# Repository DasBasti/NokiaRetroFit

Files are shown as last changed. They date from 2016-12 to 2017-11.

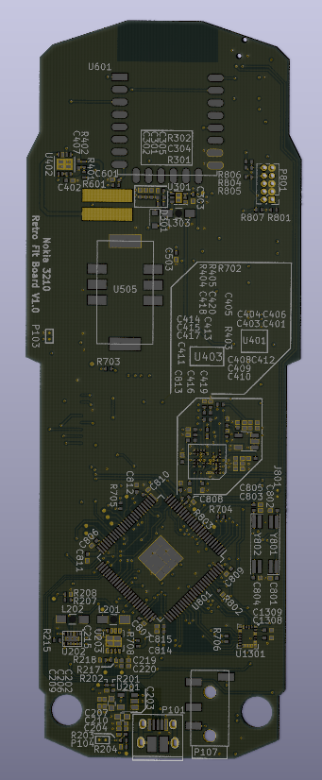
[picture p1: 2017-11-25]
Documentation/Pictures/backside_render_no_componets.png

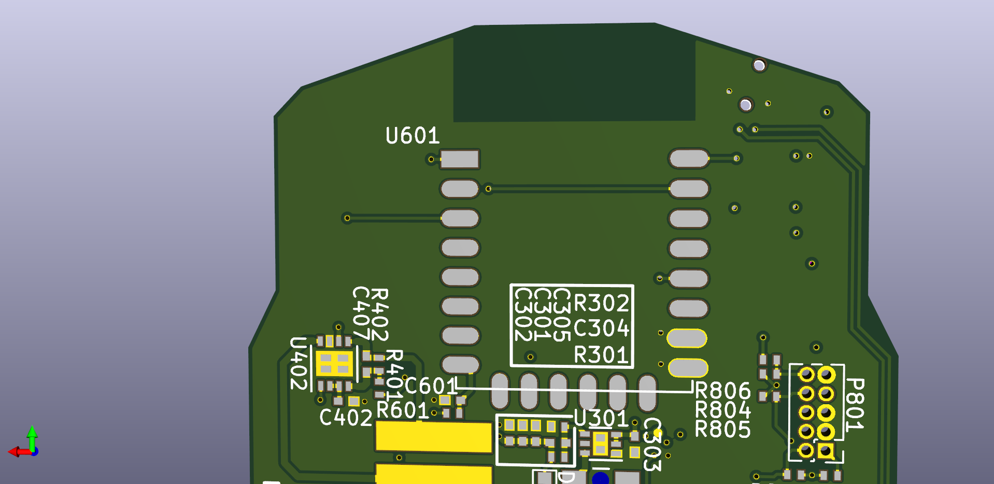
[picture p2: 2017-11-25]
Documentation/Pictures/wifi_part.png

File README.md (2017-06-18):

# Nokia 3210 Retro Fit
Retrofitting a Nokia 3210 with new dual ARM core CPU

* 1GHz dual core CPU
* 1GB DDR3 RAM
* 8GB Memory
* Android N (N7.1.1_1.0.0)

# Status
	[---------100%] BOM generation  
	[--------80%--] Development of schematics / System design  
	[-----50%-----] Pinmuxing of i.MX7  
	[5%-----------] Board layout  
	[0%-----------] Android port  
	[0%-----------] Android applications

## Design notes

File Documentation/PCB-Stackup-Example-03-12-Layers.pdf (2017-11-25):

StackName: iMX6_Rex_V1I1_PCB_12L_VT47_mv | Version: 1 | Revision: | Modification: | Date of Revision: | Editor | Page 1/3
Date: 31/10/2013 | Associated Documents:

Author: DM
Department: IDS
Site: Tewkesbury

Copyright ©

www.polarinstruments.com

Soldermask | 0.020 | SolderMask | 4.100 | 10
1 | Foil | 1, 2, 3 | 0.012 | 0.035 | Foil | 0
VT47-1080 | 0.075 | 0.075 | PREPREG | 4.000
2 | Foil | | 0.009 | 0.032 | Foil | 0
VT47-106 | 0.053 | 0.053 | PREPREG | 4.000
VT47-106 | 0.053 | 0.053 | PREPREG | 4.000
3 | | 4, 5, 6 | 0.018 | 0.035
VT-47 | 0.203 | 0.203 | Core | 4.600
4 | | | 0.018 | 0.018
VT47-2113 | 0.096 | 0.096 | PREPREG | 4.000
5 | | | 0.018 | 0.018
VT-47 | 0.102 | 0.102 | Core | 4.120
6 | | | 0.018 | 0.018
VT47-106 | 0.053 | 0.053 | PREPREG | 4.000
VT47-106 | 0.053 | 0.053 | PREPREG | 4.000
7 | | | 0.018 | 0.018
VT-47 | 0.102 | 0.102 | Core | 4.120
8 | | | 0.018 | 0.018
VT47-2113 | 0.096 | 0.096 | PREPREG | 4.000
9 | | | 0.018 | 0.018
VT-47 | 0.203 | 0.203 | Core | 4.600
10 | | 7, 8, 9 | 0.018 | 0.035
VT47-106 | 0.053 | 0.053 | PREPREG | 4.000
VT47-106 | 0.053 | 0.053 | PREPREG | 4.000
11 | Foil | | 0.009 | 0.032 | Foil | 0
VT47-1080 | 0.075 | 0.075 | PREPREG | 4.000
12 | Foil | 10, 11, 12 | 0.012 | 0.035 | Foil | 0
Soldermask | 0.020 | SolderMask | 4.100 | 10

1.6 +0.0 / -0.0

1 | Coated Microstrip 1B | 1 | 2 | 0 | 0.093 | 0.000 | 0.000 | 55.000 | 55.060 | 10.000
2 | Edge Coupled Coated Microstrip 1B | 1 | 2 | 0 | 0.101 | 0.114 | 0.000 | 90.000 | 90.060 | 10.000
3 | Edge Coupled Coated Microstrip 1B | 1 | 2 | 0 | 0.090 | 0.160 | 0.000 | 100.000 | 100.300 | 10.000
4 | Offset Stripline 1B1A | 3 | 2 | 4 | 0.080 | 0.000 | 0.000 | 55.000 | 53.620 | 10.000

StackName: iMX6_Rex_V1I1_PCB_12L_VT47_mv | Version: 1 | Revision: | Modification: | Date of Revision: | Editor | Page 2/3
Date: 31/10/2013 | Associated Documents:

Author: DM

5 | Edge Coupled Offset Stripline 1B1A | 3 | 2 | 4 | 0.085 | 0.115 | 0.000 | 90.000 | 88.390 | 10.000
6 | Edge Coupled Offset Stripline 1B1A | 3 | 2 | 4 | 0.085 | 0.195 | 0.000 | 100.000 | 98.390 | 10.000
7 | Offset Stripline 1B1A | 10 | 9 | 11 | 0.080 | 0.000 | 0.000 | 55.000 | 53.620 | 10.000
8 | Edge Coupled Offset Stripline 1B1A | 10 | 9 | 11 | 0.085 | 0.115 | 0.000 | 90.000 | 88.390 | 10.000
9 | Edge Coupled Offset Stripline 1B1A | 10 | 9 | 11 | 0.085 | 0.195 | 0.000 | 100.000 | 98.390 | 10.000
10 | Coated Microstrip 1B | 12 | 11 | 0 | 0.093 | 0.000 | 0.000 | 55.000 | 55.060 | 10.000
11 | Edge Coupled Coated Microstrip 1B | 12 | 11 | 0 | 0.101 | 0.114 | 0.000 | 90.000 | 90.060 | 10.000
12 | Edge Coupled Coated Microstrip 1B | 12 | 11 | 0 | 0.090 | 0.160 | 0.000 | 100.000 | 100.300 | 10.000
1 | 12 | Mechanical PTH | 0.000 | None
1 | 2 | Laser PTH | 0.100 | None
2 | 3 | Laser PTH | 0.100 | None
12 | 11 | Laser PTH | 0.100 | None
11 | 10 | Laser PTH | 0.100 | None

StackName: iMX6_Rex_V1I1_PCB_12L_VT47_mv | Version: 1 | Revision: | Modification: | Date of Revision: | Editor | Page 3/3
Date: 31/10/2013 | Associated Documents:

Author: DM

3 | 10 | Mechanical PTH | 0.200 | None

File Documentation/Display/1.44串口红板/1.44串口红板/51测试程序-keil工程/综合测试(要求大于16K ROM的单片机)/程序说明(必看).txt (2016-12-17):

测试程序功能
开机显示中文，英文，图片

修改LCD数据脚连接IO在lcd.h文件中
40*40图片数据和95个ASCCII字符数据和测试汉字取模数据在font.c文件中

/* 
程序默认IO连接方式：
sbit LCD_CS     =P0^0;     //片选	
sbit LCD_AO     =P0^2;	  //数据/命令切换
sbit LCD_SDA    =P1^5;	  //数据
sbit LCD_SCK    =P1^7;	  //时钟
sbit LCD_REST   =P0^1;	  //复位  
*/

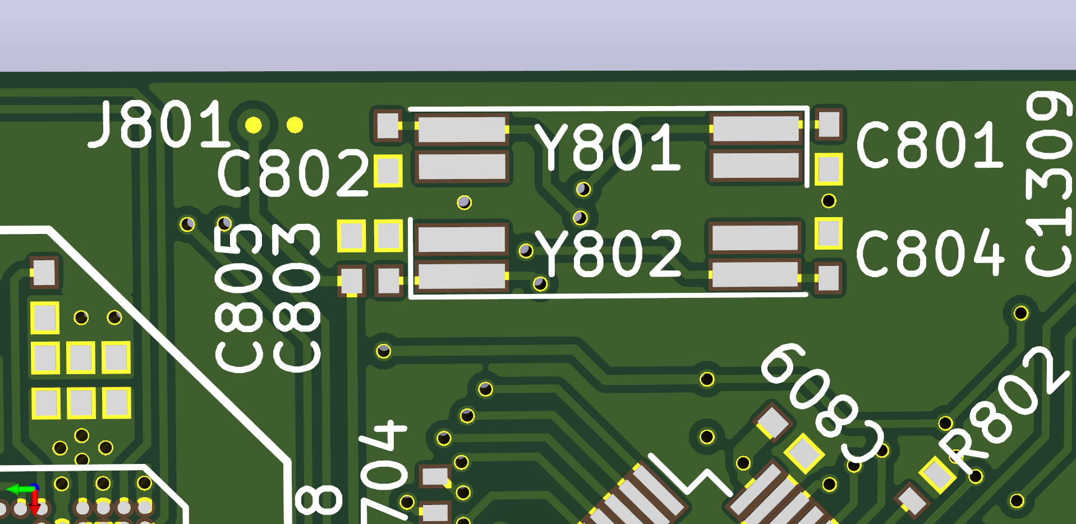
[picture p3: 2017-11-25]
Documentation/Pictures/crystals_part.png

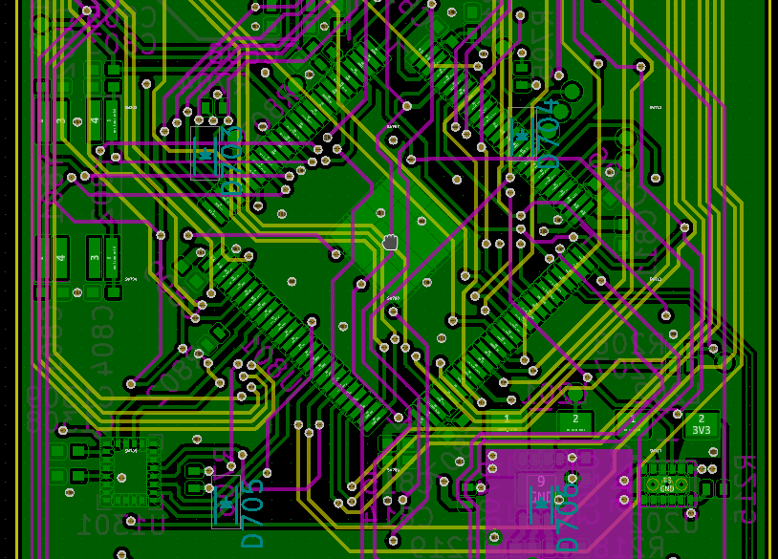
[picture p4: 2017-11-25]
Documentation/Pictures/CPU_part.png

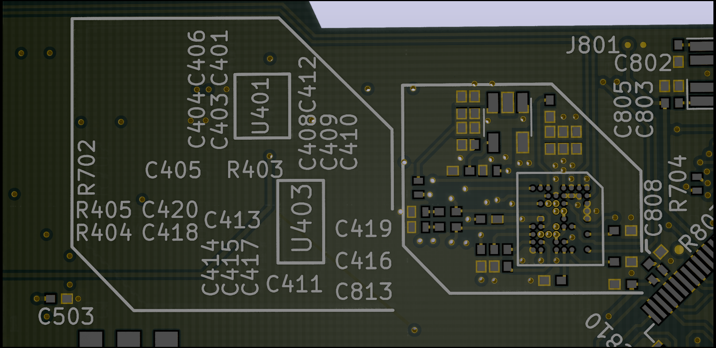
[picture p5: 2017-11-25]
Documentation/Pictures/BGA_part.png

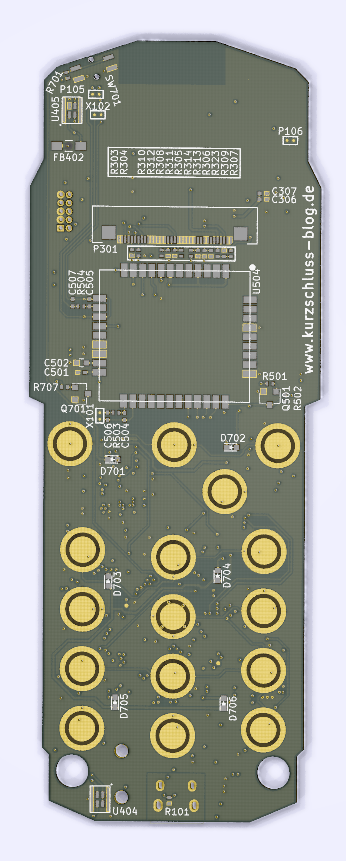
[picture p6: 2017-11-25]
Documentation/Pictures/frontside_render_no_componets.png

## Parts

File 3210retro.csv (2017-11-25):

Id | Designator | Package | Quantity | Designation | Supplier and ref
1 | Y802 | Crystal_SMD_ABM11W_4_D1X_T_-4pin_2.0x1.6mm | 1 | 24MHz
2 | P107 | PJ_320_D | 1 | HEADPHONE
3 | J801 | SolderWirePad_2x_0,8 | 1 | TEST_2P
4 | P103 | SolderWirePad_2x_0,8 | 1 | LIPO
5 | P104 | SolderWirePad_2x_0,8 | 1 | DC
6 | X101 | SolderWirePad_2x_0,8 | 1 | ANT_GPS
7 | X102 | SolderWirePad_2x_0,8 | 1 | ANT_GSM
8 | U505 | SIM | 1 | SIM_SLOT
9 | SW702 | Foil_Button | 1 | C
10 | SW703 | Foil_Button | 1 | 1
11 | SW704 | Foil_Button | 1 | 4ghi
12 | SW705 | Foil_Button | 1 | 7pqrs
13 | SW706 | Foil_Button | 1 | -
14 | SW707 | Foil_Button | 1 | 2abc
15 | SW708 | Foil_Button | 1 | 5jkl
16 | SW709 | Foil_Button | 1 | 8tuv
17 | SW710 | Foil_Button | 1 | UP
18 | SW711 | Foil_Button | 1 | 3def
19 | SW712 | Foil_Button | 1 | 6mno
20 | SW713 | Foil_Button | 1 | 9wxyz
21 | SW714 | Foil_Button | 1 | *+
22 | SW715 | Foil_Button | 1 | DOWN
23 | SW716 | Foil_Button | 1 | 0space
24 | SW717 | Foil_Button | 1 | #up
25 | TP101,TP201,TP202,TP203,TP204,TP205,TP206,TP301,TP501,TP102,TP103,TP104,TP105,TP106,TP107,TP108,TP109,TP110,TP111,TP112,TP114 | TP | 21 | TP
26 | P801 | Pin_Header_Straight_2x05_Pitch1.27mm | 1 | JTAG
27 | SW701 | TS-015A | 1 | SW_PUSH
28 | U404,U405 | MP34DT01_NoGroundRing | 2 | MP34DT01TR
29 | U202 | TPS6274x | 1 | TPS62742
30 | U203 | Texas_S-PVSON-N8_NoThermalVias | 1 | TPS61021A
31 | R807,R215,R323,R701,R802,R803,R804,R805,R205 | R_0402_NoSilk | 9 | 10k
32 | U504 | A7 | 1 | A7
33 | U1301 | LGA-24L_3x3.5mm_Pitch0.43mm | 1 | LSM9DS1
34 | D701,D702,D703,D704,D705,D706 | LED_0603 | 6 | LED
35 | P108 | Rumble_Pads | 1 | RUMBLE
36 | P101 | USB_Micro-B_10103594-0001LF | 1 | USB_OTG
37 | P301 | FFC-05-35 | 1 | SEPS525
38 | U601 | ESP-12E | 1 | ESP-12E
39 | C306,C307,C206,C207,C215,C301,C302,C401,C403,C408,C409,C410,C414,C415,C419,C420,C501,C503,C601,C805,C808,C809,C810,C811,C812,C813,C814,C1309,C421,C423 | C_0402_NoSilk | 30 | 100n
40 | C202,C203 | C_0603 | 2 | 10u
41 | C204,C504,C505,C506,C507 | C_0402_NoSilk | 5 | C
42 | C209,C210 | C_0402_NoSilk | 2 | 1n
43 | C219,C801,C802,C803,C804 | C_0402_NoSilk | 5 | 22p
44 | C220,C305,C815 | C_0402_NoSilk | 3 | 1u
45 | C303 | C_0402_NoSilk | 1 | 4u7C
46 | C304 | C_0402_NoSilk | 1 | 10p
47 | C402,C407,C1308 | C_0402_NoSilk | 3 | 10n
48 | C404,C405,C406 | C_0402_NoSilk | 3 | 470n
49 | C411 | C_0402_NoSilk | 1 | 4u7
50 | C412,C413,C416,C417 | C_0402_NoSilk | 4 | 10u
51 | C418,C422 | C_0402_NoSilk | 2 | 22u
52 | C502 | C_0603 | 1 | 470u
53 | C806,C807 | C_0402_NoSilk | 2 | 2u2
54 | FB402 | Choke_SMD_1206_Standard | 1 | FILTER
55 | L201 | Choke_SMD_1206_Standard | 1 | 4u7 / 3A
56 | L202 | Choke_SMD_1206_Standard | 1 | 2u2
57 | L303 | Choke_SMD_1206_Standard | 1 | 18u
58 | Q501,Q701 | SOT-23 | 2 | MMBF170
59 | R101,R503,R504,R601,R801,R806,R403,R404 | R_0402_NoSilk | 8 | 0
60 | R201,R202,R203,R204,R207,R208,R217,R218 | R_0402_NoSilk | 8 | R
61 | R301 | R_0402_NoSilk | 1 | 2M2
62 | R302 | R_0402_NoSilk | 1 | 162k
63 | R303 | R_0402_NoSilk | 1 | 68k
64 | R304 | R_0402_NoSilk | 1 | 5k1
65 | R305,R306,R307,R310,R311 | R_0402_NoSilk | 5 | 560
66 | R308,R309,R312,R313,R314 | R_0402_NoSilk | 5 | 1k
67 | R401,R402 | R_0402_NoSilk | 2 | 50k
68 | R501 | R_0402_NoSilk | 1 | 22
69 | R502 | R_0402_NoSilk | 1 | 100
70 | R702,R703,R704,R705,R706,R707,R708 | R_0402_NoSilk | 7 | 280
71 | U201 | SOT-23-5 | 1 | MAX1555
72 | U801 | TQFP-100-1EP_14x14mm_Pitch0.5mm | 1 | STM32F756VGTx
73 | D301 | D_0805 | 1 | D_Schottky
74 | U402 | DFN-8-1EP_3x3mm_Pitch0.65mm | 1 | DRV8601
75 | J1101 | microSD_Card_Receptacle_Wuerth_693072010801 | 1 | MICRO_SD_HINGE
76 | Y801 | Crystal_SMD_2012-2pin_2.0x1.2mm | 1 | 32kHz
77 | U301 | DFN-6-1EP_2x2mm_Pitch0.65mm | 1 | TPS61041DBV
78 | R102,R103 | R_0402_NoSilk | 2 | 4k7
79 | U401 | QFN-24-1EP_4x4mm_Pitch0.5mm | 1 | TLV320ADC3101
80 | U403 | QFN-32-1EP_5x5mm_Pitch0.5mm | 1 | TLV320DAC3100
81 | P106 | SolderWirePad_2x_0,8 | 1 | SPEAKER
82 | R206 | R_0603 | 1 | 0

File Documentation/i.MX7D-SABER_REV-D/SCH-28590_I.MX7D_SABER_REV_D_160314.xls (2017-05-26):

MCIMX7D-SABRE Revised: Sunday, March 13, 2016
SOURCE:SCH-28590:SPF-28590 Revision: D
Freescale Semiconductor
6501 William Cannon Drive West
Austin, TX 78735-8598
Bill Of Materials May 5,2016 17:49:32
Item | Quantity | Reference | Value | MFG_NAME01 | Description | MFG_PN01 | Tolerance | Assy_Opt
______________________________________________
1 | 9 | C1,C198,C199,C202,C203, | 100uF |  | TCAP,100UF,+/-10%,6.3V,SMD1210(B)
 |  | C204,C274,C275,C438
2 | 11 | C2,C4,C10,C56,C57,C257, | 22uF |  | CAP,22UF,+80%/-20%,Y5V,10V,SMD0805
 |  | C259,C261,C363,C418,C439
3 | 47 | C3,C20,C21,C22,C29,C58, | 1uF |  | CAP,1UF,+/-10%,X5R,10V,SMD0402
 |  | C59,C61,C194,C220,C221,
 |  | C276,C277,C308,C309,C310,
 |  | C311,C313,C315,C316,C317,
 |  | C318,C324,C326,C327,C329,
 |  | C331,C333,C334,C336,C338,
 |  | C340,C341,C342,C343,C345,
 |  | C377,C382,C387,C392,C393,
 |  | C411,C412,C414,C426,C427,
 |  | C428
4 | 103 | C5,C7,C11,C12,C13,C60, | 220nF |  | CAP,220NF,+/-10%,X5R,10V,SMD0402
 |  | C63,C64,C66,C68,C69,C70,
 |  | C71,C72,C74,C75,C78,C79,
 |  | C80,C81,C82,C83,C84,C86,
 |  | C88,C90,C92,C93,C94,C98,
 |  | C99,C101,C104,C107,C108,
 |  | C110,C117,C118,C119,C122,
 |  | C124,C125,C127,C129,C130,
 |  | C136,C137,C138,C139,C140,
 |  | C142,C143,C144,C145,C146,
 |  | C147,C149,C150,C151,C152,
 |  | C153,C154,C155,C157,C158,
 |  | C159,C160,C161,C162,C163,
 |  | C165,C166,C167,C168,C169,
 |  | C170,C171,C173,C174,C175,
 |  | C176,C177,C178,C179,C190,
 |  | C191,C192,C237,C241,C245,
 |  | C265,C278,C279,C280,C284,
 |  | C357,C376,C378,C380,C381,
 |  | C388,C389,C408
5 | 88 | C6,C24,C28,C30,C37,C42, | 100nF |  | CAP,100NF,+/-10%,X5R,10V,SMD0402
 |  | C46,C50,C52,C141,C181,
 |  | C182,C184,C185,C186,C187,
 |  | C196,C201,C206,C207,C208,
 |  | C209,C210,C211,C212,C213,
 |  | C216,C217,C222,C223,C227,
 |  | C229,C230,C231,C240,C246,
 |  | C247,C248,C249,C250,C251,
 |  | C253,C256,C258,C260,C262,
 |  | C264,C266,C267,C268,C271,
 |  | C300,C320,C322,C347,C348,
 |  | C351,C352,C359,C360,C361,
 |  | C365,C367,C368,C379,C384,
 |  | C385,C396,C404,C405,C407,
 |  | C409,C410,C415,C417,C419,
 |  | C444,C446,C448,C450,C451,
 |  | C453,C456,C457,C458,C459,
 |  | C460,C461
6 | 31 | C8,C9,C14,C16,C32,C33, | 22uF |  | CAP,22UF,+/-20%,X5R,6.3V,SMD0603
 |  | C34,C35,C38,C39,C40,C41,
 |  | C44,C45,C54,C55,C65,C73,
 |  | C85,C148,C156,C164,C172,
 |  | C180,C215,C225,C263,C344,
 |  | C346,C362,C390
7 | 8 | C15,C18,C394,C429,C430, | 10nF |  | CAP,10NF,+/-10%,X7R,25V,SMD0402
 |  | C431,C432,C433
8 | 2 | C17,C19 | 560pF |  | CAP,560PF,+/-5%,C0G,50V,SMD0402
9 | 26 | C23,C26,C49,C67,C76,C77, | 2.2uF |  | CAP,2.2UF,+/-20%,X5R,6.3V,SMD0402
 |  | C87,C89,C91,C95,C97,C100,
 |  | C109,C111,C115,C116,C120,
 |  | C126,C128,C131,C238,C254,
 |  | C255,C356,C374,C452
10 | 29 | C25,C27,C36,C43,C47,C48, | 4.7uF |  | CAP,4.7UF,+/-10%,X5R,10V,SMD0603
 |  | C51,C53,C96,C183,C188,
 |  | C189,C193,C200,C205,C228,
 |  | C232,C233,C235,C269,C270,
 |  | C272,C273,C354,C355,C386,
 |  | C445,C447,C449
11 | 4 | C31,C112,C113,C114 | 470nF |  | CAP,470NF,+/-10%,X5R,10V,SMD0402
12 | 16 | C62,C214,C218,C219,C224, | 10uF |  | CAP,10UF,+/-20%,X5R,6.3V,SMD0603
 |  | C252,C307,C319,C323,C325,
 |  | C328,C330,C332,C335,C337,
 |  | C413
13 | 23 | C102,C103,C105,C106,C197, | 18pF |  | CAP,18PF,+/-5%,C0G,50V,SMD0402
 |  | C243,C244,C349,C350,C366,
 |  | C391,C397,C398,C399,C400,
 |  | C401,C406,C420,C421,C422,
 |  | C423,C434,C435
14 | 4 | C121,C123,C358,C375 | 10uF |  | CAP,10UF,+/-10%,X5R,10V,SMD0603
15 | 3 | C195,C321,C416 | 47uF |  | CAP,47UF,+/-20%,X5R,6.3V,SMD0805
16 | 3 | C226,C239,C298 | 4.7uF |  | CAP,4.7UF,+/-10%,X5R,16V,SMD0603
17 | 5 | C242,C301,C302,C353,C395 | 100nF |  | CAP,100NF,+/-10%,X5R,25V,SMD0402
18 | 2 | C281,C282 | 56pF |  | CAP,56PF,+/-1%,C0G,50V,SMD0402 |  | 1%
19 | 3 | C283,C369,C370 | 1nF |  | CAP,1NF,+/-10%,X7R,50V,SMD0402
20 | 1 | C299 | 100uF |  | TCAP,100UF,+/-20%,10V,SMD1210(B)
21 | 1 | C383 | 33nF |  | CAP,33NF,+/-10%,X7R,16V,SMD0402
22 | 2 | C402,C403 | 10pF |  | CAP,10PF,+/-5%,C0G,50V,SMD0402
23 | 1 | C454 | 2.2uF |  | CAP,2.2UF,+/-10%,X5R,50V,SMD0805
24 | 1 | C455 | 100nF |  | CAP,100NF,+/-10%,X7R,50V,SMD0603
25 | 4 | D1,D6,D9,D11 | Green |  | LED,Brilliant Green,Water Clear,20mA,SMD0805
26 | 5 | D2,D7,D8,D10,D23 | RED |  | LED,Brilliant Red,Water Clear,20mA,SMD0805
27 | 6 | D3,D4,D16,D20,D25,D26 | 1N5819HW-7-F |  | Diode,Schottky Diode,1N5819HW-7-F,40V,1A,SOD-123,SMD
28 | 1 | D5 | ORG |  | LED,Brilliant Orange,Water Clear,20mA,SMD0805
29 | 2 | D12,D13 | LED |  | LED,Brilliant Orange,Water Clear,20mA,SMD0805
30 | 3 | D14,D15,D24 | BAT54A |  | Diode,Schottky Diode,BAT54AWT1G,30V,200mA,SOT-323
31 | 1 | D17 | MM5Z5V1ST1G |  | Diode,DIODE ZENER 5.1V 200MW SOD523
32 | 1 | D22 | BAT54S |  | Diode,Schottky Barrier(Double) Diodes,BAT54S,30V,200mA,SOT-23,SMD
33 | 1 | FL1 | LFB182G45SG9A272 |  | FILTER,BANDPASS 2.4GHZ WLAN,0603(5 pads),SMD
34 | 1 | F1 | FUSE |  | Fuse,F1206FA4000V032T,32V,4A,Fast Acting,0.022ohm,SMD1206
35 | 1 | JP1 | HTMS-103-02-G-S |  | Connector,Pin Header,Straight,Male,1x3Pin,1.27MM pitch,2.54,3.05,Gold Flash 10u,black,DIP
36 | 1 | J1 | CONN_DCPOWER |  | Connector,DC Jack,Right Angle,3Pin,2.0MM Center Pin,Tin Plated,Black,DIP
37 | 1 | J2 | CONN_BATIN |  | Connector,PH Series PCB Header,Straight,Male,1x2Pin,2.0MM pitch,Tin Plated, white,DIP
38 | 1 | J3 | CONN_BAT |  | Connector,Battery Holder for CR1220,brown,SMD
39 | 3 | J4,J5,J10 | CONN_Coaxial |  | Connector,Coaxial Connector,U.FL-R-SMT-1,6GHZ,SMD
40 | 1 | J6 | CONN_SD |  | Connector,SD Card CONN with detect switch, Gold Flash 3u,white,SMD
41 | 1 | J7 | CONN_SIM |  | Connector,SIM Card CONN,Gold Flash 1u,Black,16.35x15.7x2.6mm,SMD
42 | 1 | J8 | CONN_PCIe |  | Connector,MiniPCI Card CONN 2x26,Gold Flash 1u,Black,SMD
43 | 1 | J9 | CONN_HDMI |  | Connector,HDMI A port,FeMale,19 Position,Right Angle,Gold Flash 3u,black,SMD
44 | 2 | J11,J25 | CONN_USB |  | Connector,MicroUSB AB port,5 Position,Right Angle,Gold Flash 1u, black,SMD
45 | 1 | J12 | CONN_JTAG |  | Connector,Pin Header,Straight,Male,2x5Pin,1.27MM pitch,2.9mm,,Gold Flash 1u,black,SMD
46 | 1 | J13 | CONN_EPD | SAMTEC | Connector,Board to Baord, Female 120Pin,0.8MM Pitch, Gold Flash 10u,black,SMD | QSH-060-01-L-D-A
47 | 1 | J14 | CONN_LCD |  | Connector,FPC Connector,Right Angle,50Pin,0.5MM Pitch,Flip-Lock Type,Bottom Contact,2.0MM Height,Tin Plated, white,SMD
48 | 1 | J15 | CONN_HP |  | Connector,Audio Jack,Right Angle,3.5MM Plug Diameter,Gold Flash 1u,Green,DIP
49 | 1 | J16 | CONN_MIC |  | Connector,Audio Jack,Right Angle,3.5MM Plug Diameter,Gold Flash 1u,Pink,DIP
50 | 1 | J17 | CONN_SPEAKER | Townes | Connector,Pin Header,Straight,Male,1x4Pin,2.54MM pitch,6.06,3.00,Gold Flash 1u,black,DIP | P101-1*04SGF-116A-NG
51 | 1 | J18 | CONN_SMARTCARD |  | Connector,FPC Connector,Right Angle,14Pin,0.5MM Pitch,Flip-Lock Type,Bottom Contact,1.2MM Height,Tin Plated, white,SMD
52 | 1 | J19 | CONN_CAN |  | Connector,D-SUB with screwlock,Male,9 Position,Right Angle,Gold Flash,black,DIP
53 | 1 | J20 | CONN_MFI |  | Connector,Pin Socket,Straight,Female,2x5Pin,2.54MM pitch,8.5,3.00,Gold Flash 1u, black,DIP
54 | 1 | J22 | CONN_ADC |  | Connector,Pin Header,Straight,Male,2x4Pin,2.54MM pitch,5.80,,Gold Flash 1u, black,SMD
55 | 1 | J26 | CONN_USB |  | Connector,USB A port,4 Position,Right Angle Flag,Gold Flash 1u,white,DIP
56 | 2 | J27,J28 | CONN_RJ45 |  | Connector,RJ45 Jack with integrated magnetics and G/Y leds,Right Angle,1000M,Top contact,Gold Flash
57 | 1 | J29 | CONN_CSI |  | BTB Connector,Socket,AXT530124,30Pin,0.4MM Pitch,without bosses,Height 1.0mm,Ni+Au,panasonic,SMD
58 | 1 | J30 | CONN_DSI |  | BTB Connector,socket,Right Angle,24Pin,0.4MM Pitch,1.5MM Height,Au,Black,SMD
59 | 1 | J31 | CONN_TAMPER |  | Connector,Pin Header,Straight,Male,2x10Pin,1.27MM pitch,Gold Flash 30u,black,SMD
60 | 2 | J32,J33 | CONN_MikroBUS |  | Connector,Pin Socket,Straight,Female,1x8Pin,2.54MM pitch,8.5,3.2,Gold Flash 1u, black,DIP
61 | 6 | J36,J37,J38,J39,J40,J41 | CONN_JUMPER |  | Connector,Pin Header,Straight,Male,1x2Pin,1.27MM pitch,3,2,Gold Flash 1u, black,DIP
62 | 2 | L1,L2 | 2.2uH |  | Power Inductor,Magnetic shielded,2.2uH,IRMS=7A,ISAT=14A,0.02ohms,7.3x6.6x3mm,SMD
63 | 4 | L3,L4,L5,L7 | 1.5uH |  | Inductor ,1.5uH,60mOhms,3.5A +/-20% 2.5x2.0x1.2mm OPN:DFE252012P-1R5M=P2
64 | 1 | L6 | 2.2uH |  | Inductor,2.2uH 84mOhms3.0A +/-20% 2.5x2.0x1.2mm OPN:DFE252012P-2R2M=P2
65 | 12 | L8,L11,L12,L13,L50,L51, | 120 OHM@100MHZ |  | Ferrite Bead,120ohm@100MHz,+/-25%,1300mA,90mohm,SMD0402
 |  | L52,L63,L64,L65,L66,L68
66 | 7 | L10,L40,L41,L59,L60,L61, | WCM-2012-900T |  | Common Choke,90ohm@100MHz/20°C,±25%,450mA,0.3ohm,SMD0508
 |  | L62
67 | 24 | L14,L15,L19,L20,L21,L22, | 120 OHM@100MHZ |  | Ferrite Bead,120ohm@100MHz,+/-25%,1300mA,90mohm,SMD0402
 |  | L25,L26,L27,L28,L29,L30,
 |  | L31,L39,L42,L43,L45,L46,
 |  | L47,L48,L49,L53,L57,L58
68 | 4 | L16,L17,L55,L56 | 1nH |  | Inductor,1nH,Ir=400mA,RF=6GHz,Rdc=0.1 ohm,SMD0402
69 | 2 | L18,L67 | 2.2uH |  | Inductor,2.2uH,Ir=1.3A,RF=40MHz,Rdc=100m ohm,SMD1008
70 | 2 | L44,L54 | 4.7uH |  | Inductor,4.7uH,Ir=120mA,+/-20%,0.455ohm,SMD0805
71 | 4 | MG1,MG2,MG3,MG4 | MGX |  | STANDOFF,PHILIP FEMALE, ROUND HEAD,M2-0.4*5,COPPER ALLOY
72 | 3 | Q2,Q32,Q34 | AON3419 |  | Mosfet,P-Channel,AON3419,-30V,-10A,SOIC-8,SMD
73 | 8 | Q5,Q7,Q16,Q22,Q25,Q29, | 2N7002 |  | Mosfet,N-Channel,2N7002,60V,115mA,SOT-23,SMD
 |  | Q30,Q31
74 | 5 | Q6,Q10,Q13,Q21,Q24 | AO3407A |  | Mosfet,P-Channel,AO3407A,-30V,-4.3A,SOT-23,SMD
75 | 1 | Q8 | MMBT3904 |  | Transistor,NPN,MMBT3904,40V,200MA,SOT-23,SMD
76 | 1 | Q17 | MMBT2907 |  | Transistor,PNP,MMBT2907A-7-F,60V,600MA,SOT-23,SMD
77 | 1 | Q35 | BCM857BS |  | Transistor,DUAL PNP,BCM857BS,45V,100MA,SOT-363,SMD
78 | 1 | Q36 | DMN2005K-7 |  | Mosfet,N-Channel,2N7002,60V,115mA,SOT-23,SMD
79 | 6 | RN13,RN14,RN15,RN16,RN17, | 33R |  | RES 4 arrays,33R, +/-5%,1/16W,SMD0408
 |  | RN18
80 | 5 | RN19,RN20,RN21,RN22,RN23 | 10K |  | RES 4 Arrays,10K,+/-5%,1/16W,SMD0408
81 | 13 | R1,R4,R134,R161,R162, | 1K |  | RES,1K,+/-5%,1/16W,SMD0402
 |  | R166,R167,R295,R296,R309,
 |  | R310,R347,R623
82 | 26 | R6,R8,R15,R18,R35,R75, | 100K |  | RES,100K,+/-1%,1/16W,SMD0402
 |  | R152,R153,R154,R155,R156,
 |  | R254,R256,R280,R348,R354,
 |  | R539,R547,R549,R550,R551,
 |  | R561,R570,R584,R611,R614
83 | 89 | R9,R11,R28,R68,R87,R88, | 10K |  | RES,10K,+/-5%,1/16W,SMD0402
 |  | R89,R92,R93,R94,R97,R98,
 |  | R99,R100,R101,R104,R105,
 |  | R108,R135,R138,R139,R148,
 |  | R165,R168,R169,R170,R225,
 |  | R226,R228,R230,R232,R234,
 |  | R236,R239,R241,R242,R244,
 |  | R252,R253,R255,R257,R262,
 |  | R263,R275,R282,R294,R327,
 |  | R330,R331,R332,R333,R334,
 |  | R335,R336,R351,R353,R361,
 |  | R362,R363,R364,R367,R386,
 |  | R387,R472,R477,R489,R490,
 |  | R493,R498,R537,R543,R548,
 |  | R553,R602,R603,R604,R609,
 |  | R610,R612,R613,R615,R621,
 |  | R622,R628,R630,R631,R636,
 |  | R637,R640
84 | 1 | R10 | 75K |  | RES,75K,+/-1%,1/16W,SMD0402 |  | 1%
85 | 2 | R12,R16 | 12K7 |  | RES,12K7,+/-1%,1/16W,SMD0402
86 | 2 | R13,R17 | 24K |  | RES,24K,+/-1%,1/16W,SMD0402 |  | 1%
87 | 1 | R14 | 88K7 |  | RES,88K7,+/-1%,1/16W,SMD0402 |  | 1%
88 | 14 | R19,R90,R91,R127,R128, | 470R |  | RES,470R,+/-1%,1/16W,SMD0402
 |  | R129,R157,R264,R266,R267,
 |  | R268,R269,R270,R556
89 | 2 | R20,R24 | 0R |  | RES,0R,+/-5%,1/2W,SMD1206
90 | 189 | R23,R30,R31,R32,R45,R46, | 0R |  | RES,0R,+/-5%,1/16W,SMD0402
 |  | R65,R69,R76,R85,R102,
 |  | R117,R118,R119,R120,R124,
 |  | R125,R136,R147,R163,R171,
 |  | R172,R180,R181,R183,R184,
 |  | R185,R186,R187,R188,R189,
 |  | R190,R191,R192,R193,R194,
 |  | R243,R250,R251,R258,R261,
 |  | R265,R281,R283,R284,R285,
 |  | R299,R300,R301,R302,R303,
 |  | R307,R311,R312,R313,R314,
 |  | R315,R316,R317,R318,R319,
 |  | R320,R321,R325,R326,R329,
 |  | R339,R340,R341,R350,R352,
 |  | R355,R365,R368,R369,R370,
 |  | R371,R372,R373,R374,R375,
 |  | R388,R389,R390,R391,R392,
 |  | R393,R394,R395,R396,R397,
 |  | R398,R399,R400,R401,R402,
 |  | R403,R404,R405,R406,R407,
 |  | R408,R409,R410,R411,R412,
 |  | R413,R415,R416,R417,R419,
 |  | R420,R421,R422,R423,R424,
 |  | R425,R426,R427,R428,R429,
 |  | R430,R431,R432,R433,R434,
 |  | R435,R476,R478,R479,R480,
 |  | R481,R482,R483,R484,R485,
 |  | R486,R487,R488,R496,R497,
 |  | R499,R500,R501,R502,R503,
 |  | R504,R505,R506,R507,R508,
 |  | R509,R510,R512,R514,R515,
 |  | R516,R518,R519,R520,R521,
 |  | R523,R524,R554,R555,R557,
 |  | R558,R559,R560,R565,R566,
 |  | R567,R568,R569,R571,R582,
 |  | R583,R595,R596,R617,R618,
 |  | R619,R620,R629,R632,R633,
 |  | R641,R642,R643
91 | 6 | R27,R132,R142,R143,R249, | 47K |  | RES,47K,+/-1%,1/16W,SMD0402
 |  | R616
92 | 14 | R33,R34,R59,R60,R61,R62, | 2K2 |  | RES,2K2,+/-5%,1/16W,SMD0402
 |  | R63,R64,R107,R182,R491,
 |  | R538,R580,R581
93 | 1 | R36 | 4.75M |  | RES, 4.75 M, 1%, 1/16 W,0402,SMD
94 | 3 | R38,R164,R349 | 1M |  | RES,1M,+/-5%,1/16W,SMD0402
95 | 47 | R39,R40,R41,R42,R43,R44, | 22R |  | RES,22R,+/-5%,1/16W,SMD0402
 |  | R112,R158,R160,R286,R287,
 |  | R288,R289,R290,R291,R342,
 |  | R436,R437,R438,R439,R440,
 |  | R441,R442,R443,R444,R445,
 |  | R446,R447,R448,R449,R450,
 |  | R451,R452,R453,R454,R455,
 |  | R456,R457,R458,R459,R468,
 |  | R469,R470,R471,R473,R474,
 |  | R475
96 | 2 | R66,R70 | 200R |  | RES,200R,+/-1%,1/16W,SMD0402 |  | 1%
97 | 2 | R67,R71 | 470K |  | RES,470K,+/-5%,1/16W,SMD0402
98 | 3 | R80,R279,R540 | 4K7 |  | RES,4K7,+/-1%,1/16W,SMD0402 |  | 1%
99 | 5 | R81,R82,R83,R84,R86 | 240R |  | RES,240R,+/-1%,1/16W,SMD0402 |  | 1%
100 | 25 | R95,R96,R106,R110,R111, | 33R |  | RES,33R,+/-5%,1/16W,SMD0402
 |  | R137,R151,R177,R178,R179,
 |  | R337,R338,R356,R357,R358,
 |  | R359,R360,R492,R590,R591,
 |  | R592,R593,R597,R598,R601
101 | 3 | R103,R245,R246 | 60R4 |  | RES,60R4,+/-1%,1/8W,SMD0805
102 | 1 | R133 | 5K1 |  | RES,5K1,+/-1%,1/16W,SMD0402
103 | 33 | R140,R141,R144,R145,R174, | 4K7 |  | RES,4K7,+/-1%,1/16W,SMD0402
 |  | R175,R195,R196,R197,R199,
 |  | R203,R204,R205,R206,R207,
 |  | R208,R209,R210,R211,R212,
 |  | R213,R214,R215,R216,R217,
 |  | R218,R272,R273,R276,R277,
 |  | R278,R638,R639
104 | 1 | R146 | 15K |  | RES,15K,+/-5%,1/16W,SMD0402
105 | 2 | R159,R271 | 1K5 |  | RES,1K5,+/-1%,1/16W,SMD0402 |  | 1%
106 | 1 | R176 | 10R |  | RES,10R,+/-5%,1/16W,SMD0402
107 | 1 | R274 | 6K04 |  | RES,6K04,+/-1%,1/16W,SMD0402
108 | 1 | R323 | 52K3 |  | RES,52K3,+/-1%,1/16W,SMD0402
109 | 1 | R324 | 30K1 |  | RES,30K1,+/-1%,1/16W,SMD0402
110 | 25 | R343,R344,R345,R346,R460, | 49R9 |  | RES,49R9,+/-1%,1/16W,SMD0402
 |  | R461,R462,R463,R464,R465,
 |  | R466,R467,R495,R525,R526,
 |  | R527,R528,R529,R530,R531,
 |  | R532,R533,R534,R535,R536
111 | 1 | R366 | 33K |  | RES,33K,+/-5%,1/16W,SMD0402
112 | 1 | R494 | 560R |  | RES,560R,+/-1%,1/16W,SMD0402 |  | 1%
113 | 2 | R605,R607 | 140R |  | RES,140R,+/-1%,1/16W,SMD0402 |  | 1%
114 | 2 | R606,R608 | 75R |  | RES,75R,+/-1%,1/16W,SMD0402 |  | 1%
115 | 1 | R624 | 374K |  | RES,374K,+/-1%,1/16W,SMD0402
116 | 1 | R625 | 12K |  | RES,12K,+/-1%,1/16W,SMD0402
117 | 1 | R626 | 30R |  | RES,30R, +/-1%,1/10W,SMD0603
118 | 2 | R634,R635 | 49.9R 1% |  | RES,49R9,+/-1%,1/16W,SMD0402
119 | 1 | SW1 | SS-12D01VG2-566 |  | Switch, Slide Switches SPDT,Straight,black housing,black plunger,8.6*4.3*4.7MM,DIP
120 | 1 | SW2 | DSHP08TSGER |  | Switch, DIP Switches SPST 8 switch sections,8 Position,1.27MM Pitch,black housing,white plunger,SMD
121 | 1 | SW3 | GDH02S04 |  | Switch, DIP Switches,2 Position,1.27MM Pitch,black housing,white plunger,SMD
122 | 4 | S1,S2,S3,S4 | B3S-1000 |  | Switch,Tacticle,160gf,Metal housing,white plunger, 6*6*4.3MM,SMD
123 | 64 | TP1,TP2,TP3,TP4,TP5,TP6, | tp30 |  | TEST POINT PAD 0.5MM DIA SMT, NO PART TO ORDER |  |  | DNP
 |  | TP7,TP8,TP9,TP10,TP11,
 |  | TP12,TP13,TP14,TP15,TP16,
 |  | TP17,TP18,TP19,TP20,TP21,
 |  | TP22,TP23,TP24,TP25,TP26,
 |  | TP27,TP29,TP30,TP31,TP32,
 |  | TP33,TP34,TP35,TP36,TP37,
 |  | TP39,TP40,TP41,TP42,TP43,
 |  | TP44,TP45,TP46,TP47,TP48,
 |  | TP49,TP50,TP51,TP52,TP53,
 |  | TP54,TP55,TP56,TP57,TP67,
 |  | TP68,TP69,TP70,TP71,TP72,
 |  | TP73,TP74,TP75
124 | 8 | TP58,TP60,TP61,TP62,TP63, | tp30 |  | Connector,Test Point,5016,PAD:4.7*3.4mm,SMD |  |  | DNP
 |  | TP64,TP65,TP66
125 | 6 | TVS1,TVS2,TVS3,TVS4,TVS5, | B72590D0050H160 | On Semiconductor | Diode,TVS,B72590D0050H160,5.6V,0402,SMD | ESD9B3.3ST5G
 |  | TVS6
126 | 2 | U2,U3 | RT8070ZSP |  | IC,4A, 2MHz, Synchronous Step-Down Converter,RT8070ZSP,SO-8,SMD
127 | 1 | U4 | PC32PF3000A1EP |  | IC,PMIC design for imx7,QFN48
128 | 1 | U7 | PCIMX7D7DVM10SA_541BGA_V2 |  | ARM Cortex A7 MPCore? Processor
129 | 2 | U8,U9 | MT41K256M16HA-125 | MICRON | IC,DDR3L 4Gb(256Mbx16) SDRAM,MT41K256M16HA-125:E,FPGA96,SMD | MT41K128M16JT-125:K
130 | 1 | U10 | MTFC8GACAEAM-1M WT |  | IC,8GB MultiMediaCard (MMC) controller and NAND Flash,MTFC8GACAEAM-1M WT,153-ball VFBGA,SMD
131 | 1 | U11 | MX25L51245GZ2I-10G |  | IC,Quad Serial NOR Flash Memory 512Mb,MX25L51245G,SOIC-8,SMD
132 | 1 | U12 | MT29F32G08CBADB |  | IC,32Gb Asynchronous/Synchronous NAND,TSOP48
133 | 1 | U13 | SiI9022ACNU |  | HDMI Transmitter supports the High Definition Multimedia Interface (HDMI)
134 | 1 | U14 | ME6211C12M5G |  | IC,High Speed LDO Regulators, Low ESR Cap. Compatible, ME6211 Series,ME6211C12M5G,SOT-23-5,SMD
135 | 1 | U15 | CM2020-00TR |  | HDMI transmitter port protection and interface device,TSSOP38,ON
136 | 1 | U16 | LBEH5HMZPC-TEMP |  | IC,W-LAN+Bluetooth+FM Combo Module,LBEH5HMZPC-TEMP,SMD
137 | 2 | U17,U19 | SN74LVC2G126DCUT |  | IC,Dual bus buffer gate with 3-state outputs,DCU,SMD
138 | 1 | U18 | FT2232D |  | IC,Dual USB to Serial UART/FIFO,FT2232D,48-Pin LQFP,SMD
139 | 1 | U20 | FXAS21002CQR1 |  | IC,Xtrinsic 3-Axis Digital Angular Rate Gyroscope,FXAS21002CQR1,QFN24,SMD
140 | 1 | U21 | FXOS8700CQR1 |  | IC,6-Axis Sensor with Integrated Linear Accelerometer and Magnetometer,FXOS8700CQR1,QFN16,SMD
141 | 1 | U22 | MPL3115A2 |  | IC,PRESSURE SENSOR, 20-110KPA,MPL3115A2,LGA,,SMD
142 | 1 | U23 | TSC2046IPWR |  | IC,Low-Voltage I/O TOUCH SCREEN CONTROLLER,TSC2046IPWR,TSSOP-16,SMD
143 | 1 | U24 | WM8960CGEFL/V |  | IC,Stereo CODEC with Speaker Drivers and Headphone Drivers,QFN32,SMD
144 | 1 | U25 | MC33901WEF |  | IC,high speed CAN transceivers,Automatic adaptation to 3.3 or 5.0 V MCU communication,SOIC8
145 | 2 | U27,U28 | USBLC6-2SC6Y |  | Diode,TVS,USBLC6-2SC6Y,5.25V,SOT23-6L,SMD
146 | 1 | U30 | SP2526A-1EN-L |  | IC,Power Switch ICs - USB 2-CH Active High,SP2526A-1EN-L,NSOIC-8,SMD
147 | 1 | U31 | BCM54220B0KFBG |  | IC,Dual lan phy,FPGA-144,SMD
148 | 1 | U33 | ME6211C18M5G |  | IC,500mA High Speed LDO Regulators, Low ESR Cap. low noise,ME6211C18M5G,SOT23-5,SMD
149 | 1 | U35 | TPS73701DRB |  | IC,Single Output LDO, 1A, Adj. (1.2 to 5.0V), Reverse Current Protection,TPS73701DRB,SON8,SMD
150 | 1 | U36 | SN74AVC16T245DGGR |  | IC, 16-BIT DUAL-SUPPLY BUS TRANSCEIVER WITH CONFIGURABLE VOLTAGE TRANSLATION AND 3-STATE OUTPUTS, SN74AVC16T245DGGR, TSSOP-48, SMD
151 | 1 | U37 | TPS3808G30DBVT |  | IC,Low Quiescent Current, Programmable-Delay Supervisory Circuit,TPS3808G30DBVT,SOT-23,SMD
152 | 1 | U38 | 74LV595PW |  | IC,8-bit serial-in/serial-out or parallel-out shift register; 3-state;NXP
153 | 1 | U39 | SN74LV1T126DCKR |  | IC,Single Power Supply Single Buffer Gate with 3-State Output CMOS Logic Level Shifter;TI
154 | 1 | U40 | LMV358MX |  | IC,Rail-to-Rail Output Operational Amplifiers,LMV358MX,SOIC-8,SMD
155 | 1 | U41 | 24AA512-I/SN |  | EEPROM,64KB,1.8V,SOIC-8,SMD
156 | 1 | U42 | PI6CFGL201BZDIEX |  | Clock,2-Output Low Power PCIE Gen 1-2-3 Clock Generator,TQFN-24,SMD
157 | 1 | U43 | AAT1239ITP-1-T1 |  | IC,40V Step-Up Converter for 4 to 10 White LEDs,AAT1239ITP-1-T1,TSOPJW-12,SMD
158 | 1 | U44 | TLV73310PDBVT
159 | 1 | U45 | TXS0102DCUR |  | IC,2-BIT BIDIRECTIONAL VOLTAGE-LEVEL TRANSLATO,TXS0102DCUR,8-X2SON,SMD
160 | 3 | X1,X2,X3 | 32.768KHz |  | Oscillator,1631-L3275-BTGQYA,32.768KHz,50ppm,1.8V,3225,SMD
161 | 1 | X4 | 24MHz |  | Oscillator, ASTMLPE-18-24.000MHz-LJ-E-T,24MHz,
+/-20ppm,1.8V,3225,SMD
162 | 1 | Y1 | CM7V-T1A |  | Crystal,CM7V-T1A,32.768KHz,+/-20PPM,12.5PF,3.2 x1.5MM,SMD
163 | 1 | Y2 | 5XBB24000202TF50Q3 |  | Crystal,5XBB24000202TF50Q3,24MHz,+/-20PPM,20PF,5032-2 pads,SMD
164 | 1 | Y3 | 25MHZ |  | Crystal,S,25MHz,30ppm,18PF,3225-4,SMD
165 | 1 | Y4 | 7D06000202BTAF70Q3 |  | Crystal,7D06000202BTAF70Q3,6MHz,+/-20PPM,20PF,HC-49SMD,SMD
166 | 1 | Y8 | 5XBB25000202TF40Q3 |  | Crystal,5XBB25000202TF40Q3,25MHz,+/-20PPM,20PF,5032-2 pads,SMD
167 | 7 | Z31,Z36,Z37,Z38,Z39,Z40, | CONN_Shunt |  | SHUNT,1.27mm,SP JUMPER,118H,AU,DIP
 |  | Z41

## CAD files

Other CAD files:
Documentation/Display/1.44串口红板/1.44串口红板/51测试程序-keil工程/基本刷屏测试/main.OBJ
Documentation/Display/1.44串口红板/1.44串口红板/51测试程序-keil工程/综合测试(要求大于16K ROM的单片机)/综合测试(要求大于16K ROM的单片机)/main.OBJ
Documentation/Display/1.44串口红板/1.44串口红板/51测试程序-keil工程/基本刷屏测试/LCD.obj
Documentation/Display/1.44串口红板/1.44串口红板/51测试程序-keil工程/综合测试(要求大于16K ROM的单片机)/综合测试(要求大于16K ROM的单片机)/STARTUP.OBJ
Documentation/Display/1.44串口红板/1.44串口红板/51测试程序-keil工程/基本刷屏测试/STARTUP.OBJ
Documentation/Display/1.44串口红板/1.44串口红板/51测试程序-keil工程/综合测试(要求大于16K ROM的单片机)/综合测试(要求大于16K ROM的单片机)/touch.obj
Documentation/Display/1.44串口红板/1.44串口红板/51测试程序-keil工程/基本刷屏测试/font.obj
Documentation/Display/1.44串口红板/1.44串口红板/51测试程序-keil工程/综合测试(要求大于16K ROM的单片机)/综合测试(要求大于16K ROM的单片机)/sys.obj
Documentation/Display/1.44串口红板/1.44串口红板/51测试程序-keil工程/基本刷屏测试/sys.obj
Documentation/Display/1.44串口红板/1.44串口红板/51测试程序-keil工程/综合测试(要求大于16K ROM的单片机)/综合测试(要求大于16K ROM的单片机)/font.obj
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

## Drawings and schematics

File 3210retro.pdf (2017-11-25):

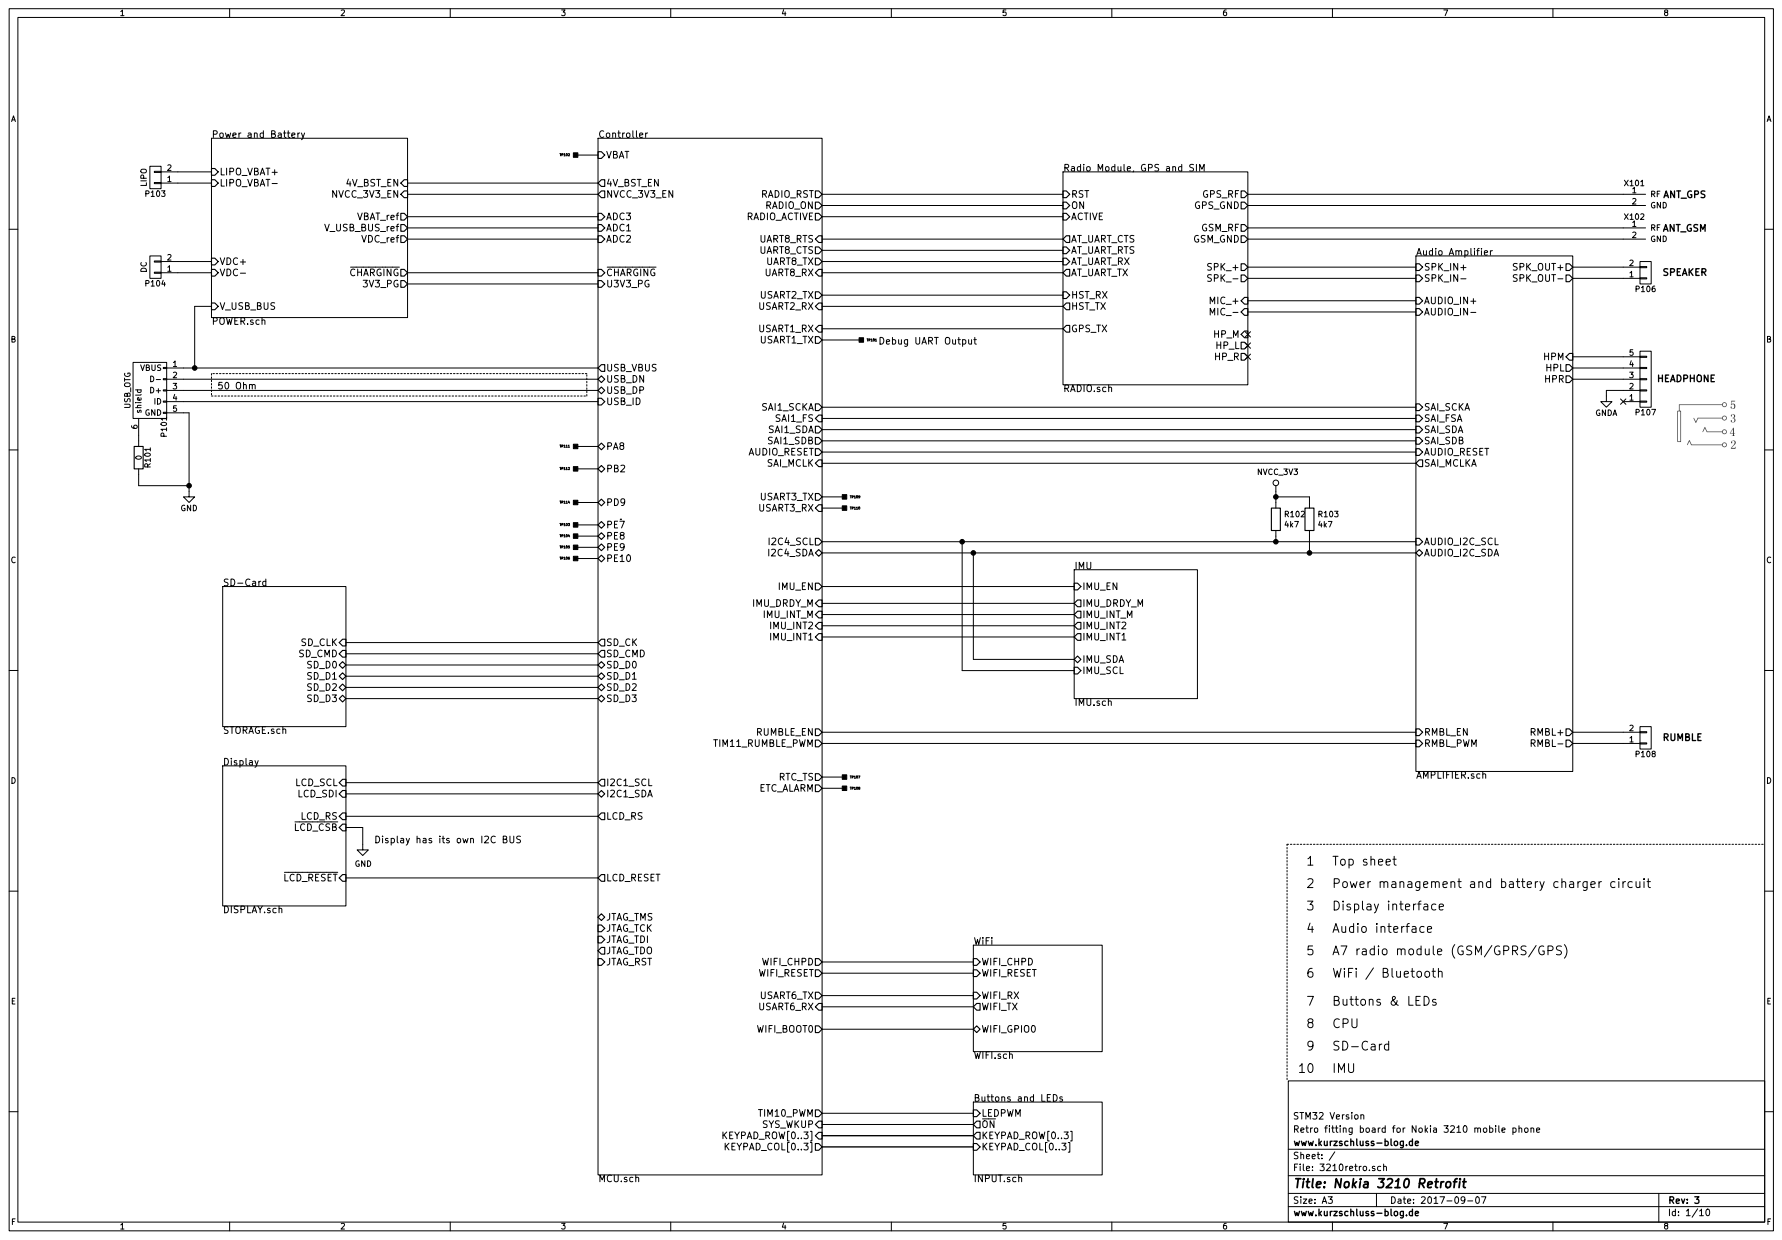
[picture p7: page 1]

Power and Battery POWER.sch V_USB_BUS

Radio Module, GPS and SIM

GND Display has its own I2C BUS

Power management and battery charger circuit
Display interface Audio interface A7 radio module (GSM/GPRS/GPS) WiFi / Bluetooth Buttons & LEDs CPU

Id: 1/10 Title: Nokia 3210 Retrofit File: 3210retro.sch Sheet: / www.kurzschluss-blog.de Retro fitting board for Nokia 3210 mobile phone STM32 Version

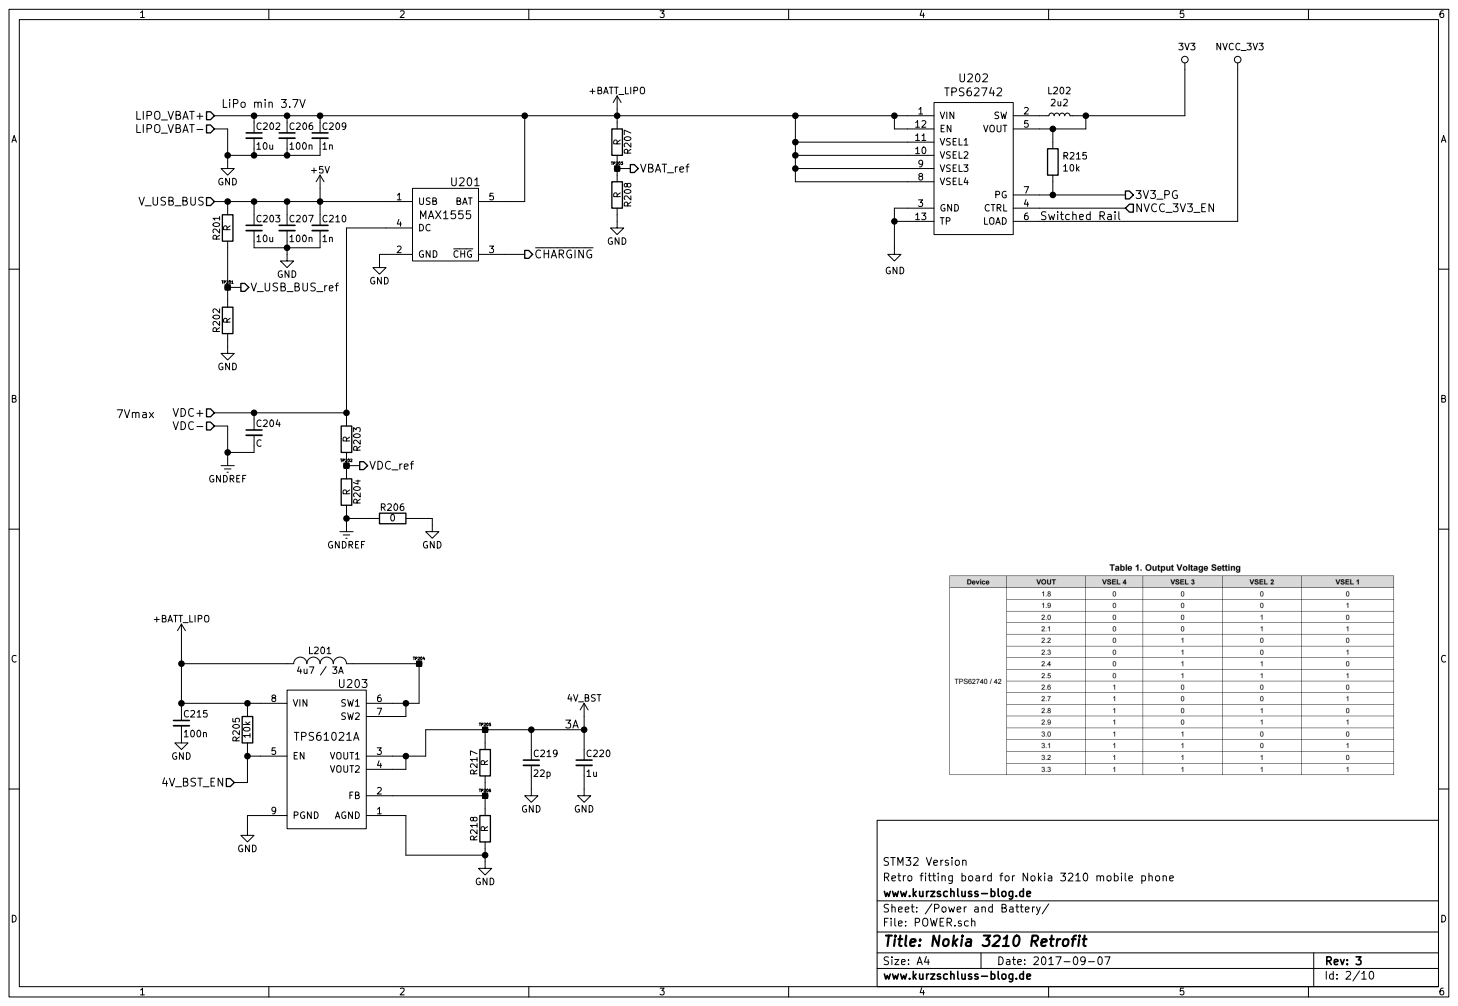
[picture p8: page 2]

Retro fitting board for Nokia 3210 mobile phone STM32 Version

www.kurzschluss-blog.de
Id: 2/10 Title: Nokia 3210 Retrofit File: POWER.sch Sheet: /Power and Battery/

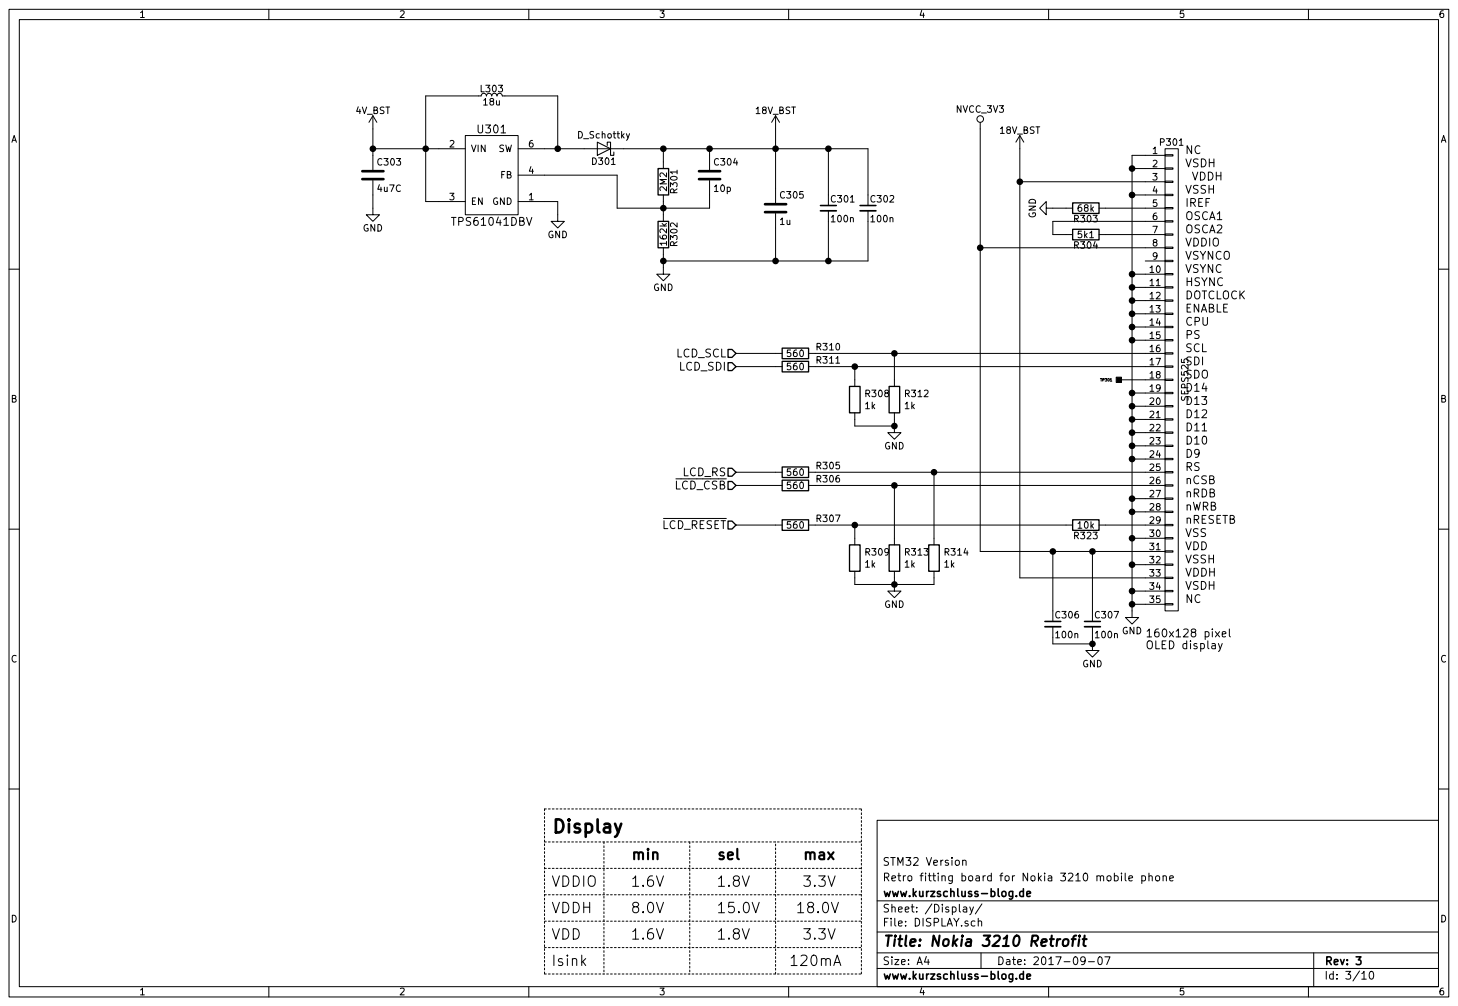
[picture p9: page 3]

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
25 26 27

30
31
32
33
34
35

Display

Retro fitting board for Nokia 3210 mobile phone STM32 Version VDDIO

1.6V | 1.8V | 3.3V
8.0V | 15.0V | 18.0V

www.kurzschluss-blog.de
Id: 3/10 Title: Nokia 3210 Retrofit File: DISPLAY.sch Sheet: /Display/

VDD | 1.6V | 1.8V

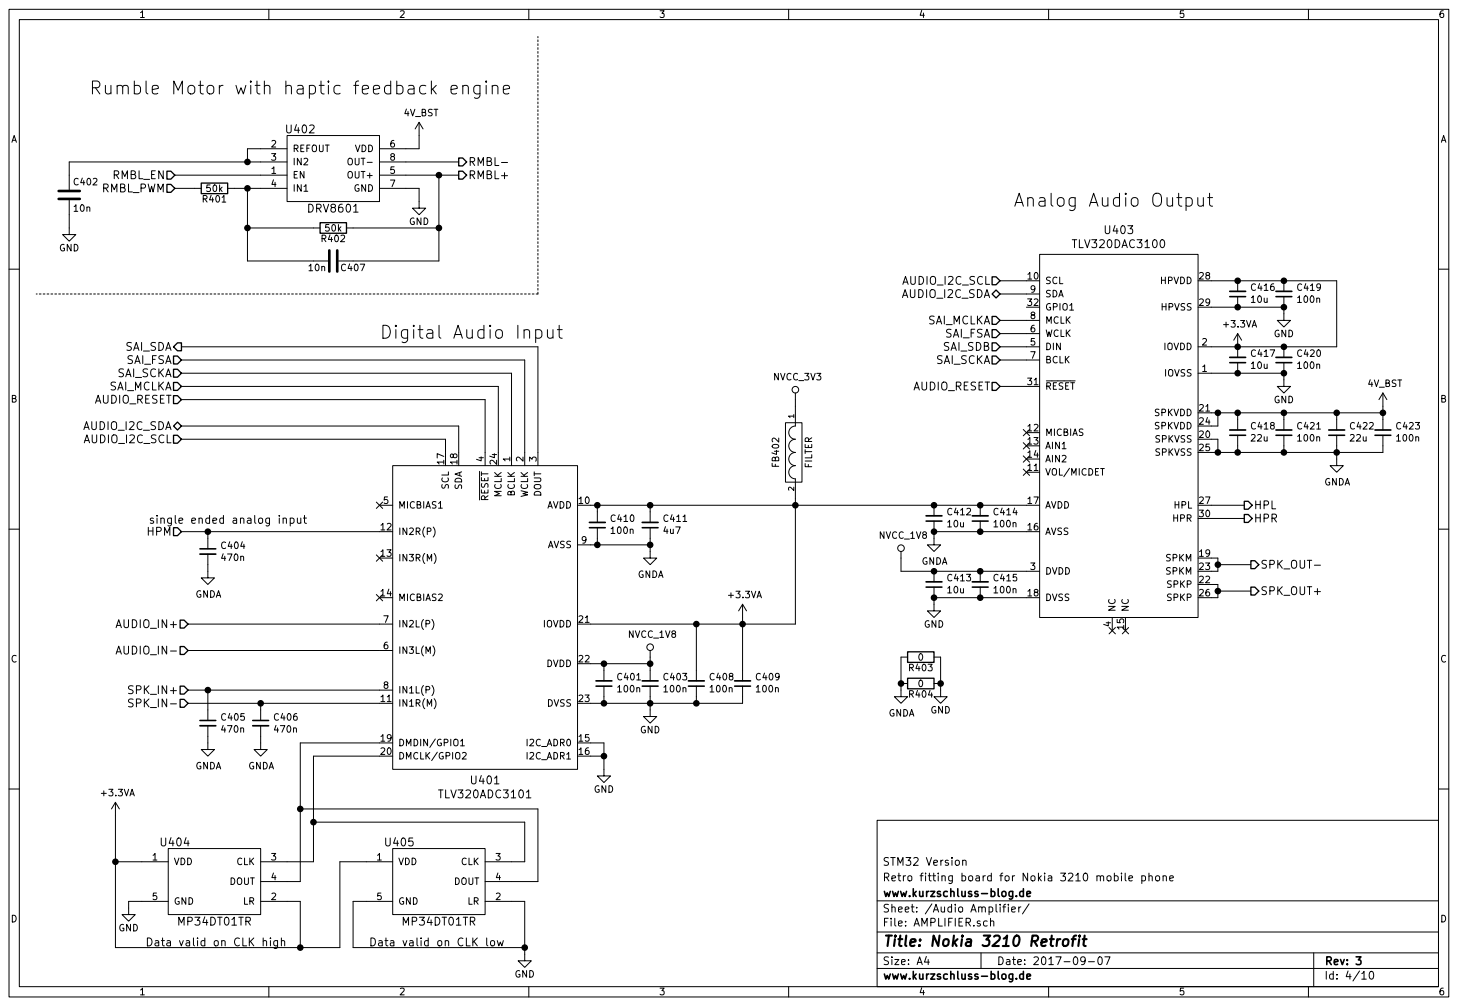
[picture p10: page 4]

10n GND Rumble Motor with haptic feedback engine

4 DIN 5 WCLK 6 BCLK 7 MCLK 8 SDA 9 SCL 10 SPKVSS 20 HPR 30 VOL/MICDET 11 SPKVDD 21 RESET 31 MICBIAS 12 SPKP 22 GPIO1 32 AIN1 13 SPKM 23 AIN2 14 SPKVDD 24 NC 15 SPKVSS 25 AVSS 16 SPKP 26 AVDD 17 HPL 27 DVSS 18 HPVDD 28 SPKM 19 HPVSS 29 U403 TLV320DAC3100 C414

470n single ended analog input GNDAC405
AUDIO_IN- HPM

www.kurzschluss-blog.de
Id: 4/10 Title: Nokia 3210 Retrofit File: AMPLIFIER.sch Sheet: /Audio Amplifier/

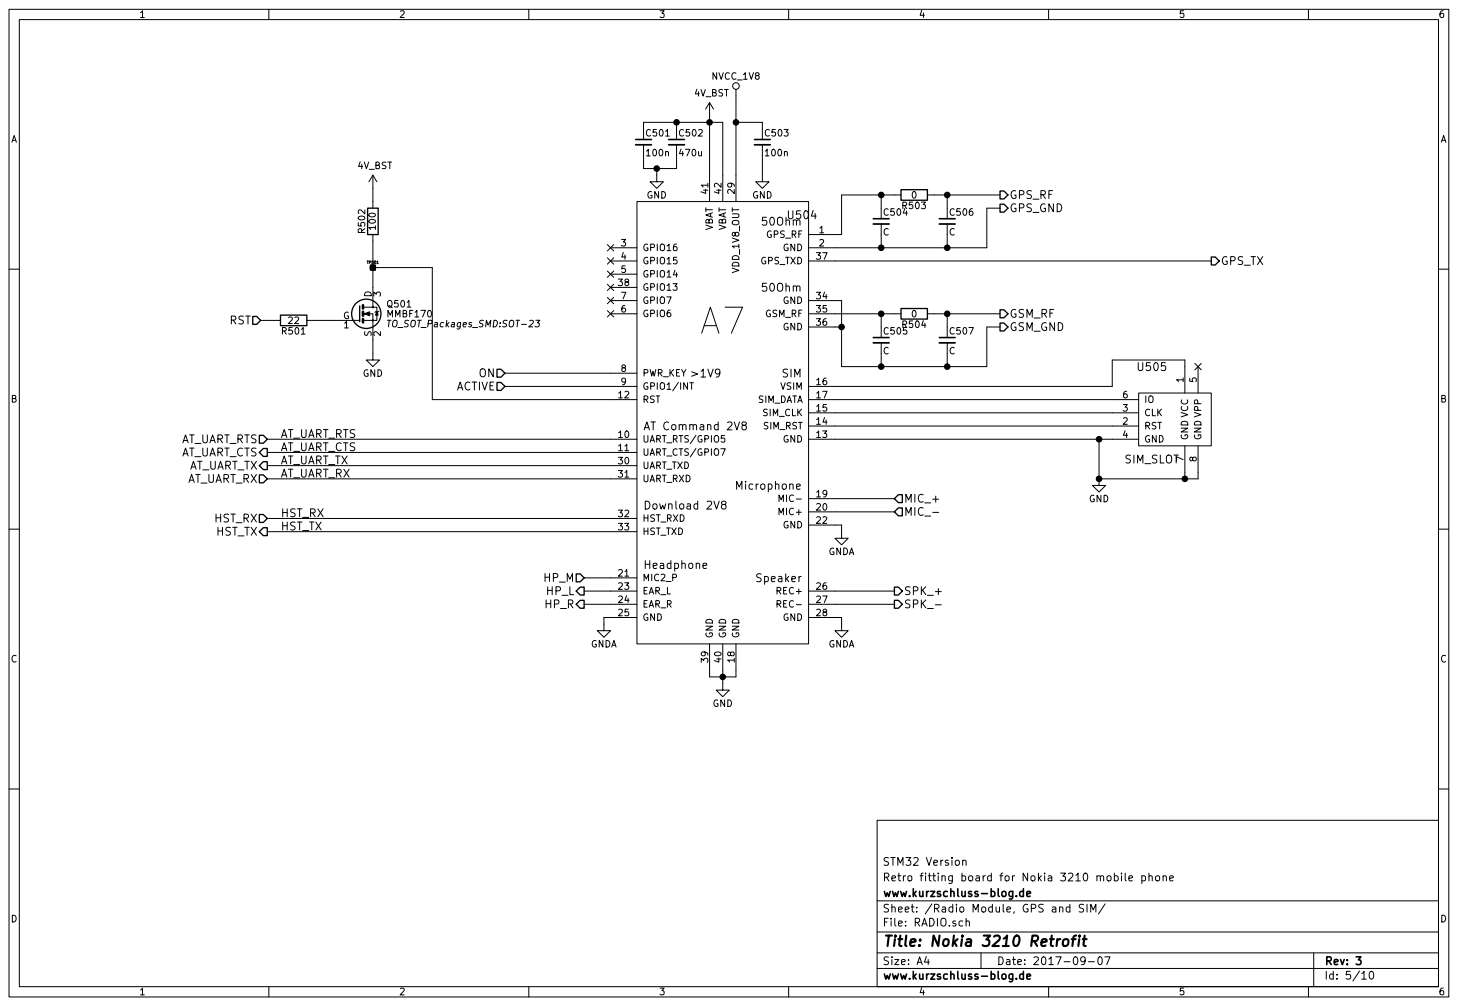
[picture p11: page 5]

1 RST 2 CLK 3 GND 4 VPP

www.kurzschluss-blog.de
Id: 5/10 Title: Nokia 3210 Retrofit File: RADIO.sch Sheet: /Radio Module, GPS and SIM/

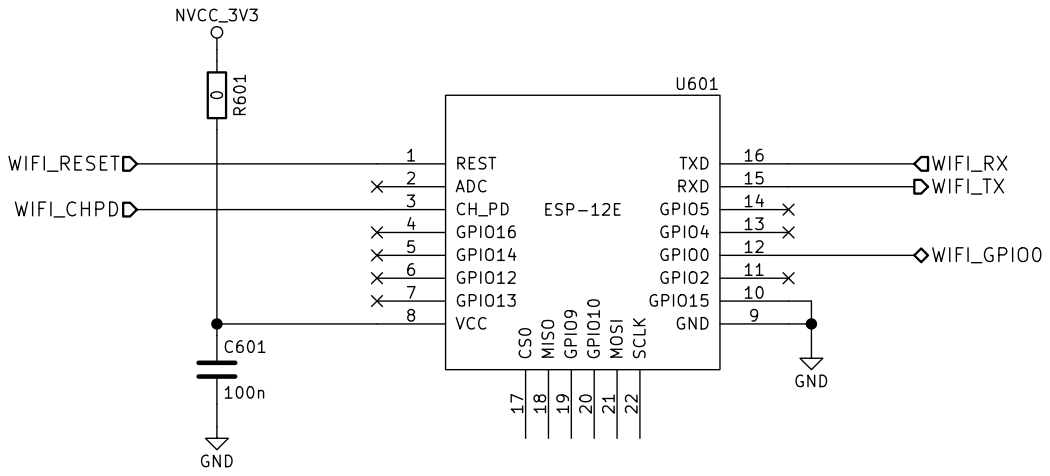
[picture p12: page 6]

Retro fitting board for Nokia 3210 mobile phone STM32 Version

Id: 6/10 Title: Nokia 3210 Retrofit File: WIFI.sch Sheet: /WiFi/ www.kurzschluss-blog.de

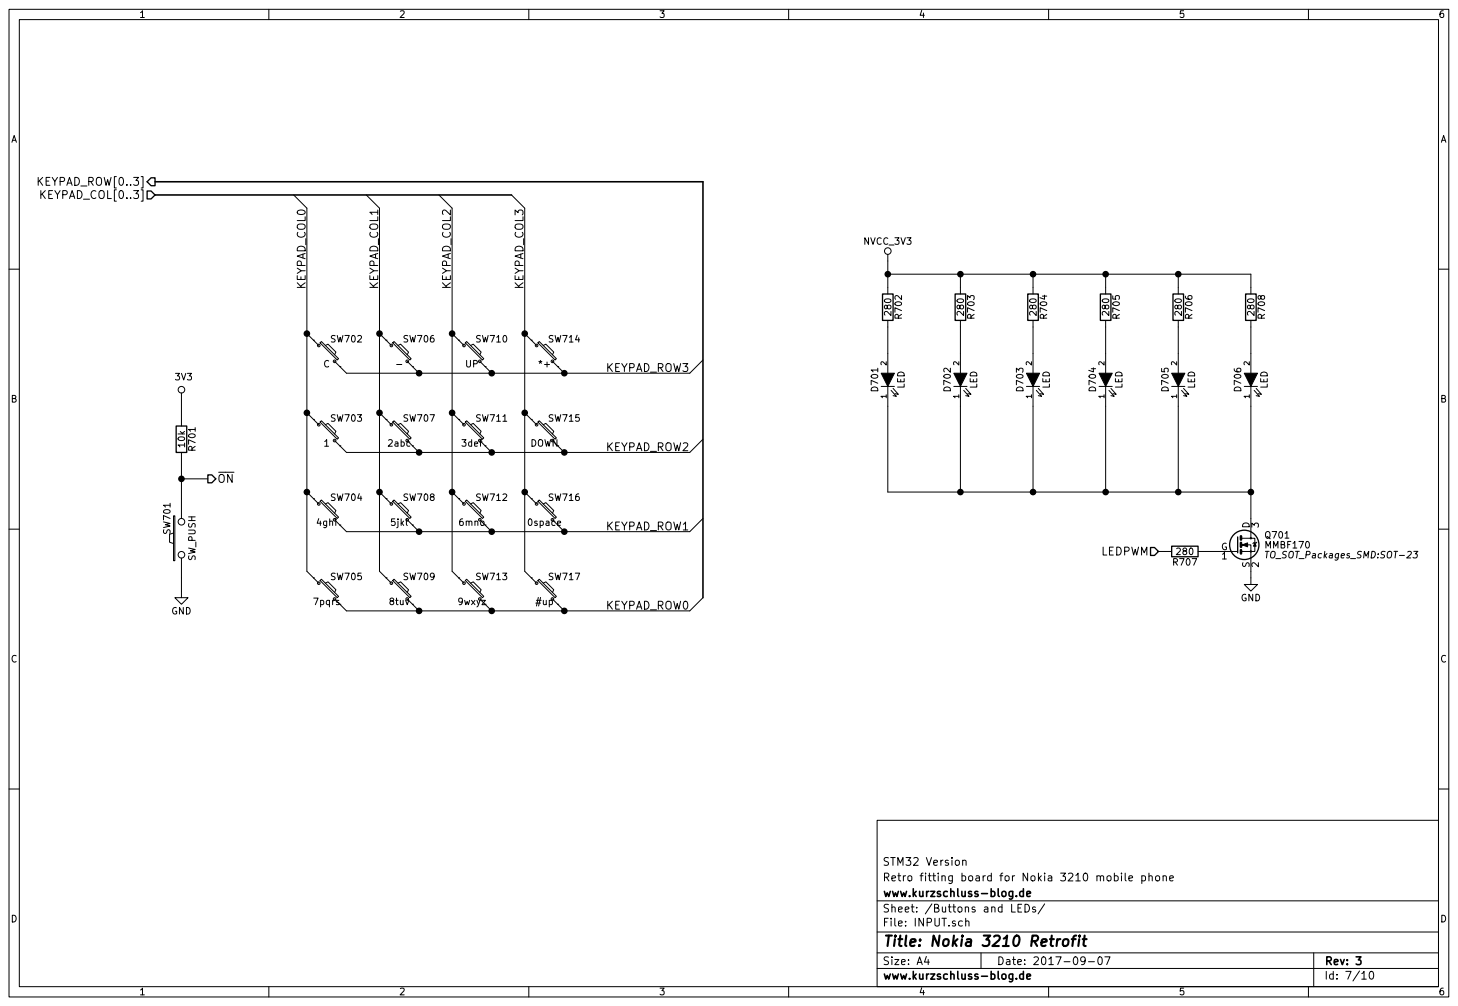
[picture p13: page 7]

Retro fitting board for Nokia 3210 mobile phone STM32 Version

Id: 7/10 Title: Nokia 3210 Retrofit File: INPUT.sch Sheet: /Buttons and LEDs/ www.kurzschluss-blog.de

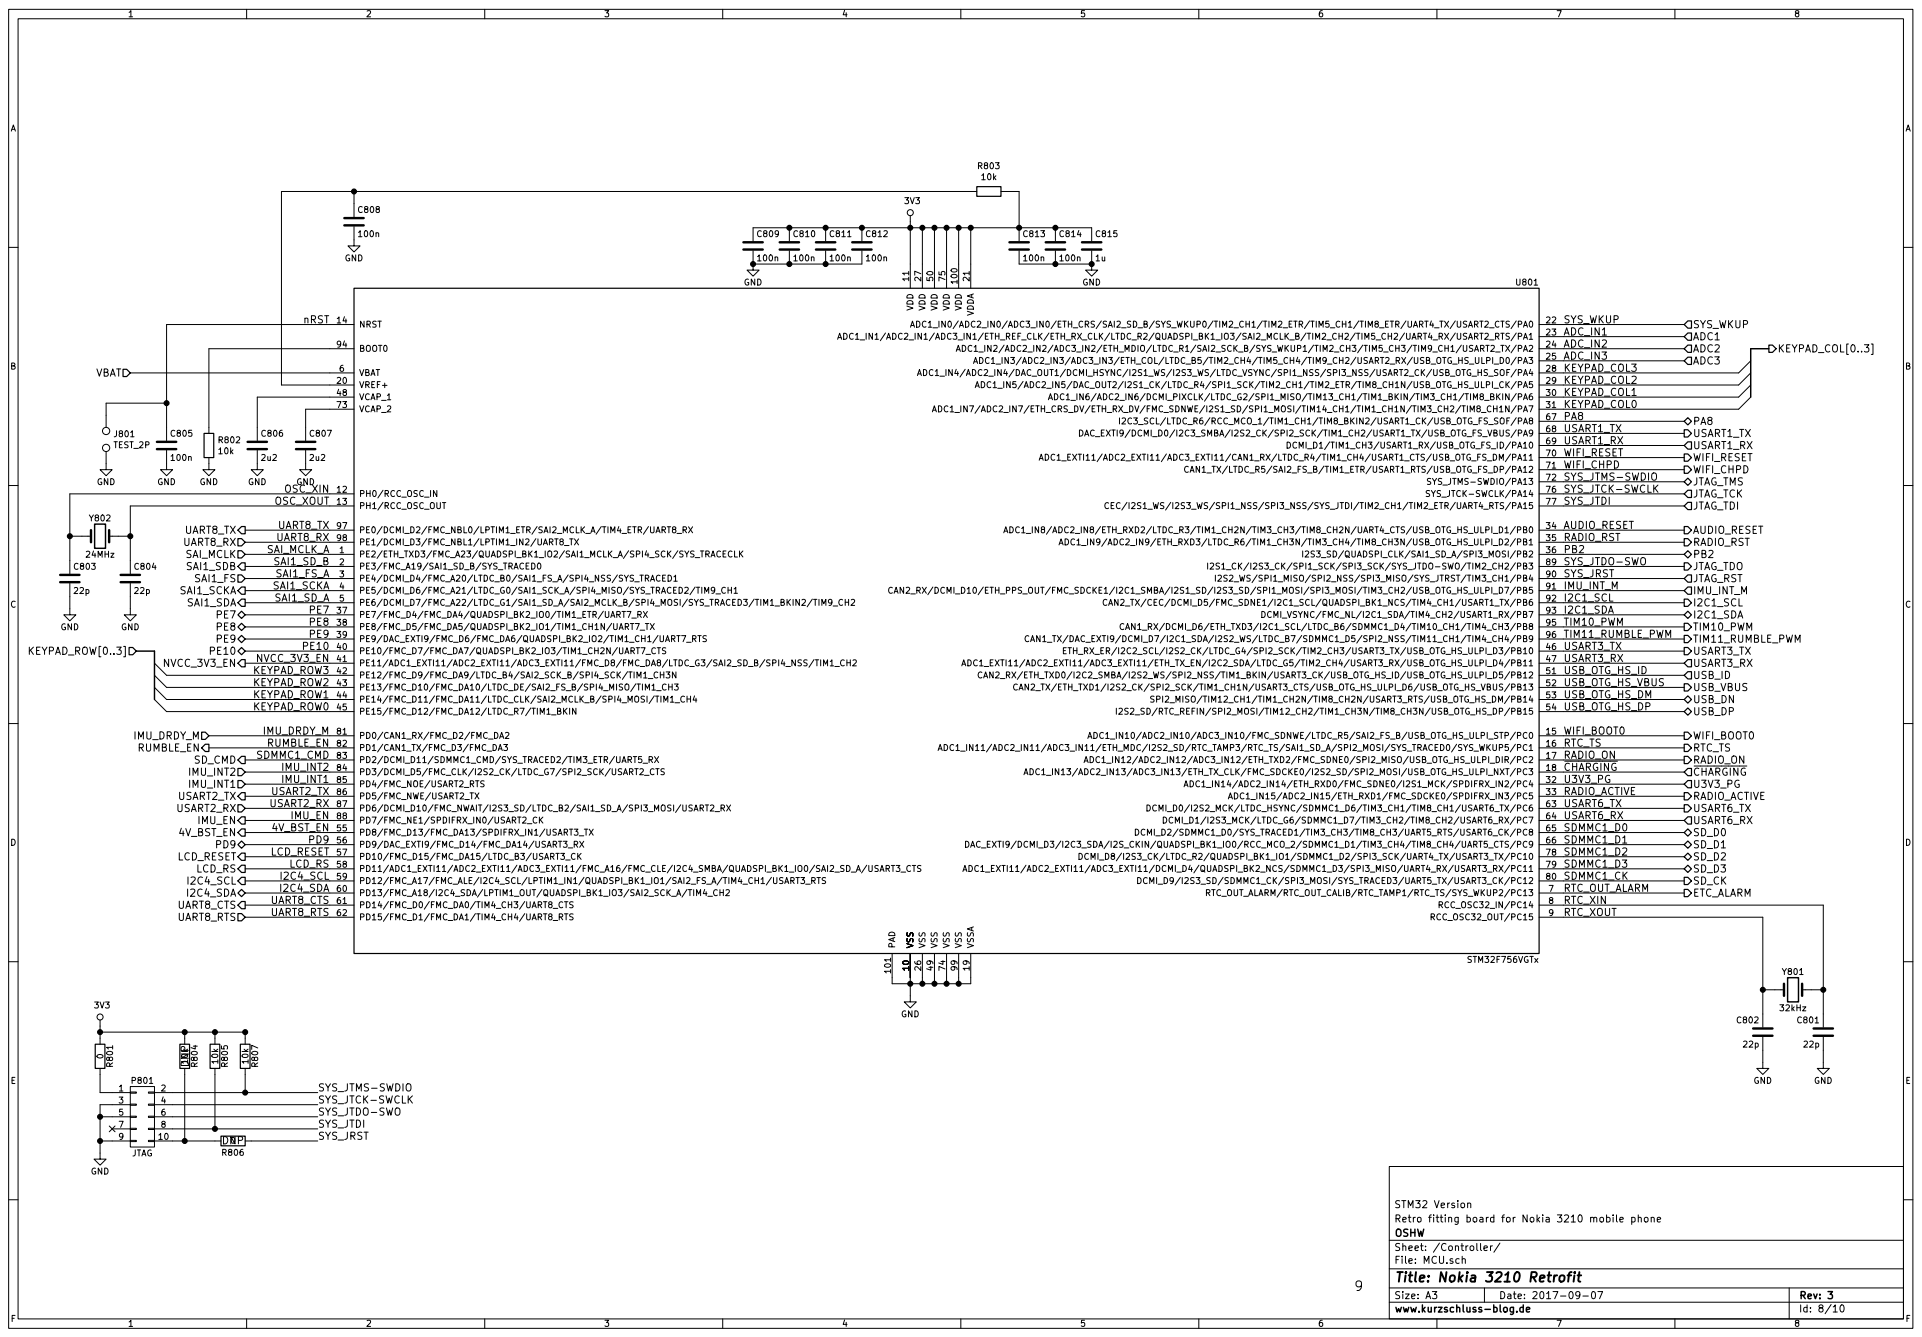
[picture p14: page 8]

Retro fitting board for Nokia 3210 mobile phone STM32 Version

Id: 8/10 Title: Nokia 3210 Retrofit File: MCU.sch Sheet: /Controller/ OSHW

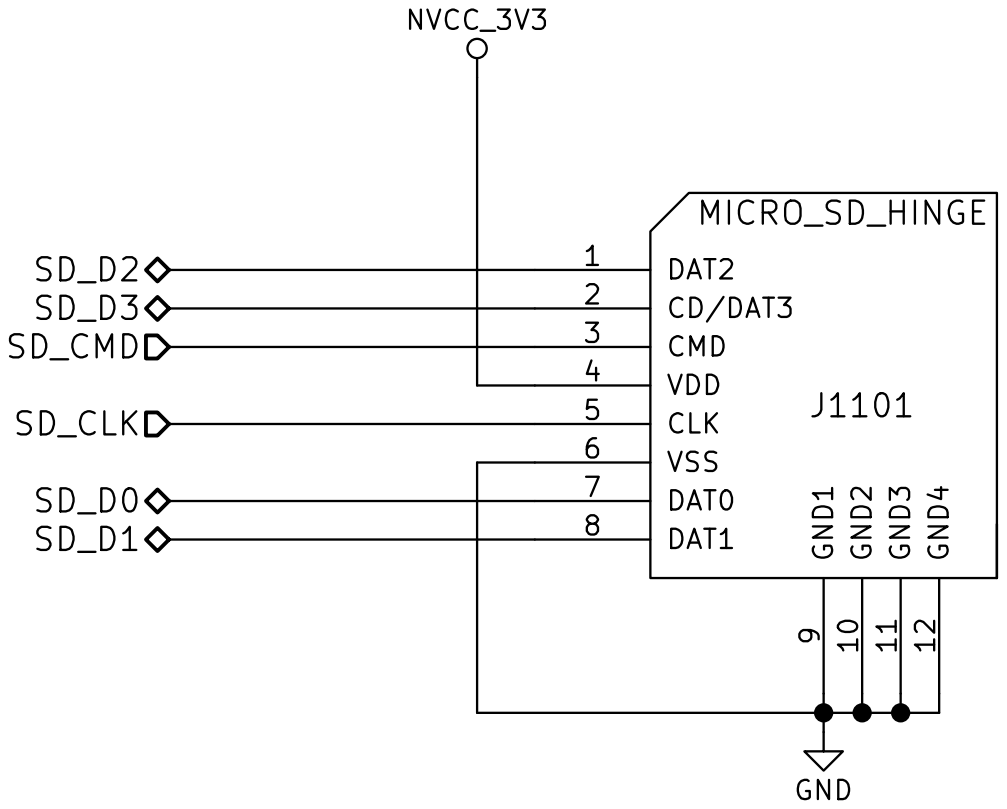
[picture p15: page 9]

Retro fitting board for Nokia 3210 mobile phone STM32 Version

Id: 9/10 Title: Nokia 3210 Retrofit File: STORAGE.sch Sheet: /SD-Card/ www.kurzschluss-blog.de

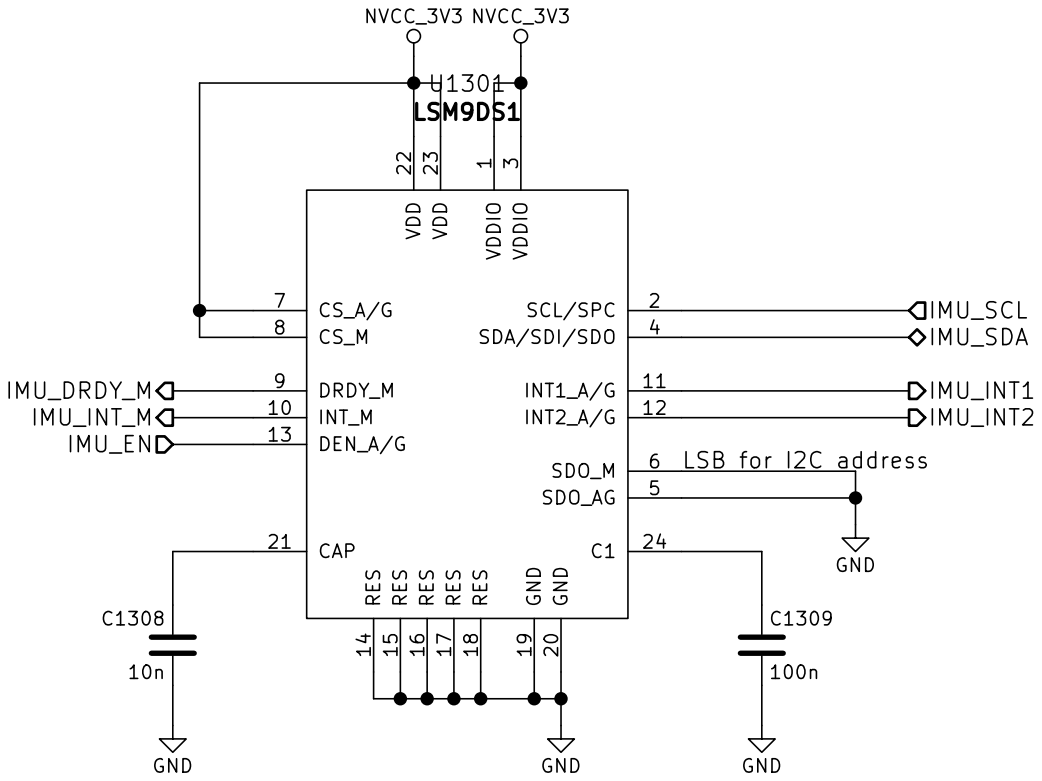
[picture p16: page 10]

LSB for I2C address GND

Retro fitting board for Nokia 3210 mobile phone STM32 Version

Id: 10/10 Title: Nokia 3210 Retrofit File: IMU.sch Sheet: /IMU/ www.kurzschluss-blog.de

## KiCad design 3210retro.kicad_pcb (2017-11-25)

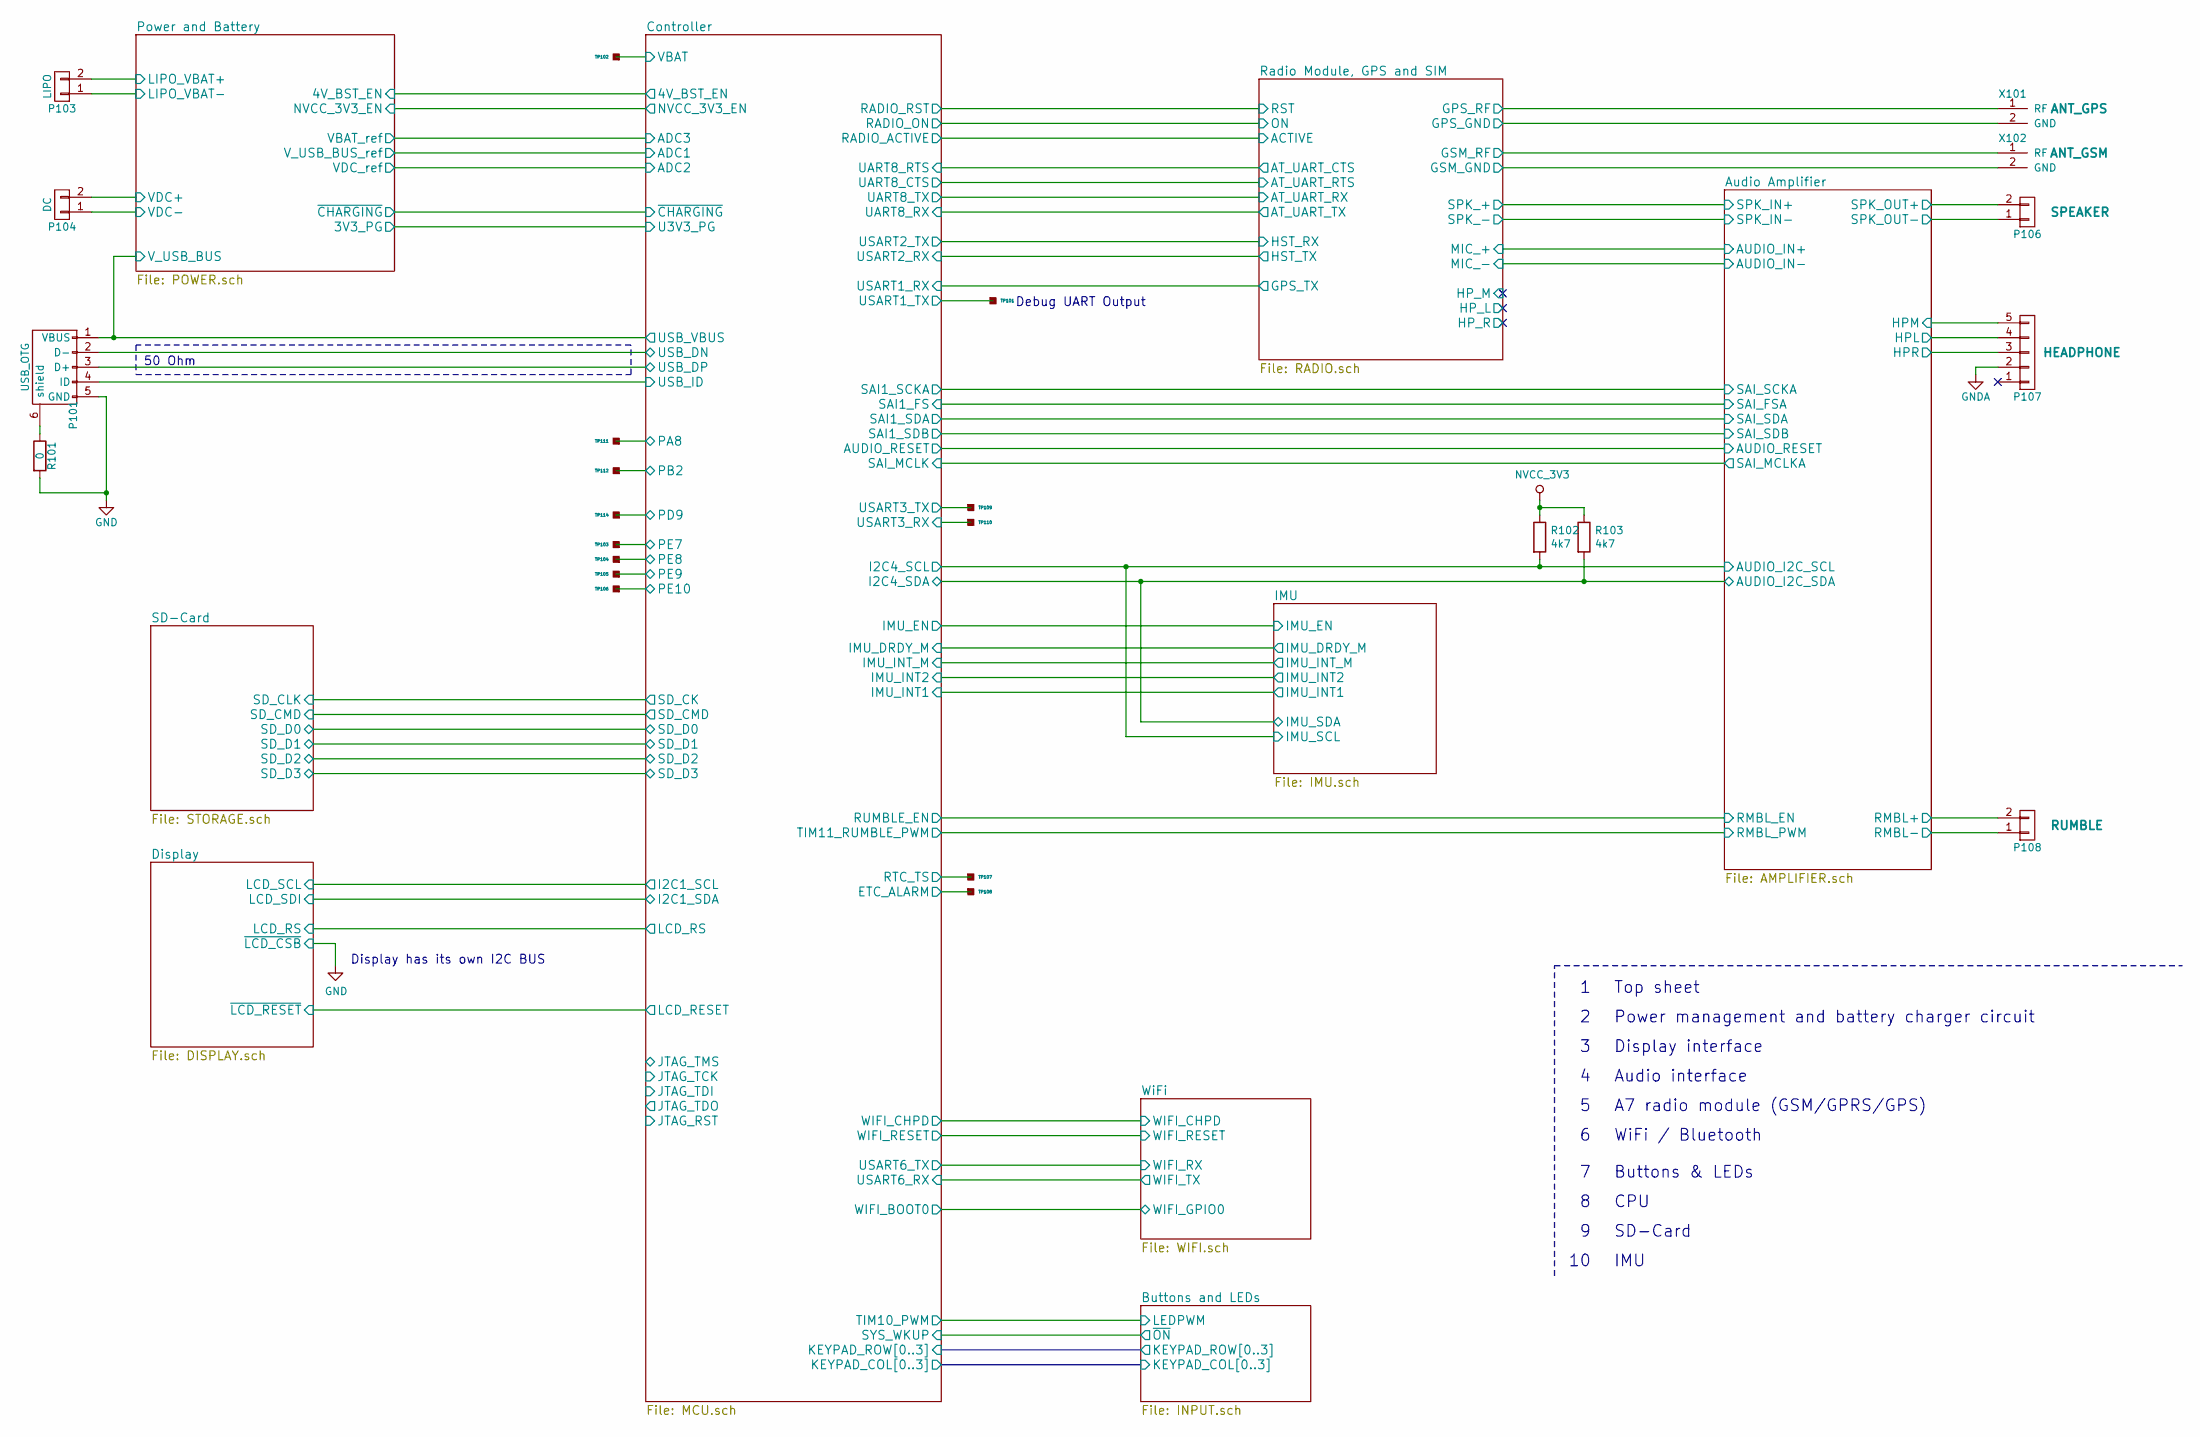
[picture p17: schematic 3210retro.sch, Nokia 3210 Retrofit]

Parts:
P101: USB_OTG; USB_Micro-B_10103594-0001LF
P103: LIPO; SolderWirePad_2x_0,8
P104: DC; SolderWirePad_2x_0,8
P106: SPEAKER; SolderWirePad_2x_0,8
P107: HEADPHONE; PJ_320_D
P108: RUMBLE; Rumble_Pads
R101: 0; R_0402_NoSilk
R102, R103: 4k7; R_0402_NoSilk
TP101, TP102, TP103, TP104, TP105, TP106, TP107, TP108, TP109, TP110, TP111, TP112, TP114: TP
X101: ANT_GPS; SolderWirePad_2x_0,8
X102: ANT_GSM; SolderWirePad_2x_0,8

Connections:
+5V: P101.1 (VBUS); also elsewhere on the board
+BATT_LIPO: P103.2; also elsewhere on the board
/Audio Amplifier/AUDIO_I2C_SCL: R102.2; also elsewhere on the board
/Audio Amplifier/AUDIO_I2C_SDA: R103.2; also elsewhere on the board
/Audio Amplifier/HPL: P107.4; also elsewhere on the board
/Audio Amplifier/HPR: P107.3; also elsewhere on the board
/Audio Amplifier/RMBL+: P108.2; also elsewhere on the board
/Audio Amplifier/RMBL-: P108.1; also elsewhere on the board
/Audio Amplifier/SPK_OUT+: P106.2; also elsewhere on the board
/Audio Amplifier/SPK_OUT-: P106.1; also elsewhere on the board
/Controller/ETC_ALARM: TP108.1; also elsewhere on the board
/Controller/PA8: TP111.1; also elsewhere on the board
/Controller/PB2: TP112.1; also elsewhere on the board
/Controller/PD9: TP114.1; also elsewhere on the board
/Controller/PE7: TP103.1; also elsewhere on the board
/Controller/PE8: TP104.1; also elsewhere on the board
/Controller/PE9: TP105.1; also elsewhere on the board
/Controller/PE10: TP106.1; also elsewhere on the board
/Controller/RTC_TS: TP107.1; also elsewhere on the board
/Controller/USART1_TX: TP101.1; also elsewhere on the board
/Controller/USART3_RX: TP110.1; also elsewhere on the board
/Controller/USART3_TX: TP109.1; also elsewhere on the board
/Controller/USB_DN: P101.2 (D-); also elsewhere on the board
/Controller/USB_DP: P101.3 (D+); also elsewhere on the board
/Controller/USB_ID: P101.4 (ID); also elsewhere on the board
/Controller/VBAT: TP102.1; also elsewhere on the board
/Power and Battery/VDC+: P104.2; also elsewhere on the board
/Radio Module, GPS and SIM/GPS_GND: X101.2 (GND); also elsewhere on the board
/Radio Module, GPS and SIM/GPS_RF: X101.1 (RF); also elsewhere on the board
/Radio Module, GPS and SIM/GSM_GND: X102.2 (GND); also elsewhere on the board
/Radio Module, GPS and SIM/GSM_RF: X102.1 (RF); also elsewhere on the board
GND: P101.5 (GND), P103.1, R101.2; also elsewhere on the board
GNDA: P107.2; also elsewhere on the board
GNDREF: P104.1; also elsewhere on the board
NVCC_3V3: R102.1, R103.1; also elsewhere on the board
unnamed: P101.6 (shield), R101.1

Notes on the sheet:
50 Ohm
Top sheet
Power management and battery charger circuit
Display interface
Audio interface
A7 radio module (GSM/GPRS/GPS)
WiFi / Bluetooth
Buttons & LEDs
CPU
Display has its own I2C BUS
Debug UART Output
SD-Card
IMU

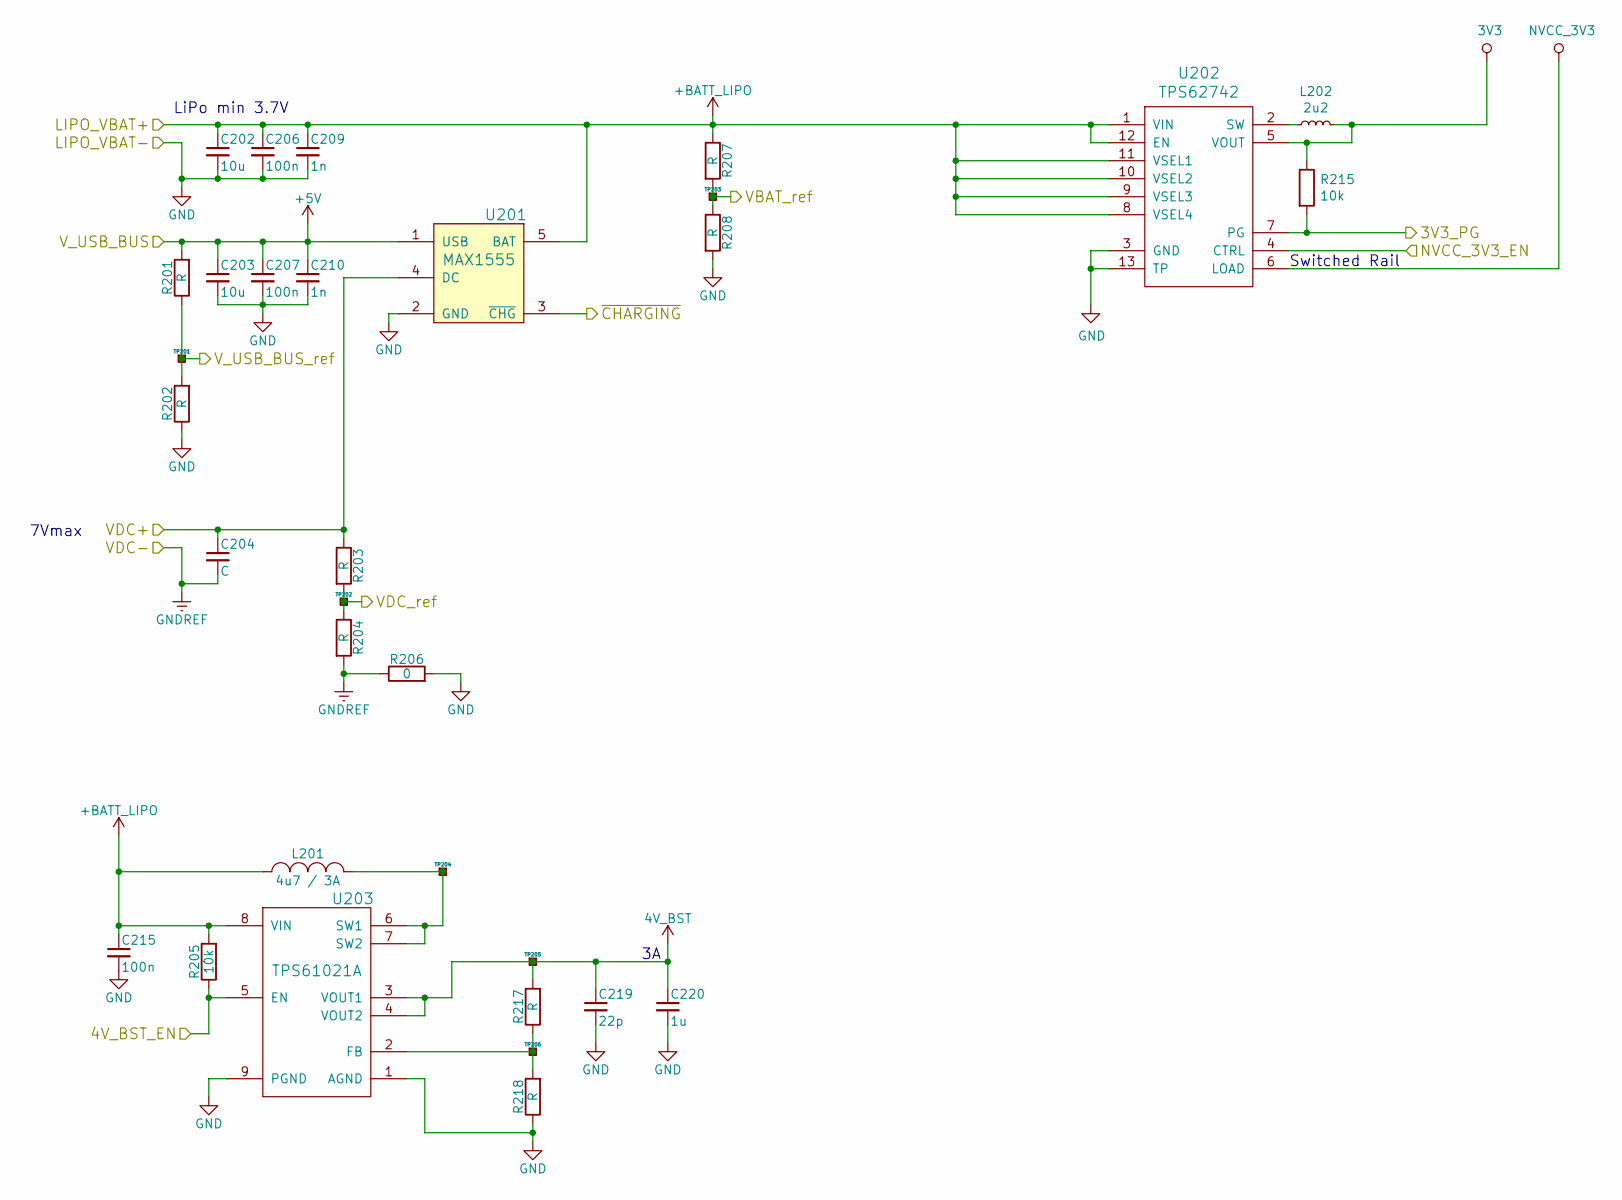
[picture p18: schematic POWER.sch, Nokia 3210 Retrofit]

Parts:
C202, C203: 10u; C_0603
C204: C; C_0402_NoSilk
C206, C207, C215: 100n; C_0402_NoSilk
C209, C210: 1n; C_0402_NoSilk
C219: 22p; C_0402_NoSilk
C220: 1u; C_0402_NoSilk
L201: 4u7 / 3A; Choke_SMD_1206_Standard
L202: 2u2; Choke_SMD_1206_Standard
R201, R202, R203, R204, R207, R208, R217, R218: R; R_0402_NoSilk
R205, R215: 10k; R_0402_NoSilk
R206: 0; R_0603
TP201, TP202, TP203, TP204, TP205, TP206: TP
U201: MAX1555; SOT-23-5
U202: TPS62742; TPS6274x
U203: TPS61021A; Texas_S-PVSON-N8_NoThermalVias

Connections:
3V3: L202.2, R215.1, U202.5 (VOUT); also elsewhere on the board
4V_BST: C219.1, C220.1, R217.2, TP205.1, U203.3 (VOUT1), U203.4 (VOUT2); also elsewhere on the board
+5V: C203.1, C207.1, C210.1, R201.2, U201.1 (USB); also elsewhere on the board
+BATT_LIPO: C202.1, C206.1, C209.1, C215.1, L201.1, R205.2, R207.1, U201.5 (BAT), U202.1 (VIN), U202.8 (VSEL4), U202.9 (VSEL3), U202.10 (VSEL2), U202.11 (VSEL1), U202.12 (EN), U203.8 (VIN); also elsewhere on the board
/Controller/4V_BST_EN: R205.1, U203.5 (EN); also elsewhere on the board
/Controller/ADC1: R201.1, R202.2, TP201.1; also elsewhere on the board
/Controller/ADC2: R203.2, R204.1, TP202.1; also elsewhere on the board
/Controller/ADC3: R207.2, R208.1, TP203.1; also elsewhere on the board
/Controller/NVCC_3V3_EN: U202.4 (CTRL); also elsewhere on the board
/Controller/~CHARGING: U201.3 (~CHG); also elsewhere on the board
/Power and Battery/3V3_PG: R215.2, U202.7 (PG); also elsewhere on the board
/Power and Battery/VDC+: C204.1, R203.1, U201.4 (DC); also elsewhere on the board
GND: C202.2, C203.2, C206.2, C207.2, C209.2, C210.2, C215.2, C219.2, C220.2, R202.1, R206.2, R208.2, R218.1, U201.2 (GND), U202.3 (GND), U202.13 (TP), U203.1 (AGND), U203.9 (PGND); also elsewhere on the board
GNDREF: C204.2, R204.2, R206.1; also elsewhere on the board
NVCC_3V3: U202.6 (LOAD); also elsewhere on the board
unnamed: L201.2, TP204.1, U203.6 (SW1), U203.7 (SW2)
unnamed: L202.1, U202.2 (SW)
unnamed: R217.1, R218.2, TP206.1, U203.2 (FB)

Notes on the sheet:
LiPo min 3.7V
7Vmax
Switched Rail

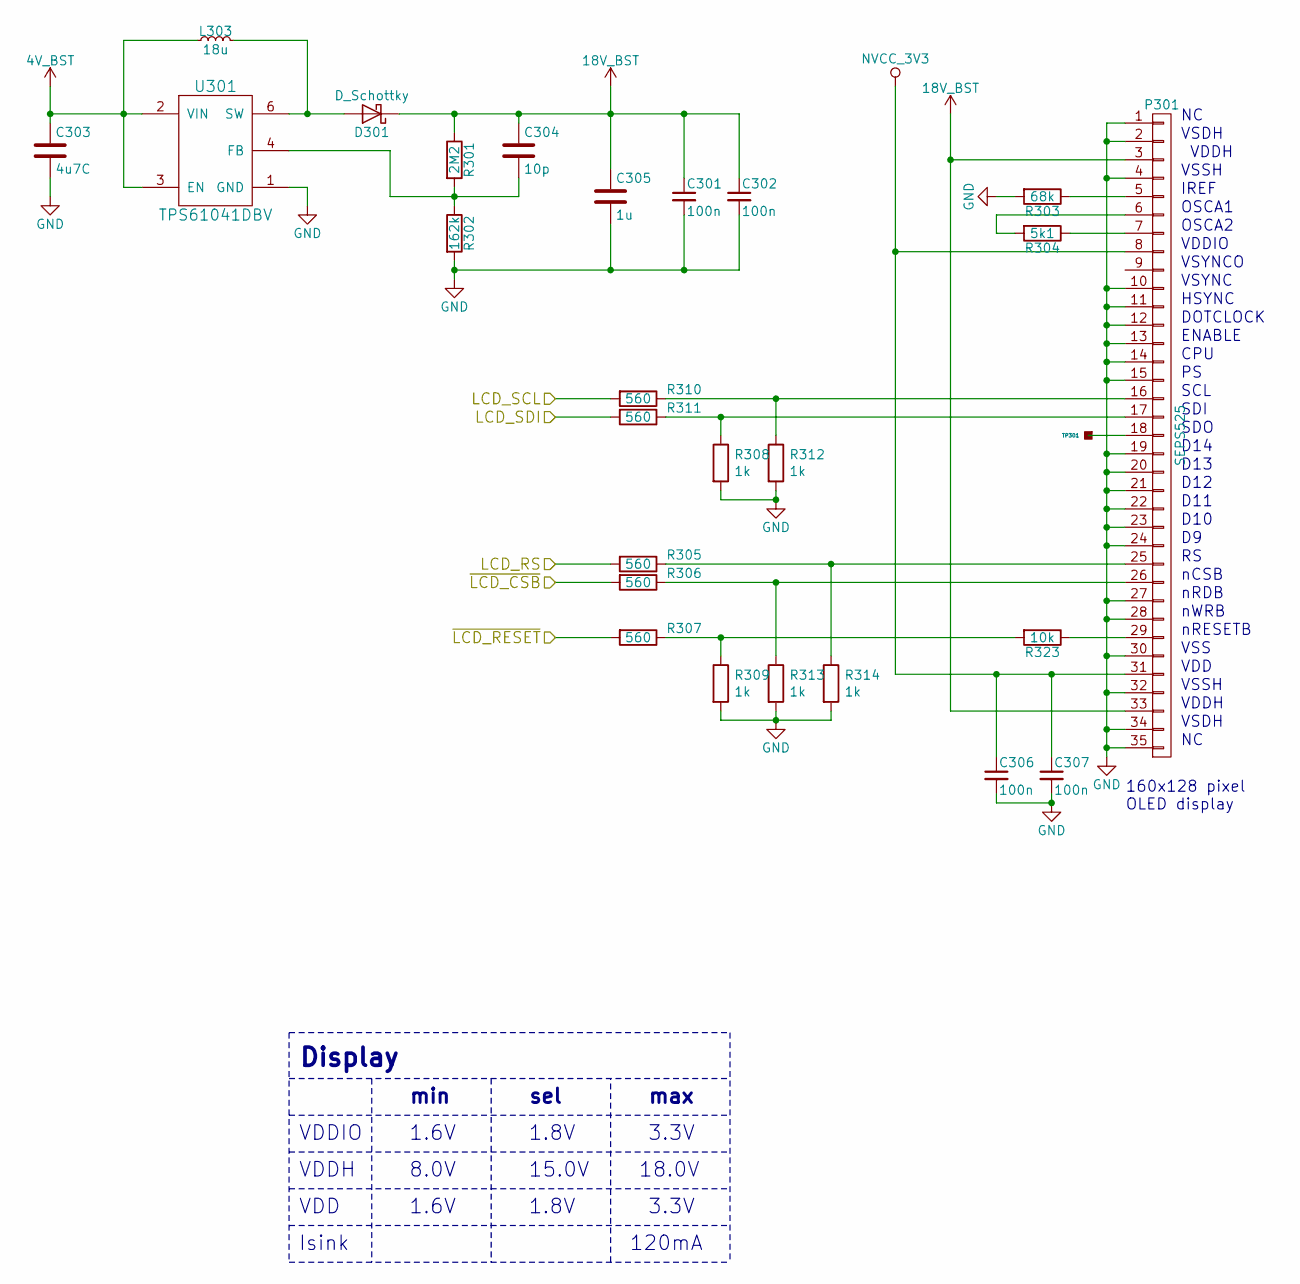
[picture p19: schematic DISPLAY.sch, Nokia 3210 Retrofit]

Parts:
C301, C302, C306, C307: 100n; C_0402_NoSilk
C303: 4u7C; C_0402_NoSilk
C304: 10p; C_0402_NoSilk
C305: 1u; C_0402_NoSilk
D301: D_Schottky; D_0805
L303: 18u; Choke_SMD_1206_Standard
P301: SEPS525; FFC-05-35
R301: 2M2; R_0402_NoSilk
R302: 162k; R_0402_NoSilk
R303: 68k; R_0402_NoSilk
R304: 5k1; R_0402_NoSilk
R305, R306, R307, R310, R311: 560; R_0402_NoSilk
R308, R309, R312, R313, R314: 1k; R_0402_NoSilk
R323: 10k; R_0402_NoSilk
TP301: TP
U301: TPS61041DBV; DFN-6-1EP_2x2mm_Pitch0.65mm

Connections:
4V_BST: C303.1, L303.2, U301.2 (VIN), U301.3 (EN); also elsewhere on the board
18V_BST: C301.1, C302.1, C304.1, C305.1, D301.1 (K), P301.3, P301.33, R301.1
/Controller/I2C1_SCL: R310.2; also elsewhere on the board
/Controller/I2C1_SDA: R311.2; also elsewhere on the board
/Controller/LCD_RESET: R307.2; also elsewhere on the board
/Controller/LCD_RS: R305.2; also elsewhere on the board
GND: C301.2, C302.2, C303.2, C305.2, C306.2, C307.2, P301.1, P301.2, P301.4, P301.10, P301.11, P301.12, P301.13, P301.14, P301.15, P301.19, P301.20, P301.21, P301.22, P301.23, P301.24, P301.27, P301.28, P301.30, P301.32, P301.34, P301.35, R302.2, R303.2, R306.2, R308.2, R309.2, R312.2, R313.2, R314.2, U301.1 (GND); also elsewhere on the board
NVCC_3V3: C306.1, C307.1, P301.8, P301.31; also elsewhere on the board
unnamed: C304.2, R301.2, R302.1, U301.4 (FB)
unnamed: D301.2 (A), L303.1, U301.6 (SW)
unnamed: P301.5, R303.1
unnamed: P301.6, R304.2
unnamed: P301.7, R304.1
unnamed: P301.16, R310.1, R312.1
unnamed: P301.17, R308.1, R311.1
unnamed: P301.18, TP301.1
unnamed: P301.25, R305.1, R314.1
unnamed: P301.26, R306.1, R313.1
unnamed: P301.29, R323.1
unnamed: R307.1, R309.1, R323.2

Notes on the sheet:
VDDIO
VDDH
VDD
Display
1.6V
3.3V
8.0V
18.0V
min
max
160x128 pixel OLED display
Isink
120mA
sel
1.8V
15.0V
VSDH
VSSH
IREF
OSCA1
OSCA2
VSYNCO
VSYNC
HSYNC
DOTCLOCK
ENABLE
CPU
SCL
SDI
SDO
D14
D13
D12
D11
D10
nCSB
nWRB
nRESETB
VSS
nRDB

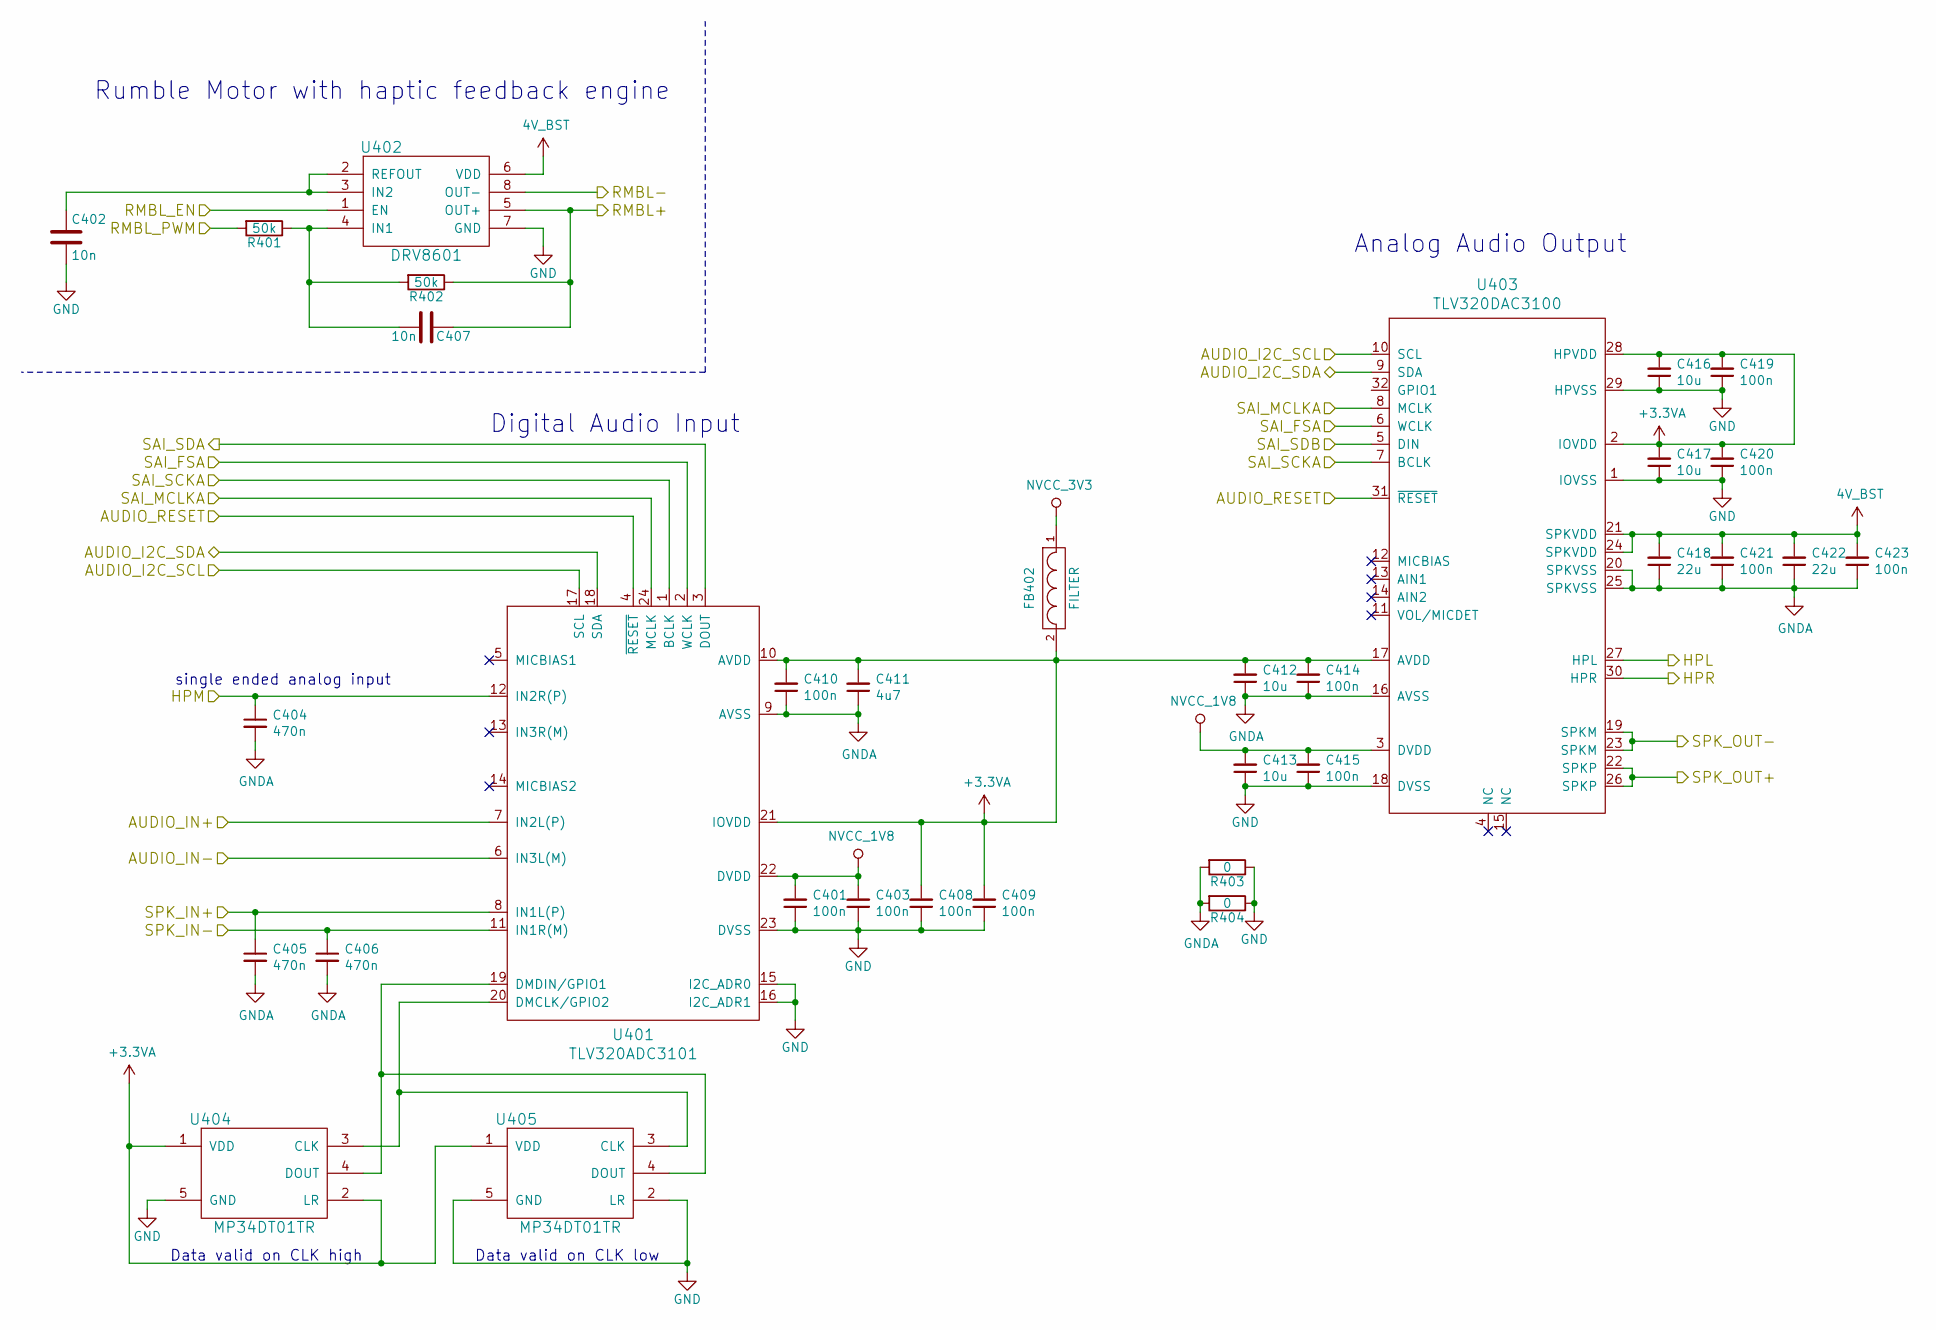
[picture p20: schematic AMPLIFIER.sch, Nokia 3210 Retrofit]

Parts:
C401, C403, C408, C409, C410, C414, C415, C419, C420, C421, C423: 100n; C_0402_NoSilk
C402, C407: 10n; C_0402_NoSilk
C404, C405, C406: 470n; C_0402_NoSilk
C411: 4u7; C_0402_NoSilk
C412, C413, C416, C417: 10u; C_0402_NoSilk
C418, C422: 22u; C_0402_NoSilk
FB402: FILTER; Choke_SMD_1206_Standard
R401, R402: 50k; R_0402_NoSilk
R403, R404: 0; R_0402_NoSilk
U401: TLV320ADC3101; QFN-24-1EP_4x4mm_Pitch0.5mm
U402: DRV8601; DFN-8-1EP_3x3mm_Pitch0.65mm
U403: TLV320DAC3100; QFN-32-1EP_5x5mm_Pitch0.5mm
U404, U405: MP34DT01TR; MP34DT01_NoGroundRing

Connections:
4V_BST: C418.2, C421.2, C422.2, C423.2, U402.6 (VDD), U403.21 (SPKVDD), U403.24 (SPKVDD); also elsewhere on the board
+3.3VA: C408.2, C409.2, C410.2, C411.2, C412.2, C414.2, C416.2, C417.2, C419.2, C420.2, FB402.2, U401.10 (AVDD), U401.21 (IOVDD), U403.2 (IOVDD), U403.17 (AVDD), U403.28 (HPVDD), U404.1 (VDD), U404.2 (LR), U405.1 (VDD)
/Audio Amplifier/AUDIO_I2C_SCL: U401.17 (SCL), U403.10 (SCL); also elsewhere on the board
/Audio Amplifier/AUDIO_I2C_SDA: U401.18 (SDA), U403.9 (SDA); also elsewhere on the board
/Audio Amplifier/AUDIO_IN+: U401.7 (IN2L(P)); also elsewhere on the board
/Audio Amplifier/AUDIO_IN-: U401.6 (IN3L(M)); also elsewhere on the board
/Audio Amplifier/AUDIO_RESET: U401.4 (~RESET), U403.31 (~RESET); also elsewhere on the board
/Audio Amplifier/HPL: U403.27 (HPL); also elsewhere on the board
/Audio Amplifier/HPM: C404.1, U401.12 (IN2R(P))
/Audio Amplifier/HPR: U403.30 (HPR); also elsewhere on the board
/Audio Amplifier/RMBL+: C407.1, R402.1, U402.5 (OUT+); also elsewhere on the board
/Audio Amplifier/RMBL-: U402.8 (OUT-); also elsewhere on the board
/Audio Amplifier/RMBL_EN: U402.1 (EN); also elsewhere on the board
/Audio Amplifier/RMBL_PWM: R401.2; also elsewhere on the board
/Audio Amplifier/SPK_OUT+: U403.22 (SPKP), U403.26 (SPKP); also elsewhere on the board
/Audio Amplifier/SPK_OUT-: U403.19 (SPKM), U403.23 (SPKM); also elsewhere on the board
/Controller/SAI1_FS: U401.2 (WCLK), U403.6 (WCLK); also elsewhere on the board
/Controller/SAI1_SCKA: U401.1 (BCLK), U403.7 (BCLK); also elsewhere on the board
/Controller/SAI1_SDA: U401.3 (DOUT); also elsewhere on the board
/Controller/SAI1_SDB: U403.5 (DIN); also elsewhere on the board
/Controller/SAI_MCLK: U401.24 (MCLK), U403.8 (MCLK); also elsewhere on the board
/Radio Module, GPS and SIM/SPK_+: C405.1, U401.8 (IN1L(P)); also elsewhere on the board
/Radio Module, GPS and SIM/SPK_-: C406.1, U401.11 (IN1R(M)); also elsewhere on the board
GND: C401.1, C402.2, C403.1, C408.1, C409.1, C413.1, C415.1, C416.1, C417.1, C419.1, C420.1, R403.1, R404.1, U401.15 (I2C_ADR0), U401.16 (I2C_ADR1), U401.23 (DVSS), U402.7 (GND), U402.9 (PAD), U403.1 (IOVSS), U403.18 (DVSS), U403.29 (HPVSS), U404.5 (GND), U405.2 (LR), U405.5 (GND); also elsewhere on the board
GNDA: C404.2, C405.2, C406.2, C410.1, C411.1, C412.1, C414.1, C418.1, C421.1, C422.1, C423.1, R403.2, R404.2, U401.9 (AVSS), U403.16 (AVSS), U403.20 (SPKVSS), U403.25 (SPKVSS); also elsewhere on the board
NVCC_1V8: C401.2, C403.2, C413.2, C415.2, U401.22 (DVDD), U403.3 (DVDD); also elsewhere on the board
NVCC_3V3: FB402.1; also elsewhere on the board
unnamed: C402.1, U402.2 (REFOUT), U402.3 (IN2)
unnamed: C407.2, R401.1, R402.2, U402.4 (IN1)
unnamed: U401.19 (DMDIN/GPIO1), U404.4 (DOUT), U405.4 (DOUT)
unnamed: U401.20 (DMCLK/GPIO2), U404.3 (CLK), U405.3 (CLK)

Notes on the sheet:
Data valid on CLK high
Data valid on CLK low
Rumble Motor with haptic feedback engine
single ended analog input
Digital Audio Input
Analog Audio Output

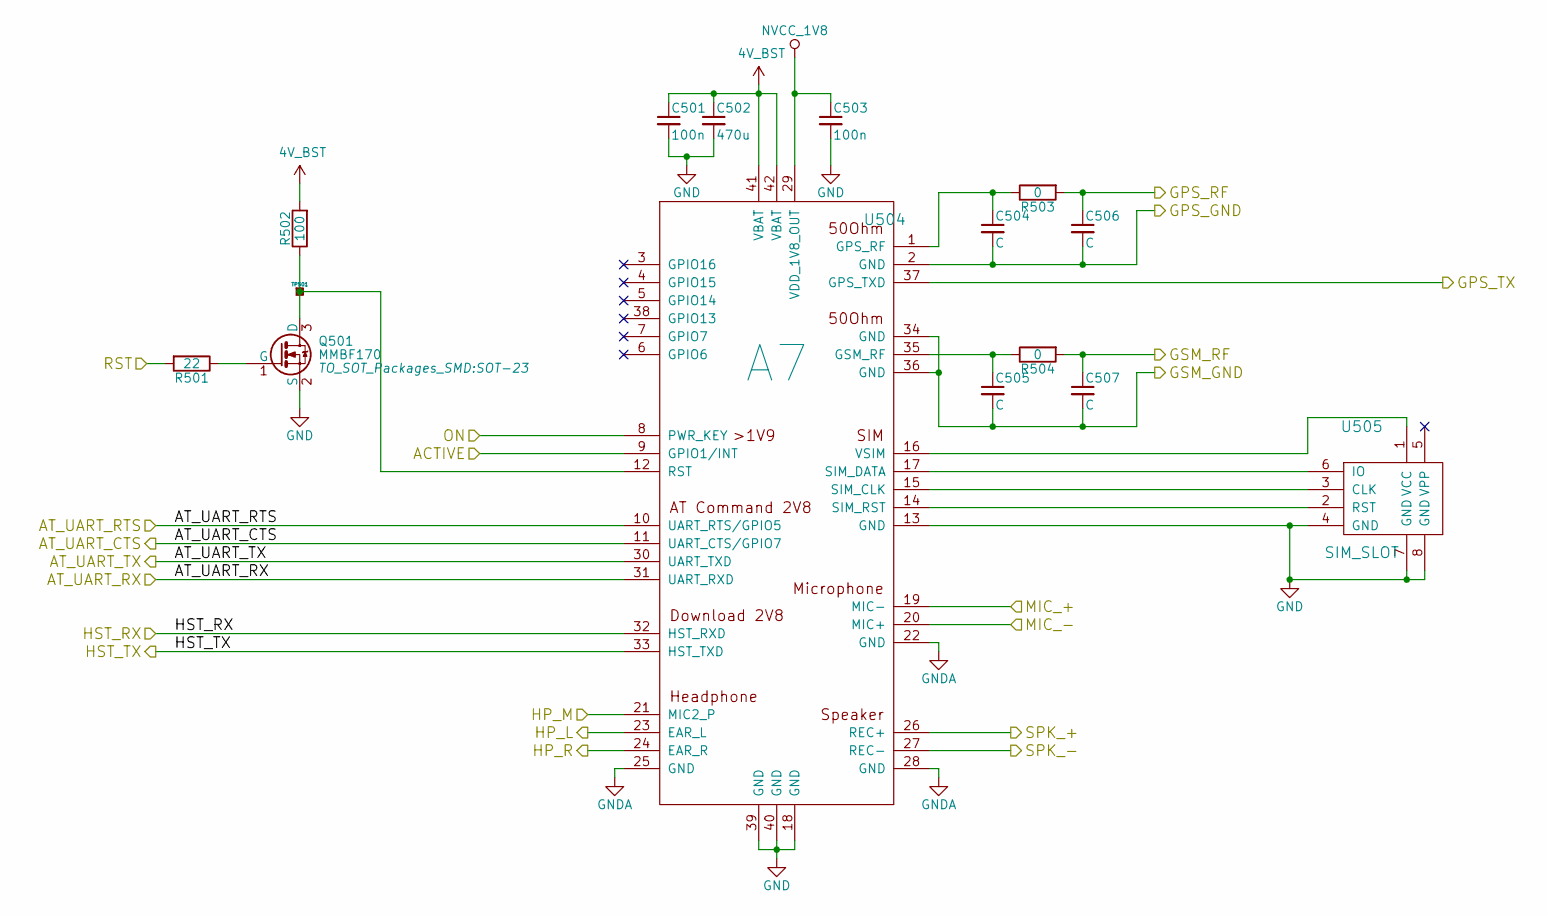
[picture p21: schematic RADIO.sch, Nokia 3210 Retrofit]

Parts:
C501, C503: 100n; C_0402_NoSilk
C502: 470u; C_0603
C504, C505, C506, C507: C; C_0402_NoSilk
Q501: MMBF170; SOT-23
R501: 22; R_0402_NoSilk
R502: 100; R_0402_NoSilk
R503, R504: 0; R_0402_NoSilk
TP501: TP
U504: A7
U505: SIM_SLOT; SIM

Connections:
4V_BST: C501.1, C502.1, R502.2, U504.41 (VBAT), U504.42 (VBAT); also elsewhere on the board
/Audio Amplifier/AUDIO_IN+: U504.19 (MIC-); also elsewhere on the board
/Audio Amplifier/AUDIO_IN-: U504.20 (MIC+); also elsewhere on the board
/Controller/RADIO_RST: R501.2; also elsewhere on the board
/Radio Module, GPS and SIM/ACTIVE: U504.9 (GPIO1/INT); also elsewhere on the board
/Radio Module, GPS and SIM/AT_UART_CTS: U504.11 (UART_CTS/GPIO7); also elsewhere on the board
/Radio Module, GPS and SIM/AT_UART_RTS: U504.10 (UART_RTS/GPIO5); also elsewhere on the board
/Radio Module, GPS and SIM/AT_UART_RX: U504.31 (UART_RXD); also elsewhere on the board
/Radio Module, GPS and SIM/AT_UART_TX: U504.30 (UART_TXD); also elsewhere on the board
/Radio Module, GPS and SIM/GPS_GND: C504.2, C506.2, U504.2 (GND); also elsewhere on the board
/Radio Module, GPS and SIM/GPS_RF: C506.1, R503.2; also elsewhere on the board
/Radio Module, GPS and SIM/GPS_TX: U504.37 (GPS_TXD); also elsewhere on the board
/Radio Module, GPS and SIM/GSM_GND: C505.2, C507.2, U504.34 (GND), U504.36 (GND); also elsewhere on the board
/Radio Module, GPS and SIM/GSM_RF: C507.1, R504.2; also elsewhere on the board
/Radio Module, GPS and SIM/HP_L: U504.23 (EAR_L)
/Radio Module, GPS and SIM/HP_M: U504.21 (MIC2_P)
/Radio Module, GPS and SIM/HP_R: U504.24 (EAR_R)
/Radio Module, GPS and SIM/HST_RX: U504.32 (HST_RXD); also elsewhere on the board
/Radio Module, GPS and SIM/HST_TX: U504.33 (HST_TXD); also elsewhere on the board
/Radio Module, GPS and SIM/ON: U504.8 (PWR_KEY); also elsewhere on the board
/Radio Module, GPS and SIM/SPK_+: U504.26 (REC+); also elsewhere on the board
/Radio Module, GPS and SIM/SPK_-: U504.27 (REC-); also elsewhere on the board
GND: C501.2, C502.2, C503.2, Q501.2 (S), U504.13 (GND), U504.18 (GND), U504.39 (GND), U504.40 (GND), U505.4 (GND), U505.7 (GND), U505.8 (GND); also elsewhere on the board
GNDA: U504.22 (GND), U504.25 (GND), U504.28 (GND); also elsewhere on the board
NVCC_1V8: C503.1, U504.29 (VDD_1V8_OUT); also elsewhere on the board
unnamed: C504.1, R503.1, U504.1 (GPS_RF)
unnamed: C505.1, R504.1, U504.35 (GSM_RF)
unnamed: Q501.1 (G), R501.1
unnamed: Q501.3 (D), R502.1, TP501.1, U504.12 (RST)
unnamed: U504.14 (SIM_RST), U505.2 (RST)
unnamed: U504.15 (SIM_CLK), U505.3 (CLK)
unnamed: U504.16 (VSIM), U505.1 (VCC)
unnamed: U504.17 (SIM_DATA), U505.6 (IO)

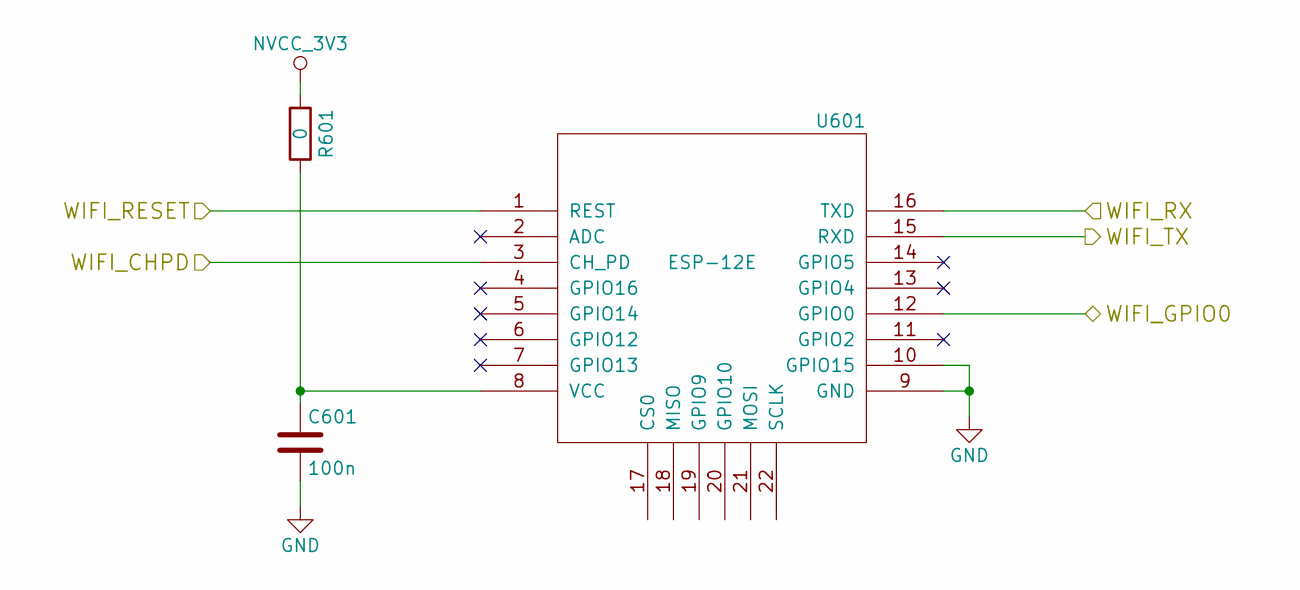
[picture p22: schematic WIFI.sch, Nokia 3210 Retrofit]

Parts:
C601: 100n; C_0402_NoSilk
R601: 0; R_0402_NoSilk
U601: ESP-12E

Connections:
/Controller/USART6_RX: U601.15 (RXD); also elsewhere on the board
/Controller/USART6_TX: U601.16 (TXD); also elsewhere on the board
/Controller/WIFI_BOOT0: U601.12 (GPIO0); also elsewhere on the board
/Controller/WIFI_CHPD: U601.3 (CH_PD); also elsewhere on the board
/Controller/WIFI_RESET: U601.1 (REST); also elsewhere on the board
GND: C601.2, U601.9 (GND), U601.10 (GPIO15); also elsewhere on the board
NVCC_3V3: R601.2; also elsewhere on the board
unnamed: C601.1, R601.1, U601.8 (VCC)

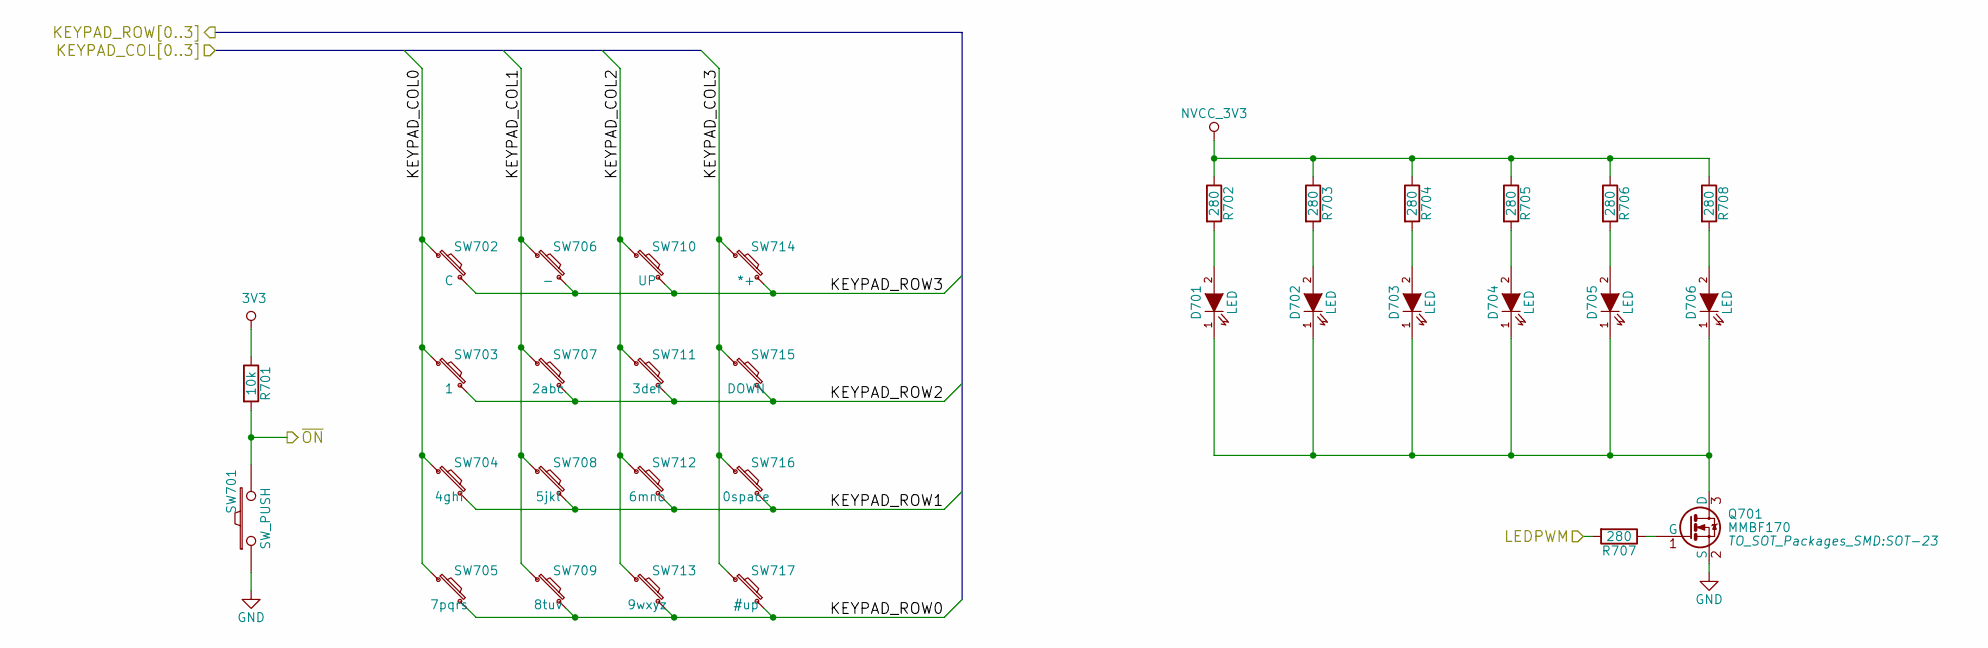
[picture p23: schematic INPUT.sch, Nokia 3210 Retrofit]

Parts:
D701, D702, D703, D704, D705, D706: LED; LED_0603
Q701: MMBF170; SOT-23
R701: 10k; R_0402_NoSilk
R702, R703, R704, R705, R706, R707, R708: 280; R_0402_NoSilk
SW701: SW_PUSH; TS-015A
SW702: C; Foil_Button
SW703: 1; Foil_Button
SW704: 4ghi; Foil_Button
SW705: 7pqrs; Foil_Button
SW706: -; Foil_Button
SW707: 2abc; Foil_Button
SW708: 5jkl; Foil_Button
SW709: 8tuv; Foil_Button
SW710: UP; Foil_Button
SW711: 3def; Foil_Button
SW712: 6mno; Foil_Button
SW713: 9wxyz; Foil_Button
SW714: *+; Foil_Button
SW715: DOWN; Foil_Button
SW716: 0space; Foil_Button
SW717: #up; Foil_Button

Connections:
3V3: R701.1; also elsewhere on the board
/Buttons and LEDs/KEYPAD_COL0: SW702.1, SW703.1, SW704.1, SW705.1; also elsewhere on the board
/Buttons and LEDs/KEYPAD_COL1: SW706.1, SW707.1, SW708.1, SW709.1; also elsewhere on the board
/Buttons and LEDs/KEYPAD_COL2: SW710.1, SW711.1, SW712.1, SW713.1; also elsewhere on the board
/Buttons and LEDs/KEYPAD_COL3: SW714.1, SW715.1, SW716.1, SW717.1; also elsewhere on the board
/Buttons and LEDs/KEYPAD_ROW0: SW705.2, SW709.2, SW713.2, SW717.2; also elsewhere on the board
/Buttons and LEDs/KEYPAD_ROW1: SW704.2, SW708.2, SW712.2, SW716.2; also elsewhere on the board
/Buttons and LEDs/KEYPAD_ROW2: SW703.2, SW707.2, SW711.2, SW715.2; also elsewhere on the board
/Buttons and LEDs/KEYPAD_ROW3: SW702.2, SW706.2, SW710.2, SW714.2; also elsewhere on the board
/Buttons and LEDs/LEDPWM: R707.2; also elsewhere on the board
/Controller/SYS_WKUP: R701.2, SW701.2; also elsewhere on the board
GND: Q701.2 (S), SW701.1; also elsewhere on the board
NVCC_3V3: R702.1, R703.1, R704.1, R705.1, R706.1, R708.1; also elsewhere on the board
unnamed: D701.1 (K), D702.1 (K), D703.1 (K), D704.1 (K), D705.1 (K), D706.1 (K), Q701.3 (D)
unnamed: D701.2 (A), R702.2
unnamed: D702.2 (A), R703.2
unnamed: D703.2 (A), R704.2
unnamed: D704.2 (A), R705.2
unnamed: D705.2 (A), R706.2
unnamed: D706.2 (A), R708.2
unnamed: Q701.1 (G), R707.1

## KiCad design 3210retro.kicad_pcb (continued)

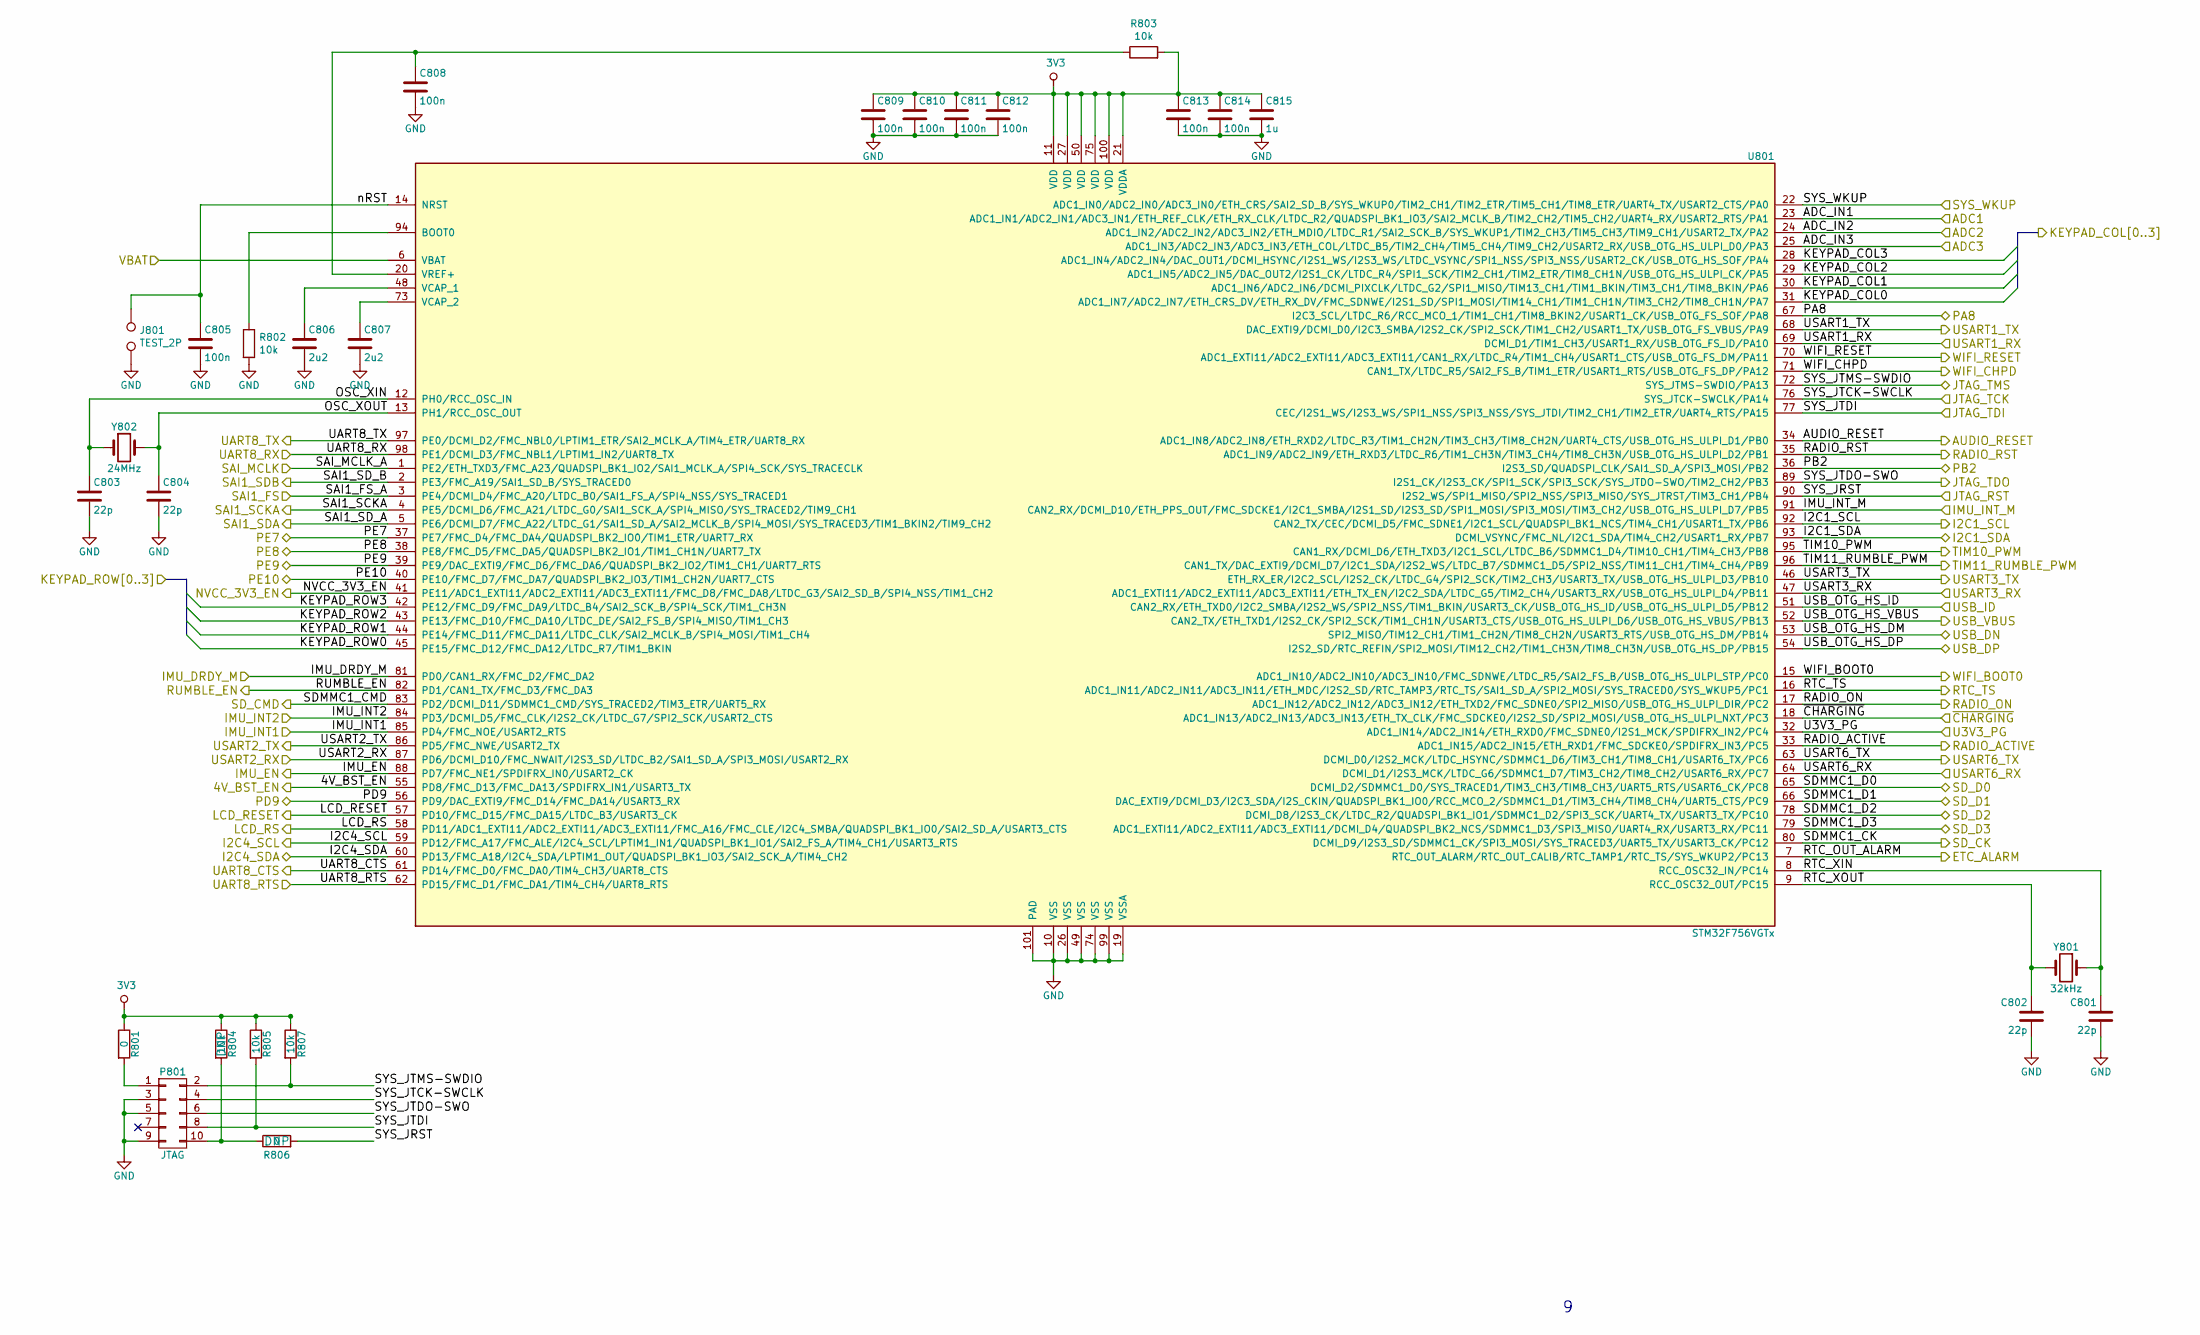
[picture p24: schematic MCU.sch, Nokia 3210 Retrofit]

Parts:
C801, C802, C803, C804: 22p; C_0402_NoSilk
C805, C808, C809, C810, C811, C812, C813, C814: 100n; C_0402_NoSilk
C806, C807: 2u2; C_0402_NoSilk
C815: 1u; C_0402_NoSilk
J801: TEST_2P; SolderWirePad_2x_0,8
P801: JTAG; Pin_Header_Straight_2x05_Pitch1.27mm
R801, R806: 0; R_0402_NoSilk
R802, R803, R804, R805, R807: 10k; R_0402_NoSilk
U801: STM32F756VGTx; TQFP-100-1EP_14x14mm_Pitch0.5mm
Y801: 32kHz; Crystal_SMD_2012-2pin_2.0x1.2mm
Y802: 24MHz; Crystal_SMD_2016-4pin_2.0x1.6mm

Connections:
3V3: C809.1, C810.1, C811.1, C812.1, C813.1, C814.1, C815.1, R801.1, R803.2, R804.1, R805.1, R807.1, U801.11 (VDD), U801.21 (VDDA), U801.27 (VDD), U801.50 (VDD), U801.75 (VDD), U801.100 (VDD); also elsewhere on the board
+5V: U801.52 (CAN2_TX/ETH_TXD1/I2S2_CK/SPI2_SCK/TIM1_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); also elsewhere on the board
/Audio Amplifier/AUDIO_I2C_SCL: U801.59 (PD12/FMC_A17/FMC_ALE/I2C4_SCL/LPTIM1_IN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); also elsewhere on the board
/Audio Amplifier/AUDIO_I2C_SDA: U801.60 (PD13/FMC_A18/I2C4_SDA/LPTIM1_OUT/QUADSP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); also elsewhere on the board
/Audio Amplifier/AUDIO_RESET: U801.34 (ADC1_IN8/ADC2_IN8/ETH_RXD2/LTDC_R3/TIM1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); also elsewhere on the board
/Audio Amplifier/RMBL_EN: U801.82 (PD1/CAN1_TX/FMC_D3/FMC_DA3); also elsewhere on the board
/Audio Amplifier/RMBL_PWM: U801.96 (CAN1_TX/DAC_EXTI9/DCMI_D7/I2C1_SDA/I2S2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); also elsewhere on the board
/Buttons and LEDs/KEYPAD_COL0: U801.31 (ADC1_IN7/ADC2_IN7/ETH_CRS_DV/ETH_RX_DV/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); also elsewhere on the board
/Buttons and LEDs/KEYPAD_COL1: U801.30 (ADC1_IN6/ADC2_IN6/DCMI_PIXCLK/LTDC_G2/S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); also elsewhere on the board
/Buttons and LEDs/KEYPAD_COL2: U801.29 (ADC1_IN5/ADC2_IN5/DAC_OUT2/I2S1_CK/LTDC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); also elsewhere on the board
/Buttons and LEDs/KEYPAD_COL3: U801.28 (ADC1_IN4/ADC2_IN4/DAC_OUT1/DCMI_HSYNC/I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); also elsewhere on the board
/Buttons and LEDs/KEYPAD_ROW0: U801.45 (PE15/FMC_D12/FMC_DA12/LTDC_R7/TIM1_BKIN); also elsewhere on the board
/Buttons and LEDs/KEYPAD_ROW1: U801.44 (PE14/FMC_D11/FMC_DA11/LTDC_CLK/SAI2_MCL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); also elsewhere on the board
/Buttons and LEDs/KEYPAD_ROW2: U801.43 (PE13/FMC_D10/FMC_DA10/LTDC_DE/SAI2_FS_B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); also elsewhere on the board
/Buttons and LEDs/KEYPAD_ROW3: U801.42 (PE12/FMC_D9/FMC_DA9/LTDC_B4/SAI2_SCK_B/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); also elsewhere on the board
/Buttons and LEDs/LEDPWM: U801.95 (CAN1_RX/DCMI_D6/ETH_TXD3/I2C1_SCL/LTDC_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); also elsewhere on the board
/Controller/4V_BST_EN: U801.55 (PD8/FMC_D13/FMC_DA13/SPDIFRX_IN1/USART3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); also elsewhere on the board
/Controller/ADC1: U801.23 (ADC1_IN1/ADC2_IN1/ADC3_IN1/ETH_REF_CLK/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); also elsewhere on the board
/Controller/ADC2: U801.24 (ADC1_IN2/ADC2_IN2/ADC3_IN2/ETH_MDIO/LTD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); also elsewhere on the board
/Controller/ADC3: U801.25 (ADC1_IN3/ADC2_IN3/ADC3_IN3/ETH_COL/LTDC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); also elsewhere on the board
/Controller/ETC_ALARM: U801.7 (RTC_OUT_ALARM/RTC_OUT_CALIB/RTC_TAMP1/R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); also elsewhere on the board
/Controller/I2C1_SCL: U801.92 (CAN2_TX/CEC/DCMI_D5/FMC_SDNE1/I2C1_SCL/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); also elsewhere on the board
/Controller/I2C1_SDA: U801.93 (DCMI_VSYNC/FMC_NL/I2C1_SDA/TIM4_CH2/USA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); also elsewhere on the board
/Controller/IMU_DRDY_M: U801.81 (PD0/CAN1_RX/FMC_D2/FMC_DA2); also elsewhere on the board
/Controller/IMU_EN: U801.88 (PD7/FMC_NE1/SPDIFRX_IN0/USART2_CK); also elsewhere on the board
/Controller/IMU_INT1: U801.85 (PD4/FMC_NOE/USART2_RTS); also elsewhere on the board
/Controller/IMU_INT2: U801.84 (PD3/DCMI_D5/FMC_CLK/I2S2_CK/LTDC_G7/SPI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); also elsewhere on the board
/Controller/IMU_INT_M: U801.91 (CAN2_RX/DCMI_D10/ETH_PPS_OUT/FMC_SDCKE1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); also elsewhere on the board
/Controller/JTAG_RST: R806.2, U801.90 (I2S2_WS/SPI1_MISO/SPI2_NSS/SPI3_MISO/SY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)
/Controller/JTAG_TCK: P801.4, U801.76 (SYS_JTCK-SWCLK/PA14)
/Controller/JTAG_TDI: P801.8, R805.2, U801.77 (CEC/I2S1_WS/I2S3_WS/SPI1_NSS/SPI3_NSS/S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)
/Controller/JTAG_TDO: P801.6, U801.89 (I2S1_CK/I2S3_CK/SPI1_SCK/SPI3_SCK/SYS_J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)
/Controller/JTAG_TMS: P801.2, R807.2, U801.72 (SYS_JTMS-SWDIO/PA13)
/Controller/LCD_RESET: U801.57 (PD10/FMC_D15/FMC_DA15/LTDC_B3/USART3_CK); also elsewhere on the board
/Controller/LCD_RS: U801.58 (PD11/ADC1_EXTI11/ADC2_EXTI11/ADC3_EXTI1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); also elsewhere on the board
/Controller/NVCC_3V3_EN: U801.41 (PE11/ADC1_EXTI11/ADC2_EXTI11/ADC3_EXTI1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); also elsewhere on the board
/Controller/OSC_XIN: C803.1, U801.12 (PH0/RCC_OSC_IN), Y802.1
/Controller/OSC_XOUT: C804.1, U801.13 (PH1/RCC_OSC_OUT), Y802.2
/Controller/PA8: U801.67 (I2C3_SCL/LTDC_R6/RCC_MCO_1/TIM1_CH1/TIM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); also elsewhere on the board
/Controller/PB2: U801.36 (I2S3_SD/QUADSPI_CLK/SAI1_SD_A/SPI3_MOSI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); also elsewhere on the board
/Controller/PD9: U801.56 (PD9/DAC_EXTI9/FMC_D14/FMC_DA14/USART3_RX); also elsewhere on the board
/Controller/PE7: U801.37 (PE7/FMC_D4/FMC_DA4/QUADSPI_BK2_IO0/TIM1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); also elsewhere on the board
/Controller/PE8: U801.38 (PE8/FMC_D5/FMC_DA5/QUADSPI_BK2_IO1/TIM1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); also elsewhere on the board
/Controller/PE9: U801.39 (PE9/DAC_EXTI9/FMC_D6/FMC_DA6/QUADSPI_BK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); also elsewhere on the board
/Controller/PE10: U801.40 (PE10/FMC_D7/FMC_DA7/QUADSPI_BK2_IO3/TIM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); also elsewhere on the board
/Controller/RADIO_RST: U801.35 (ADC1_IN9/ADC2_IN9/ETH_RXD3/LTDC_R6/TIM1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); also elsewhere on the board
/Controller/RTC_TS: U801.16 (ADC1_IN11/ADC2_IN11/ADC3_IN11/ETH_MDC/I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); also elsewhere on the board
/Controller/RTC_XIN: C801.1, U801.8 (RCC_OSC32_IN/PC14), Y801.1
/Controller/RTC_XOUT: C802.1, U801.9 (RCC_OSC32_OUT/PC15), Y801.2
/Controller/SAI1_FS: U801.3 (PE4/DCMI_D4/FMC_A20/LTDC_B0/SAI1_FS_A/S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); also elsewhere on the board
/Controller/SAI1_SCKA: U801.4 (PE5/DCMI_D6/FMC_A21/LTDC_G0/SAI1_SCK_A/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); also elsewhere on the board
/Controller/SAI1_SDA: U801.5 (PE6/DCMI_D7/FMC_A22/LTDC_G1/SAI1_SD_A/S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); also elsewhere on the board
/Controller/SAI1_SDB: U801.2 (PE3/FMC_A19/SAI1_SD_B/SYS_TRACED0); also elsewhere on the board
/Controller/SAI_MCLK: U801.1 (PE2/ETH_TXD3/FMC_A23/QUADSPI_BK1_IO2/SA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); also elsewhere on the board
/Controller/SD_CK: U801.80 (DCMI_D9/I2S3_SD/SDMMC1_CK/SPI3_MOSI/SYS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); also elsewhere on the board
/Controller/SD_CMD: U801.83 (PD2/DCMI_D11/SDMMC1_CMD/SYS_TRACED2/TIM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); also elsewhere on the board
/Controller/SD_D0: U801.65 (DCMI_D2/SDMMC1_D0/SYS_TRACED1/TIM3_CH3/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); also elsewhere on the board
/Controller/SD_D1: U801.66 (DAC_EXTI9/DCMI_D3/I2C3_SDA/I2S_CKIN/QUA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); also elsewhere on the board
/Controller/SD_D2: U801.78 (DCMI_D8/I2S3_CK/LTDC_R2/QUADSPI_BK1_IO1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); also elsewhere on the board
/Controller/SD_D3: U801.79 (ADC1_EXTI11/ADC2_EXTI11/ADC3_EXTI11/DCM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); also elsewhere on the board
/Controller/SYS_WKUP: U801.22 (ADC1_IN0/ADC2_IN0/ADC3_IN0/ETH_CRS/SAI2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); also elsewhere on the board
/Controller/USART1_TX: U801.68 (DAC_EXTI9/DCMI_D0/I2C3_SMBA/I2S2_CK/SPI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); also elsewhere on the board
/Controller/USART3_RX: U801.47 (ADC1_EXTI11/ADC2_EXTI11/ADC3_EXTI11/ETH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); also elsewhere on the board
/Controller/USART3_TX: U801.46 (ETH_RX_ER/I2C2_SCL/I2S2_CK/LTDC_G4/SPI2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); also elsewhere on the board
/Controller/USART6_RX: U801.64 (DCMI_D1/I2S3_MCK/LTDC_G6/SDMMC1_D7/TIM3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); also elsewhere on the board
/Controller/USART6_TX: U801.63 (DCMI_D0/I2S2_MCK/LTDC_HSYNC/SDMMC1_D6/T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); also elsewhere on the board
/Controller/USB_DN: U801.53 (SPI2_MISO/TIM12_CH1/TIM1_CH2N/TIM8_CH2N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); also elsewhere on the board
/Controller/USB_DP: U801.54 (I2S2_SD/RTC_REFIN/SPI2_MOSI/TIM12_CH2/T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); also elsewhere on the board
/Controller/USB_ID: U801.51 (CAN2_RX/ETH_TXD0/I2C2_SMBA/I2S2_WS/SPI2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); also elsewhere on the board
/Controller/VBAT: U801.6 (VBAT); also elsewhere on the board
/Controller/WIFI_BOOT0: U801.15 (ADC1_IN10/ADC2_IN10/ADC3_IN10/FMC_SDNWE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); also elsewhere on the board
/Controller/WIFI_CHPD: U801.71 (CAN1_TX/LTDC_R5/SAI2_FS_B/TIM1_ETR/USAR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); also elsewhere on the board
/Controller/WIFI_RESET: U801.70 (ADC1_EXTI11/ADC2_EXTI11/ADC3_EXTI11/CAN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); also elsewhere on the board
/Controller/nRST: C805.1, J801.1, U801.14 (NRST)
/Controller/~CHARGING: U801.18 (ADC1_IN13/ADC2_IN13/ADC3_IN13/ETH_TX_CL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); also elsewhere on the board
/Power and Battery/3V3_PG: U801.32 (ADC1_IN14/ADC2_IN14/ETH_RXD0/FMC_SDNE0/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); also elsewhere on the board
/Radio Module, GPS and SIM/ACTIVE: U801.33 (ADC1_IN15/ADC2_IN15/ETH_RXD1/FMC_SDCKE0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); also elsewhere on the board
/Radio Module, GPS and SIM/AT_UART_CTS: U801.62 (PD15/FMC_D1/FMC_DA1/TIM4_CH4/UART8_RTS); also elsewhere on the board
/Radio Module, GPS and SIM/AT_UART_RTS: U801.61 (PD14/FMC_D0/FMC_DA0/TIM4_CH3/UART8_CTS); also elsewhere on the board
/Radio Module, GPS and SIM/AT_UART_RX: U801.97 (PE0/DCMI_D2/FMC_NBL0/LPTIM1_ETR/SAI2_MC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); also elsewhere on the board
/Radio Module, GPS and SIM/AT_UART_TX: U801.98 (PE1/DCMI_D3/FMC_NBL1/LPTIM1_IN2/UART8_TX); also elsewhere on the board
/Radio Module, GPS and SIM/GPS_TX: U801.69 (DCMI_D1/TIM1_CH3/USART1_RX/USB_OTG_FS_I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); also elsewhere on the board
/Radio Module, GPS and SIM/HST_RX: U801.86 (PD5/FMC_NWE/USART2_TX); also elsewhere on the board
/Radio Module, GPS and SIM/HST_TX: U801.87 (PD6/DCMI_D10/FMC_NWAIT/I2S3_SD/LTDC_B2/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); also elsewhere on the board
/Radio Module, GPS and SIM/ON: U801.17 (ADC1_IN12/ADC2_IN12/ADC3_IN12/ETH_TXD2/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); also elsewhere on the board
GND: C801.2, C802.2, C803.2, C804.2, C805.2, C806.2, C807.2, C808.2, C809.2, C810.2, C811.2, C812.2, C813.2, C814.2, C815.2, J801.2, P801.3, P801.5, P801.9, R802.2, U801.10 (VSS), U801.19 (VSSA), U801.26 (VSS), U801.49 (VSS), U801.74 (VSS), U801.99 (VSS), U801.101 (PAD); also elsewhere on the board
unnamed: C806.1, U801.48 (VCAP_1)
unnamed: C807.1, U801.73 (VCAP_2)
unnamed: C808.1, R803.1, U801.20 (VREF+)
unnamed: P801.1, R801.2
unnamed: P801.10, R804.2, R806.1
unnamed: R802.1, U801.94 (BOOT0)

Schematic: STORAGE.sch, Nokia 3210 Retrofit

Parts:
J1101: MICRO_SD_HINGE; microSD_Card_Receptacle_Wuerth_693072010801

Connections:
/Controller/SD_CK: J1101.5 (CLK); also elsewhere on the board
/Controller/SD_CMD: J1101.3 (CMD); also elsewhere on the board
/Controller/SD_D0: J1101.7 (DAT0); also elsewhere on the board
/Controller/SD_D1: J1101.8 (DAT1); also elsewhere on the board
/Controller/SD_D2: J1101.1 (DAT2); also elsewhere on the board
/Controller/SD_D3: J1101.2 (CD/DAT3); also elsewhere on the board
GND: J1101.6 (VSS), J1101.9 (GND1), J1101.10 (GND2), J1101.11 (GND3), J1101.12 (GND4); also elsewhere on the board
NVCC_3V3: J1101.4 (VDD); also elsewhere on the board

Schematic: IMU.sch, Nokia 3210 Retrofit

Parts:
C1308: 10n; C_0402_NoSilk
C1309: 100n; C_0402_NoSilk
U1301: LSM9DS1; LGA-24L_3x3.5mm_Pitch0.43mm

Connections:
/Audio Amplifier/AUDIO_I2C_SCL: U1301.2 (SCL/SPC); also elsewhere on the board
/Audio Amplifier/AUDIO_I2C_SDA: U1301.4 (SDA/SDI/SDO); also elsewhere on the board
/Controller/IMU_DRDY_M: U1301.9 (DRDY_M); also elsewhere on the board
/Controller/IMU_EN: U1301.13 (DEN_A/G); also elsewhere on the board
/Controller/IMU_INT1: U1301.11 (INT1_A/G); also elsewhere on the board
/Controller/IMU_INT2: U1301.12 (INT2_A/G); also elsewhere on the board
/Controller/IMU_INT_M: U1301.10 (INT_M); also elsewhere on the board
GND: C1308.2, C1309.2, U1301.5 (SDO_AG), U1301.6 (SDO_M), U1301.14 (RES), U1301.15 (RES), U1301.16 (RES), U1301.17 (RES), U1301.18 (RES), U1301.19 (GND), U1301.20 (GND); also elsewhere on the board
NVCC_3V3: U1301.1 (VDDIO), U1301.3 (VDDIO), U1301.7 (CS_A/G), U1301.8 (CS_M), U1301.22 (VDD), U1301.23 (VDD); also elsewhere on the board
unnamed: C1308.1, U1301.21 (CAP)
unnamed: C1309.1, U1301.24 (C1)

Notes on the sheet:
LSB for I2C address

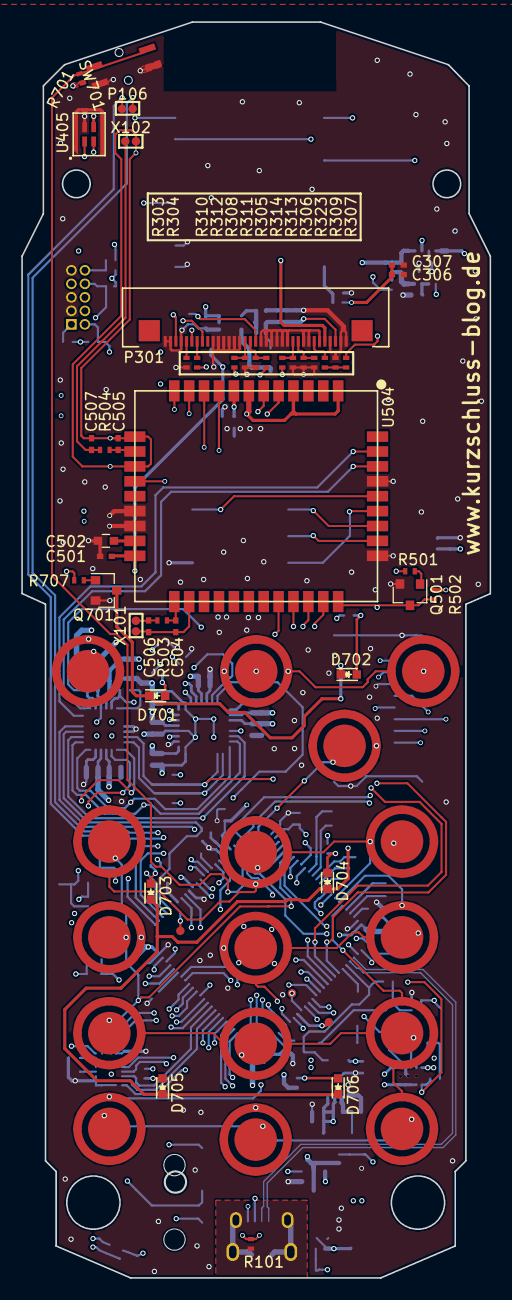
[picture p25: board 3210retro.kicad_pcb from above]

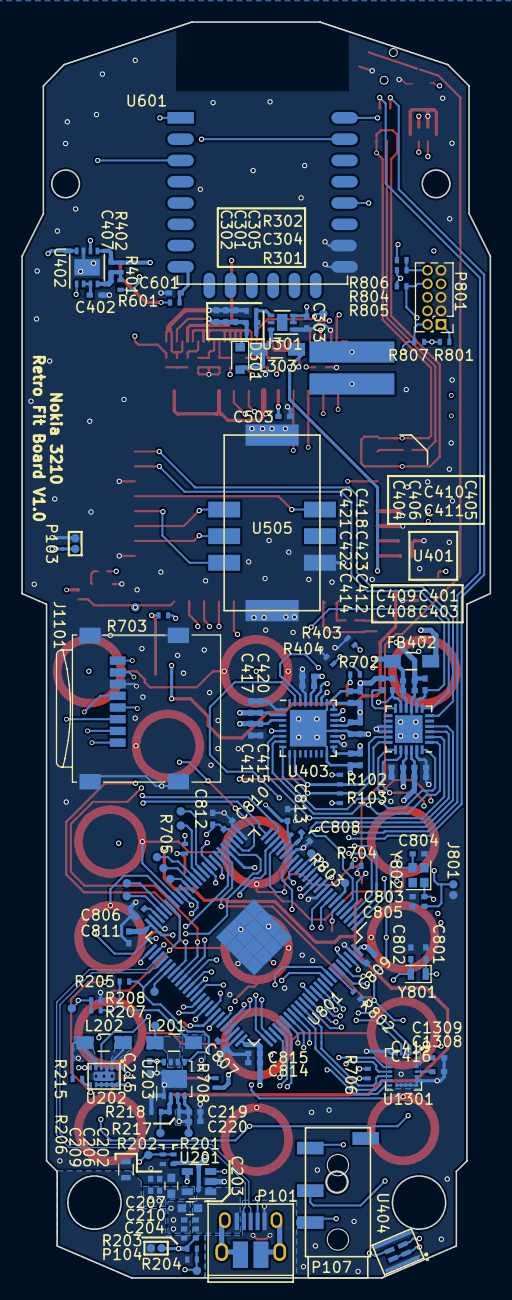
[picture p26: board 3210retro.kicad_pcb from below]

Board: 6 copper layers, 44.0 x 118.0 mm, 197 parts (120 on the bottom side), 155 nets.

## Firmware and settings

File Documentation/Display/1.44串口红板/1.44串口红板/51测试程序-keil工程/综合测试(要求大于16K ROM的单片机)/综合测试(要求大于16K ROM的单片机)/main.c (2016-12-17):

#include <reg51.h>
#include <intrins.h>
#include <sys\sys.h>
#include <lcd\lcd.h>
#include <font\font.h>
/* 
程序默认IO连接方式：
sbit LCD_CS     =P0^0;     //片选	
sbit LCD_AO     =P0^2;	  //数据/命令切换
sbit LCD_SDA    =P1^5;	  //数据
sbit LCD_SCK    =P1^7;	  //时钟
sbit LCD_REST   =P0^1;	  //复位  
*/ 
void xianshi()//显示信息
{   
	BACK_COLOR=WHITE;
	POINT_COLOR=RED;	
	showhanzi(10,0,0);  //晶
	showhanzi(45,0,1);  //耀
    LCD_ShowString(10,30,"1.44 inch TFT");
	LCD_ShowString(10,48,"128*128");
}
void showimage() //显示40*40图片
{
  	int i,j,k;
	xianshi(); //显示信息
	for(k=2;k<3;k++)
	{
	   	for(j=0;j<3;j++)
		{	
			Address_set(40*j,40*k,40*j+39,40*k+39);		//坐标设置
		    for(i=0;i<1600;i++)
			 {				
			  	 LCD_WR_DATA8(image[i*2+1]);	 //发送颜色数据
				 LCD_WR_DATA8(image[i*2]);					
			 }	
		 }
	}
		
}
main()
{ 
	Lcd_Init();   //tft初始化
	LCD_Clear(WHITE); //清屏
	BACK_COLOR=BLACK;;POINT_COLOR=WHITE; 
    showimage(); //显示40*40图片

	while(1)
	{
	 
//	Lcd_Init();   //tft初始化
//	LCD_Clear(WHITE); //清屏
//	BACK_COLOR=BLACK;;POINT_COLOR=WHITE; 
 //  showimage(); //显示40*40图片
//	delayms(2000);
    }


}

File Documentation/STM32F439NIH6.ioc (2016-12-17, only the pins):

Mcu.UserName=STM32F429NIHx
PA0/WKUP.Signal=UART4_TX
PA1.Signal=UART4_RX
PA11.Signal=USART1_CTS
PA12.Signal=USART1_RTS
PA13.Signal=SYS_JTMS-SWDIO
PA14.Signal=SYS_JTCK-SWCLK
PA15.Signal=SYS_JTDI
PA2.Signal=USART2_TX
PA4.Signal=USB_OTG_HS_SOF
PA5.Signal=COMP_DAC2_group
PB12.Signal=USB_OTG_HS_ID
PB13.Signal=USB_OTG_HS_VBUS
PB14.Signal=USB_OTG_HS_DM
PB15.Signal=USB_OTG_HS_DP
PB3.Signal=SYS_JTDO-SWO
PB4.Signal=SYS_JTRST
PB6.Signal=USART1_TX
PB7.Signal=USART1_RX
PB8.Signal=I2C1_SCL
PB9.Signal=I2C1_SDA
PC0.Signal=ADCx_IN10
PC1.Signal=ADCx_IN11
PC10.Signal=SDIO_D2
PC11.Signal=SDIO_D3
PC12.Signal=SDIO_CK
PC14/OSC32_IN.Signal=RCC_OSC32_IN
PC15/OSC32_OUT.Signal=RCC_OSC32_OUT
PC2.Signal=ADCx_IN12
PC3.Signal=ADCx_IN13
PC4.Signal=ADCx_IN14
PC5.Signal=ADCx_IN15
PC8.Signal=SDIO_D0
PC9.Signal=SDIO_D1
PD0.Signal=FMC_D2_DA2
PD1.Signal=FMC_D3_DA3
PD10.Signal=FMC_D15_DA15
PD11.Signal=FMC_A16_CLE
PD12.Signal=FMC_A17_ALE
PD13.Signal=FMC_A18
PD14.Signal=FMC_D0_DA0
PD15.Signal=FMC_D1_DA1
PD2.Signal=SDIO_CMD
PD3.Signal=USART2_CTS
PD4.Signal=FMC_NOE
PD5.Signal=FMC_NWE
PD6.Signal=USART2_RX
PD7.Signal=FMC_NE1
PD8.Signal=FMC_D13_DA13
PD9.Signal=FMC_D14_DA14
PE0.Signal=FMC_NBL0
PE1.Signal=FMC_NBL1
PE10.Signal=FMC_D7_DA7
PE11.Signal=FMC_D8_DA8
PE12.Signal=FMC_D9_DA9
PE13.Signal=FMC_D10_DA10
PE14.Signal=FMC_D11_DA11
PE15.Signal=FMC_D12_DA12
PE2.Signal=FMC_A23
PE3.Signal=FMC_A19
PE4.Signal=FMC_A20
PE5.Signal=FMC_A21
PE6.Signal=FMC_A22
PE7.Signal=FMC_D4_DA4
PE8.Signal=FMC_D5_DA5
PE9.Signal=FMC_D6_DA6
PF0.Signal=FMC_A0
PF1.Signal=FMC_A1
PF11.Signal=FMC_SDNRAS
PF12.Signal=FMC_A6
PF13.Signal=FMC_A7
PF14.Signal=FMC_A8
PF15.Signal=FMC_A9
PF2.Signal=FMC_A2
PF3.Signal=FMC_A3
PF4.Signal=FMC_A4
PF5.Signal=FMC_A5
PF6.Signal=UART7_RX
PF7.Signal=UART7_TX
PG0.Signal=FMC_A10
PG1.Signal=FMC_A11
PG13.Signal=FMC_A24
PG14.Signal=FMC_A25
PG15.Signal=FMC_SDNCAS
PG2.Signal=FMC_A12
PG3.Signal=FMC_A13
PG4.Signal=FMC_A14_BA0
PG5.Signal=FMC_A15_BA1
PG8.Signal=FMC_SDCLK
PG9.Signal=GPXTI9
PH0/OSC_IN.Signal=RCC_OSC_IN
PH1/OSC_OUT.Signal=RCC_OSC_OUT
PH2.Signal=FMC_SDCKE0
PH3.Signal=FMC_SDNE0
PH5.Signal=FMC_SDNWE
PI0.Signal=SPI2_NSS
PI1.Signal=SPI2_SCK
PI2.Signal=SPI2_MISO
PI3.Signal=SPI2_MOSI

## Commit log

2016-12-17 Initial schematics of Nokia Retrofit Board
    - Power available:
    * USB_VBUS
    * VBAT
    * 4V
    * 3V3
    - Display: SPI 1.44"
    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
    [3310retro.kicad_pcb, 3310retro.sch, AMPLIFIER.sch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]
2016-12-17 Schematics: - Added STZM32 MCU for the CPU kernel - Added ESP8266 for WiFi Subsheet
    Firmware:
    - Generated BIOS configuration for CubeMX
    [3310retro.sch, AMPLIFIER.sch, DISPLAY.sch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]
2016-12-17 current version of the schematics. Audio circuits are still missing.
    Audio curcuit topology
    Audio from cellphone module is routed to STM
    Audio from microphone is routed to STM
    STM processes audio and routes microphone data to cellphone module
    STM processes audio and routes cellphone audio to amplifier
    analog multiplexer can switch route from mic directly to cellphone module and module to speaker
    [3310retro.kicad_pcb, 3310retro.sch, AMPLIFIER.sch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]
2016-12-20 added Ti WL1807/1837 Module for WLAN and Bluetooth. added Test Points
    [3210retro.kicad_pcb, 3210retro.sch, AMPLIFIER.sch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]
2016-12-21 short schematics review and proposed changes
    [DISPLAY.sch, POWER.sch, RADIO.sch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]
2016-12-22 moved to some Bus routing for serveral communication signals on the top sheet. This reduces lines on the top sheet.
    Changed 4V boost converter circuit toi use TPS61046 for size reasons
    [3210retro.sch, AMPLIFIER.sch, DISPLAY.sch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]
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2017-01-26 display placement
    The placement of the display connector is set.
    [3210retro.kicad_pcb, 3210retro.sch, AMPLIFIER.sch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]
2017-01-27 added some audio circuitry
    [3210retro.sch, AMPLIFIER.sch, DISPLAY.sch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]
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2017-03-01 Added Interface for OLED display
    Added Booster for 4V -> 15V
    Added bus for display data
    [3210retro.sch, AMPLIFIER.sch, DISPLAY.sch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]
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2017-05-18 finished DDR3L RAM for 1GB with 2 banks
    [ADC_GPIO.sch, CPU.sch, CPU_POWER.sch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]
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2017-05-21 placed leds and corrected measurements
    [3210retro.kicad_pcb]
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2017-05-26 Added some schematics for PMIC Added some Documentation for i.mx7
    [ADC_GPIO.sch, CPU.sch, CPU_POWER.sch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]
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2017-06-11 started working on implementing i.MX7 core into base schematic
    [3210retro.sch, ADC_GPIO.sch, AMPLIFIER.sch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]
2017-06-11 fixed message telling to rescue PF3000 symbol while opening the schematic
    [3210retro.sch, AMPLIFIER.sch, DISPLAY.sch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]
2017-06-14 Put key matrix into schematic. Using Keypad Peripheral of i.MX7
    [3210retro.sch, AMPLIFIER.sch, DISPLAY.sch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]
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2017-06-15 added emif06 datasheet added STORAGE subsheet revert WIFI.sch to version with WL1807MOD
    [STORAGE.sch, WIFI.sch]
2017-06-15 Connected WIFI subsheet with ESP8266 and WL1807MOD to SD2 Connected WL1807MOD Bluetoth UART to UART3 Connected A7 Module AT UART to UART6 Connected A7 GPS UART to UART5 Connected A7 HS download to UA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
    [3210retro.sch, AMPLIFIER.sch, CPU_PWR.sch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]
2017-06-15 Moved USB into it's own subsheet shuffeld stuff around to make it less crammed
    [3210retro.sch, AMPLIFIER.sch, CPU_PWR.sch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]
2017-06-15 renamed USB.sch to USB_IMU.sch added LSM9DS1 IMU to USB_IMU.sch and connected I2C2 bus shuffeld stuff around to make MCU.sch less crammed
    [3210retro.sch, AMPLIFIER.sch, CPU_PWR.sch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]
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2017-06-17 Trying out a new Topsheet for page index, power tree diagram and a picture
    [3210retro.sch, AMPLIFIER.sch, CPU_PWR.sch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]
2017-06-17 reverting to old sheet structure
    [3210retro.sch, AMPLIFIER.sch, CPU_PWR.sch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]
2017-06-18 removed i.MX7_Test project since the i.MX7 kernel is transfered to the main schematic now
    [ADC_GPIO.sch, CPU.sch, CPU_POWER.sch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]
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2017-06-30 Prepare for two battery types NiMH battery for using the original battery pack LiPo battery for using long lasting modern battery
    [3210retro.sch, AMPLIFIER.sch, CPU_PWR.sch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]
2017-07-02 Added power domains overview in POWER.sch subsheet fixed some power connections added datasheet for bq24401 charge controller updated schematic library
    [INPUT.sch, PMIC.sch, POWER.sch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]
2017-07-02 Modified power domain overview to contain tree of power rails updated schematic lib reference
    [POWER.sch]
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2017-07-08 Changed several voltage rail connections Removed non existing rails Added circuit for NiMH charging
    [3210retro.sch, AMPLIFIER.sch, CPU_PWR.sch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]
2017-07-09 Changed SPI group voltage rail to 2V8 Changed EPDC2 group voltage rail to 2V8
    [MCU.sch, RADIO.sch]
2017-07-19 Created netlist with current components Foreward Annotation to Board
    [3210retro.kicad_pcb, 3210retro.sch, AMPLIFIER.sch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]
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2017-08-13 Startet routing DDR3. Some things need to be cleared before routign process an begin
    [3210retro.kicad_pcb, 3210retro.sch, AMPLIFIER.sch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]
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2017-08-15 Routing DDR3: placing caps close to power nets
    [3210retro.kicad_pcb]
2017-08-27 Added several via stacks for i.MX7 GND via Micro-Burried-Micro-Micro from GND_TOP to B.Cu
    [3210retro.kicad_pcb]
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2017-09-06 This branch moves from i.mx7 to STM32F4 CPU to be finished for Hackaday Prize 2017
    [3210retro.kicad_pcb, 3210retro.sch, AMPLIFIER.sch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]
2017-09-07 Modification for STM32 adaption
    For the Hackaday Prize 2017 I decided to switch to STM32 as CPU
    *Power system was modified to just contain the charge IC,
    *Boost converter for high voltage peripherals
    *Buck converter for 3V3 for CPU and switchable NVCC_3V3
    for peripherie
    CPU signals are routed and pinmux is done in firmware folder.
    SD-Card has 4bit Interface
    WiFi module ESP8266 is connected via UART
    Wolfson Ausio codec is connected via SAI
    Two digital microphones for noise canceling
    Rumble Motor driver
    LCD is connected via it's own I2C interface
    [3210retro.sch, AMPLIFIER.sch, DISPLAY.sch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]
2017-09-08 Placed a lot of components and routed the audio codec
    The BGA of tha audio chipset is to small for regualr technology.
    We do not use all of the pins of the chip so we ignore the other
    pads and escape throug the balls of the other pad.
    [3210retro.kicad_pcb, 3210retro.sch, AMPLIFIER.sch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]
2017-09-10 Revision 1 of Layout
    6layer board
    through-hole via only (0.5/0.3mm drill)
    0.2mm track width
    https://hackaday.io/project/21263-nokia-3210-retro-fit-board/log/66914-prototype-pcb-done-there-comes-the-review
    [3210retro.dsn, 3210retro.kicad_pcb, 3210retro.sch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]
2017-09-14 Board modified to actual measurements
    * rumble motor was on the wrong side of the board. fixed
    * some drill holes where missing
    * moved voice mic to bottom side. top side is completely
    enclosed by the case
    * several small fixes
    [3210retro.kicad_pcb, 3210retro.sch, AMPLIFIER.sch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]
2017-09-14 fix for several signals
    * some signals where not routed out to the top sheet.
    * I2C signals where not connected.
    * moved imu subsheet to the other side of the mcu sheet to
    share I2C bus with audio
    * changed footprint of crystals to crystals I have
    [3210retro.sch, AMPLIFIER.sch, IMU.sch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]
2017-09-14 Board Revision 1
    * Modified layout of I2C busses
    * Added Micro SD footprint back in
    * changed layout of crystals
    [3210retro.kicad_pcb, 3210retro.sch, AMPLIFIER.sch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]
2017-09-17 changed sound subsystem
    rerouted all the changed tracks
    [3210retro.kicad_pcb, 3210retro.sch, AMPLIFIER.sch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]
2017-09-18 worked on DRC messages
    * shuffeling tracks around to avoid vias
    * shuffeling vias around to avoid tracks
    [3210retro.kicad_pcb]
2017-09-24 finalized borad further
    placed more GND vias
    make 4V_BST switchable
    connect GND and GNDREF through resistor
    [3210retro.csv, 3210retro.kicad_pcb, 3210retro.sch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]
2017-11-25 Current version that was ordered as board version 1
    [3210retro.csv, 3210retro.kicad_pcb, 3210retro.ods]
